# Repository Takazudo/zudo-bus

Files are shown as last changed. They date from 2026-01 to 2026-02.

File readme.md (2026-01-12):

# Eurorack Bus Board (zudo-bus)

A bus board for distributing power from USB-PD power supply to Eurorack modular synthesizer modules.

## Documentation

**Main documentation is in the `/doc/` Docusaurus site**

```bash
cd doc
pnpm install
pnpm start
```

Open http://localhost:3333 in your browser to view the documentation.

## Project Overview

### Design Goals

Bus board for distributing power from zudo-pd USB-PD power supply to Eurorack modules.

- **Input**: Screw terminal connection (+12V, -12V, +5V, GND)
- **Output**: Multiple 16-pin IDC headers (Eurorack standard)
- **Capacity**: 8-12 module connections
- **Indicators**: LED status for each power rail

### Features

1. **Screw Terminal Input** - Easy connection from USB-PD power supply
2. **Multiple IDC Headers** - Standard Eurorack 16-pin connectors
3. **Per-Rail Protection** - Reverse polarity and overcurrent protection
4. **Visual Feedback** - LED indicators for power status
5. **JLCPCB Compatible** - All parts available from JLCPCB

## Repository Structure

- `/doc/` - Docusaurus documentation site **<- Main documentation**
- `/__inbox/` - Working directory (gitignored, temporary files)

## Related Projects

- [zudo-pd](https://github.com/Takazudo/zudo-pd) - USB-PD power supply that powers this bus board

## License

This project is open source. Hardware design files are free to use and modify.

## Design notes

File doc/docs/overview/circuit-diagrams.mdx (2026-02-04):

---
sidebar_position: 3
---

# Circuit Diagrams

Complete circuit configuration shown in stages. Each diagram represents a functional block of the zudo-bus power distribution board.

## Power Flow Overview

This diagram shows the complete power distribution chain from input terminals to IDC module headers, including the relationship between all circuit diagrams.

```mermaid
flowchart TD
    IN["Power Input
    Diagram1
    P1, P2 Screw Terminals"]

    PROT12["Protection +12V
    Diagram2
    F1 → D1 TVS → D2"]

    PROTN12["Protection -12V
    Diagram3
    F2 → D3 TVS → D4"]

    PROT5["Protection +5V
    Diagram4
    F3 → D5 TVS → D6"]

    SEL5["+5V Selection
    Diagram5
    U1, D7/D8, JP1, F4"]

    DIST["Chaining Output
    Diagram6
    P3, P4, P5, P6 FASTON"]

    IDC["IDC Headers
    Diagram7
    J101-J108 + Caps"]

    LED["Status LEDs
    Diagram8
    LED1-3 + R1-3"]

    TP["Test Points
    Diagram9
    TP1-TP6"]

    OUT1["+12V to Modules"]
    OUT2["-12V to Modules"]
    OUT3["+5V to Modules"]

    IN -->|"+12V"| PROT12
    IN -->|"-12V"| PROTN12
    IN -->|"+5V PSU"| PROT5
    IN -->|"+12V"| SEL5

    PROT12 --> IDC
    PROTN12 --> IDC
    PROT5 --> SEL5
    SEL5 --> IDC

    PROT12 --> DIST
    PROTN12 --> DIST
    SEL5 --> DIST

    IDC --> OUT1
    IDC --> OUT2
    IDC --> OUT3

    PROT12 --> LED
    PROTN12 --> LED
    SEL5 --> LED

    PROT12 --> TP
    PROTN12 --> TP
    PROT5 --> TP
    SEL5 --> TP
```

**Power Distribution Strategy:**

- **+12V rail**: Input → PTC F1 → TVS D1 → Reverse D2 → Distribution → IDC Headers
- **-12V rail**: Input → PTC F2 → TVS D3 → Reverse D4 → Distribution → IDC Headers
- **+5V PSU path**: Input → PTC F3 → TVS D5 → Reverse D6 → `+5V PSU` → OR-ing D8 → JP1 → F4 → `+5V rail`
- **+5V LDO path**: `+12V rail` → U1 LDO → OR-ing D7 → JP1 → F4 → `+5V rail`

## Schematic File Structure

The KiCad schematic is organized as a hierarchical design with separate sheets for clarity:

| Sheet File | Contents | Diagrams |
| --- | --- | --- |
| `zudo-bus.kicad_sch` | Top-level sheet with hierarchical blocks | - |
| `in-out.kicad_sch` | Input, protection, LDO, chaining | 1, 2, 3, 4, 5, 6 |
| `rail.kicad_sch` | IDC headers and decoupling capacitors | 7 |

**Hierarchical Labels** connect the sheets via power rails:

- `-12V rail` - Protected -12V distribution
- `GND` - System ground
- `+12V rail` - Protected +12V distribution
- `+5V rail` - Selected +5V (after jumper)

## Diagram1: Power Input Section

Screw terminals P1 and P2 receive power from the external PSU (zudo-pd or other Eurorack PSU).

```
Power Input Terminals:

P1 (5.08mm Screw Terminal - 2 positions):
┌─────────────────────────────────────┐
│  Pin 1: GND ────────────────────────┼──→ System GND
│  Pin 2: -12V input ─────────────────┼──→ To Protection (Diagram3)
└─────────────────────────────────────┘

P2 (5.08mm Screw Terminal - 2 positions):
┌─────────────────────────────────────┐
│  Pin 1: +5V input ──────────────────┼──→ To Protection (Diagram4)
│  Pin 2: +12V input ─────────────────┼──→ To Protection (Diagram2)
└─────────────────────────────────────┘
```

<details>
<summary>Connection List</summary>

**Components:**

| Ref | Part | Description | KiCad Symbol |
| --- | --- | --- | --- |
| P1  | 5.08mm Screw Terminal 2P | -12V and GND input | zudo-bus:WJ500V-5.08-2P-14-00A |
| P2  | 5.08mm Screw Terminal 2P | +12V and +5V input | zudo-bus:WJ500V-5.08-2P-14-00A |

**Net Connections:**

| Component | Pin | Net | Description |
| --- | --- | --- | --- |
| P1 | 1 | GND | System ground |
| P1 | 2 | -12V in | To F2 (Diagram3) |
| P2 | 1 | +5V in  | To F3 (Diagram4) |
| P2 | 2 | +12V in | To F1 (Diagram2) |

</details>

## Diagram2: +12V Protection Path

The +12V rail protection consists of a PTC fuse, TVS clamp diode, and reverse polarity diode in series.

```
+12V Protection Path:

+12V in ──► F1 ──┬──► D2 ──► +12V rail
(from P2)   PTC  │   SM4007
            2A   │   reverse protect
            hold │
                 └── D1 (TVS) ── GND
                     SMF12CA
                     clamp @19.9V
```

<details>
<summary>Connection List</summary>

**Components:**

| Ref | Part | Description |
| --- | --- | --- |
| F1  | BSMD1812-200-30V | PTC fuse, 2A hold, 4A trip |
| D1  | SMF12CA | TVS diode, 12V standoff, clamps @19.9V |
| D2  | SM4007PL | 1N4007 equivalent, reverse protection  |

**Connections:**

| Component | Pin | Net | Description |
| --- | --- | --- | --- |
| F1 | 1 | +12V in | From P2 Pin 2 |
| F1 | 2 | (junction) | To D1 and D2 |
| D1 | A1  | (junction) | TVS clamp |
| D1 | A2  | GND | TVS to ground |
| D2 | 2 | (junction) | Anode from F1 |
| D2 | 1 | +12V rail  | Cathode to rail |

</details>

## Diagram3: -12V Protection Path

The -12V rail uses the same protection topology as +12V but with appropriate polarity.

```
-12V Protection Path:

-12V in ──► F2 ──┬──► D4 ──► -12V rail
(from P1)   PTC  │   SM4007
            2A   │   reverse protect
            hold │   (REVERSED polarity)
                 └── D3 (TVS) ── GND
                     SMF12CA
                     clamp @19.9V

Note: D4 is oriented OPPOSITE to D2 (+12V path).
      Cathode at input, Anode at rail.
```

<details>
<summary>Connection List</summary>

**Components:**

| Ref | Part | Description |
| --- | --- | --- |
| F2  | BSMD1812-200-30V | PTC fuse, 2A hold, 4A trip |
| D3  | SMF12CA | TVS diode, 12V standoff, clamps @19.9V |
| D4  | SM4007PL | 1N4007 equivalent, reverse protection  |

**Connections:**

| Component | Pin | Net | Description |
| --- | --- | --- | --- |
| F2 | 1 | -12V in | From P1 Pin 2 |
| F2 | 2 | (junction) | To D3 and D4 |
| D3 | A1  | (junction) | TVS clamp |
| D3 | A2  | GND | TVS to ground |
| D4 | 1 | (junction) | Cathode from F2 (note!)  |
| D4 | 2 | -12V rail  | Anode to rail (reversed) |

</details>

## Diagram4: +5V Protection Path (PSU Direct)

When using PSU-provided +5V (not LDO), this protection path is active.

```
+5V Protection Path:

+5V in ──► F3 ──┬──► D6 ──► +5V PSU
(from P2)  PTC  │   SM4007
           1.5A │   reverse protect
           hold │
                └── D5 (TVS) ── GND
                    SMF5.0CA
                    clamp @9.2V

Then to +5V selection (Diagram5):
+5V PSU ──► Schottky OR-ing ──► H1 jumper ──► +5V rail
```

<details>
<summary>Connection List</summary>

**Components:**

| Ref | Part | Description |
| --- | --- | --- |
| F3  | BSMD1812-150-33V | PTC fuse, 1.5A hold |
| D5  | SMF5.0CA | TVS diode, 5V standoff, clamps @9.2V |
| D6  | SM4007PL | Reverse protection |

**Connections:**

| Component | Pin | Net | Description |
| --- | --- | --- | --- |
| F3 | 1 | +5V in | From P2 Pin 1 |
| F3 | 2 | (junction) | To D5 and D6 |
| D5 | A1  | (junction) | TVS clamp |
| D5 | A2  | GND | TVS to ground |
| D6 | 2 | (junction) | Anode from F3 |
| D6 | 1 | +5V PSU | Cathode to OR-ing |

</details>

## Diagram5: +5V Selection (LDO and Jumper)

The +5V rail can be sourced from either:

1. On-board LDO (from +12V via U1)
2. External PSU direct (+5V PSU from Diagram4)

Schottky diodes D7 and D8 form OR-ing protection to prevent backfeed. F4 provides output protection for the +5V rail.

```
+5V Source Selection:

                        +5V Selection with OR-ing

+12V rail ──► U1 ──┬──► D7 (SS14) ──┐
             LDO   │    Schottky    │
             5V    │    cathode     │
                   │                ├──► JP1 ──► F4 ──► +5V rail
             C1    C2 (22µF)        │   Jumper   PTC
             10µF  to GND           │            1.1A
             to GND                 │
                                    │
+5V PSU ───────────► D8 (SS14) ─────┘
(from Diagram4)      Schottky
                     cathode

U1 (AMS1117-5.0):
- Pin 3 (VI): Input from +12V rail
- Pin 2 (VO): +5V output to D7
- Pin 1 (GND): Ground

JP1 Jumper (1x3 Header):
┌─────┐
│  1  │ LDO +5V output (via D7)
│  2  │ To F4 (+5V rail output)
│  3  │ PSU +5V (via D8)
└─────┘

Jumper positions:
- 1-2: Use LDO (on-board 5V from 12V)
- 2-3: Use PSU direct +5V

F4 (Output Protection):
- Placed after JP1, before +5V rail
- Protects +5V distribution from module shorts
- Works for both LDO and PSU sources

OR-ing Diodes (D7, D8):
- Prevent backfeed between LDO and PSU
- Allow safe operation with any jumper configuration
- ~0.55V forward drop (Schottky)
```

<details>
<summary>Connection List</summary>

**Components:**

| Ref | Part | Description |
| --- | --- | --- |
| U1  | AMS1117-5.0 | +5V LDO regulator (1A max) |
| C1  | 10µF | LDO input capacitor |
| C2  | 22µF | LDO output capacitor (required) |
| D7  | SS14 | Schottky diode, LDO output OR-ing  |
| D8  | SS14 | Schottky diode, PSU +5V OR-ing |
| JP1 | Header 1x3 | +5V source selection jumper |
| F4  | BSMD1812-110-33V | PTC fuse 1.1A, +5V rail protection |

**Connections:**

| Component | Pin | Net | Description |
| --- | --- | --- | --- |
| U1 | 3 | +12V rail | VI from protected rail |
| U1 | 2 | (node) | VO to D7 |
| U1 | 1 | GND | Ground |
| C1 | 1 | +12V rail | At U1 VI |
| C1 | 2 | GND | Decoupling |
| C2 | 1 | (node) | At U1 VO |
| C2 | 2 | GND | Stability (required) |
| D7 | 2 | (node) | Anode from U1 VO |
| D7 | 1 | (node) | Cathode to JP1 pin 1 |
| D8 | 2 | +5V PSU | Anode from Diagram4 |
| D8 | 1 | (node) | Cathode to JP1 pin 3 |
| JP1 | 1 | (node) | LDO output via D7 |
| JP1 | 2 | (node) | To F4 input |
| JP1 | 3 | (node) | PSU +5V via D8 |
| F4 | 1 | (node) | From JP1 pin 2 |
| F4 | 2 | +5V rail  | To distribution |

</details>

## Diagram6: Bus Board Chaining (FASTON Connectors)

FASTON 250 terminals allow daisy-chaining multiple bus boards or parallel power input.

```
Bus Board Chaining (Input Side):

-12V in ──────► P3 ──────► To/from another bus board -12V
GND     ──────► P4 ──────► To/from another bus board GND
+12V in ──────► P5 ──────► To/from another bus board +12V
+5V in  ──────► P6 ──────► To/from another bus board +5V

FASTON 250 terminals (1217754-1):
- Quick connect/disconnect for modular expansion
- 7A rated per terminal
- Compatible with standard 6.3mm FASTON receptacles
- Connected to input nets (each board has its own protection)
```

<details>
<summary>Connection List</summary>

**Components:**

| Ref | Part | Description |
| --- | --- | --- |
| P3  | 1217754-1 | -12V chain (FASTON) |
| P4  | 1217754-1 | GND chain (FASTON)  |
| P5  | 1217754-1 | +12V chain (FASTON) |
| P6  | 1217754-1 | +5V chain (FASTON)  |

**Connections:**

| Component | Pin | Net | Description |
| --- | --- | --- | --- |
| P3 | 1 | -12V in | To next bus board -12V |
| P4 | 1 | GND | To next bus board GND  |
| P5 | 1 | +12V in | To next bus board +12V |
| P6 | 1 | +5V in  | To next bus board +5V  |

</details>

## Diagram7: IDC Headers and Decoupling

8 IDC headers (J101-J108) provide power to Eurorack modules. Each header has dedicated decoupling capacitors.

```
Component Numbering Scheme:

J1XX = IDC headers         (J101, J102, J103...)
C1XX = -12V decoupling     (C101, C102, C103... matches header)
C2XX = +12V decoupling     (C201, C202, C203... matches header)

Example - IDC Unit 1:
┌─────────────────────────────────────────────────────┐
│  J101 (IDC header)                                  │
│  C101 (0.1µF) - -12V decoupling                     │
│  C201 (0.1µF) - +12V decoupling                     │
└─────────────────────────────────────────────────────┘

Each IDC Header (2541WR-2X08P, 16-pin):
┌─────────────────────────────────────┐
│  Pins 1-2:   -12V                   │
│  Pins 3-8:   GND (x6)               │
│  Pins 9-12:  +12V (x4)              │
│  Pins 13-14: +5V (x2)               │
│  Pins 15-16: CV/GATE (optional)     │
└─────────────────────────────────────┘

Decoupling per header:

-12V rail ──┬── C1XX (0.1µF) ── GND
            └── To IDC pins 1-2

+12V rail ──┬── C2XX (0.1µF) ── GND
            └── To IDC pins 9-12
```

<details>
<summary>Connection List</summary>

**Components:**

| Ref | Part | Description |
| --- | --- | --- |
| J101-108 | 2541WR-2X08P | IDC header 16-pin |
| C101-108 | CC0603KRX7R9BB104 | 0.1µF -12V decoupling |
| C201-208 | CC0603KRX7R9BB104 | 0.1µF +12V decoupling |

**Component Assignment (per unit):**

| Unit | Header | -12V Cap | +12V Cap |
| ---- | --- | --- | --- |
| 1 | J101 | C101 | C201 |
| 2 | J102 | C102 | C202 |
| 3 | J103 | C103 | C203 |
| 4 | J104 | C104 | C204 |
| 5 | J105 | C105 | C205 |
| 6 | J106 | C106 | C206 |
| 7 | J107 | C107 | C207 |
| 8 | J108 | C108 | C208 |

**IDC Pin Connections (each header):**

- `Pins 1, 2` → `-12V rail`
- `Pins 3, 4, 5, 6, 7, 8` → `GND`
- `Pins 9, 10, 11, 12` → `+12V rail`
- `Pins 13, 14` → `+5V rail`
- `Pins 15, 16` → `CV rail`, `GATE rail` (optional)

</details>

## Diagram8: Status LED Circuit

Three LEDs indicate power rail status - one for each rail.

```
Status LEDs:

-12V rail ──► R1 (1kΩ) ──► LED1 (Red) ──► GND
              │
              └── -12V indicator (~10mA)

+12V rail ──► R2 (1kΩ) ──► LED2 (Green) ──► GND
              │
              └── +12V indicator (~10mA)

+5V rail  ──► R3 (1kΩ) ──► LED3 (Blue) ──► GND
              │
              └── +5V indicator (~2mA)

LED Colors:
- LED1 (Red):   -12V active
- LED2 (Green): +12V active
- LED3 (Blue):  +5V active

Current limiting:
- R1, R2: (12V - 2V) / 1kΩ ≈ 10mA
- R3: (5V - 3V) / 1kΩ ≈ 2mA
```

<details>
<summary>Connection List</summary>

**Components:**

| Ref  | Part | Description |
| ---- | --- | --- |
| LED1 | KT-0603R | Red LED (-12V) |
| LED2 | YLED0603YG | Green LED (+12V) |
| LED3 | NCD1608A1 | Blue LED (+5V) |
| R1 | RC0603FR-071K | 1kΩ for LED1 |
| R2 | RC0603FR-071K | 1kΩ for LED2 |
| R3 | RC0603FR-071K | 1kΩ for LED3 |

**Connections:**

| Component | Pin | Net | Description |
| --- | --- | --- | --- |
| R1 | 1 | -12V rail | Current limiting input |
| R1 | 2 | (node) | To LED1 anode |
| LED1 | Anode | (node) | From R1 |
| LED1 | Cathode | GND | To ground |
| R2 | 1 | +12V rail | Current limiting input |
| R2 | 2 | (node) | To LED2 anode |
| LED2 | Anode | (node) | From R2 |
| LED2 | Cathode | GND | To ground |
| R3 | 1 | +5V rail  | Current limiting input |
| R3 | 2 | (node) | To LED3 anode |
| LED3 | Anode | (node) | From R3 |
| LED3 | Cathode | GND | To ground |

</details>

## Diagram9: Test Points

Test points are placed on key nodes for debugging and verification during board bring-up.

```
Test Point Locations:

+12V in ──► F1 ──► D1 ──► D2 ──●──► +12V rail
                              │
                             TP1 (TestPoint +12V Rail)

-12V in ──► F2 ──► D3 ──► D4 ──●──► -12V rail
                              │
                             TP2 (TestPoint -12V Rail)

+5V in ──► F3 ──► D5 ──► D6 ──●──► +5V PSU
                              │
                             TP3 (TestPoint +5V IN)

+12V rail ──► U1 ──●──► D7 ──► JP1 ──●──► F4 ──► +5V rail
             LDO  │           pin 1   │
                  │                   │
                 TP4                 TP5
          (TestPoint LDO +5V)  (TestPoint +5V Rail)

GND ──●──► GND distribution
      │
     TP6 (TestPoint GND)
```

<details>
<summary>Test Point Details</summary>

**Components:**

| Ref | Location | Purpose |
| --- | --- | --- |
| TP1 | +12V rail (after D2) | Verify +12V protection output |
| TP2 | -12V rail (after D4) | Verify -12V protection output |
| TP3 | +5V PSU (after D6, before D8) | Verify +5V PSU input before source selection |
| TP4 | U1 output (before D7) | Verify LDO +5V output directly |
| TP5 | JP1 pin 2 (before F4) | Verify +5V after source selection |
| TP6 | GND | Ground reference for all measurements |

**Usage:**

- Compare TP3 vs TP4 to verify which +5V source is active
- TP5 shows +5V after jumper selection but before output fuse F4
- Always use TP6 as ground reference for accurate measurements

</details>

## Component Summary

### All Components by Diagram

| Diagram  | Components |
| --- | --- |
| Diagram1 | P1, P2 |
| Diagram2 | F1, D1 (TVS), D2, TP1 |
| Diagram3 | F2, D3 (TVS), D4, TP2 |
| Diagram4 | F3, D5 (TVS), D6, TP3 |
| Diagram5 | U1, C1, C2, D7, D8, JP1, F4, TP4, TP5 |
| Diagram6 | P3, P4, P5, P6 (FASTON) |
| Diagram7 | J101-J108, C101-C208 |
| Diagram8 | LED1-3, R1-R3 |
| Diagram9 | TP1-TP6 (Test Points) |

### Net Names

| Net | Description |
| --- | --- |
| +12V in | Input from PSU before protection |
| -12V in | Input from PSU before protection |
| +5V in | Input from PSU before protection |
| +12V rail | Protected +12V distribution |
| -12V rail | Protected -12V distribution |
| +5V PSU | Protected PSU +5V (before OR-ing) |
| +5V LDO | LDO output (before OR-ing) |
| +5V rail  | Selected +5V (after jumper selection) |
| GND | System ground |
| CV rail | Optional CV bus |
| GATE rail | Optional GATE bus |

## See Also

- [Technical Overview](./overview.md) - Design rationale
- [Bill of Materials](./bom.md) - Component list
- [Current Status](../inbox/current-status.md) - Detailed connection list

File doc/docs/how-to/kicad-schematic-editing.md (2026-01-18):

# KiCad Schematic File Editing

Guide for programmatically editing KiCad schematic files (`.kicad_sch`) to add connections, labels, and wires.

## File Format Overview

KiCad schematic files use S-expression format (similar to Lisp). The main structure:

```lisp
(kicad_sch
  (version 20231120)
  (generator "eeschema")
  (uuid "...")
  (paper "A4")

  ;; Symbols (components)
  (symbol ...)
  (symbol ...)

  ;; Wires (electrical connections)
  (wire ...)
  (wire ...)

  ;; Labels (net names)
  (global_label ...)
  (label ...)

  ;; Sheet instances
  (sheet_instances ...)
)
```

## Wires

Wires create electrical connections between two points. Use wires to connect component pins directly.

### Wire Format

```lisp
(wire
    (pts
        (xy 97.79 146.05) (xy 82.55 146.05)
    )
    (stroke
        (width 0)
        (type default)
    )
    (uuid "047906c0-c725-48f6-bfd2-ae993df4b46b")
)
```

### Wire Properties

| Property | Description |
| --- | --- |
| `pts` | Two `(xy X Y)` coordinates defining start and end points |
| `stroke.width` | Line width (0 = default width) |
| `stroke.type`  | Line type (`default`, `dash`, `dot`, etc.) |
| `uuid` | Unique identifier for the wire |

### Wire Example

Connect two points at (100, 50) and (150, 50):

```lisp
(wire
    (pts
        (xy 100 50) (xy 150 50)
    )
    (stroke
        (width 0)
        (type default)
    )
    (uuid "a1b2c3d4-e5f6-7890-abcd-ef1234567890")
)
```

## Global Labels

Global labels connect nets by name across the entire schematic. Components with the same label name are electrically connected.

### Global Label Format

```lisp
(global_label "GND rail"
    (shape input)
    (at 78.74 219.71 0)
    (effects
        (font
            (size 1.27 1.27)
        )
        (justify left)
    )
    (uuid "g0000001-0001-0001-0001-000000000001")
    (property "Intersheetrefs" "${INTERSHEET_REFS}"
        (at 78.74 219.71 0)
        (effects
            (font
                (size 1.27 1.27)
            )
            (hide yes)
        )
    )
)
```

### Global Label Properties

| Property | Description |
| --- | --- |
| Name (first string) | Net name (e.g., "GND rail", "+12V rail") |
| `shape` | Label shape: `input`, `output`, `bidirectional`, `tri_state`, `passive` |
| `at` | Position `(at X Y rotation)` - rotation in degrees |
| `effects.font.size` | Font size (width height) |
| `effects.justify` | Text justification (`left`, `right`, `center`) |
| `uuid` | Unique identifier |
| `property "Intersheetrefs"` | Inter-sheet reference display |

### Shape Selection Guide

| Shape | Use Case |
| --- | --- |
| `input` | Power input pins, signal inputs |
| `output` | Power output pins, signal outputs |
| `bidirectional` | I/O pins, data buses |
| `passive` | Passive components (R, C, L) |

## Local Labels

Local labels connect nets within the same sheet only.

### Local Label Format

```lisp
(label "FB"
    (at 150 75 0)
    (effects
        (font
            (size 1.27 1.27)
        )
        (justify left)
    )
    (uuid "l1234567-89ab-cdef-0123-456789abcdef")
)
```

## Power Symbols

Power symbols represent power nets (VCC, GND, etc.) and are special global labels.

### Power Symbol Format

```lisp
(symbol
    (lib_id "power:GND")
    (at 100 150 0)
    (unit 1)
    (exclude_from_sim no)
    (in_bom yes)
    (on_board yes)
    (uuid "p1234567-89ab-cdef-0123-456789abcdef")
    (property "Reference" "#PWR01"
        (at 100 156.21 0)
        (effects
            (font
                (size 1.27 1.27)
            )
            (hide yes)
        )
    )
    (property "Value" "GND"
        (at 100 153.67 0)
        (effects
            (font
                (size 1.27 1.27)
            )
        )
    )
    ;; ... more properties
)
```

## Symbol Positioning

Symbols (components) can be repositioned by modifying their `(at X Y rotation)` property.

### Symbol Format

```lisp
(symbol
    (lib_id "zudo-bus:CC0603KRX7R9BB104")
    (at 100 150 0)          ;; Position: X=100mm, Y=150mm, rotation=0°
    (unit 1)
    (exclude_from_sim no)
    (in_bom yes)
    (on_board yes)
    (dnp no)
    (fields_autoplaced yes) ;; KiCad auto-positions labels
    (uuid "...")
    (property "Reference" "C1"
        (at 100 143.65 0)   ;; Reference label position
        ...
    )
    (property "Value" "..."
        (at 100 146.19 0)   ;; Value label position
        ...
    )
    ;; ... more properties
    (pin "1" (uuid "..."))
    (pin "2" (uuid "..."))
    (instances ...)
)
```

### Symbol Position Properties

| Property | Description |
| --- | --- |
| `at` (main) | Symbol center position `(at X Y rotation)` |
| `rotation` | 0, 90, 180, or 270 degrees |
| `fields_autoplaced` | `yes` = KiCad auto-positions labels relative to symbol  |
| Property `at` | Each property (Reference, Value, etc.) has own position |

### Rotation Values

| Rotation | Description | Pin orientation |
| --- | --- | --- |
| 0 | Default orientation | Horizontal, pins left/right |
| 90 | 90° counter-clockwise | Vertical, pins up/down |
| 180 | Flipped horizontal | Horizontal, pins right/left |
| 270 | 90° clockwise | Vertical, pins down/up |

### Moving a Symbol

To move a symbol:

1. **Find the symbol** by its Reference or UUID
2. **Update the main `(at X Y rotation)`** line
3. **If `fields_autoplaced` is `yes`**: KiCad will recalculate label positions on load
4. **If `fields_autoplaced` is `no`**: Manually update each property's `(at ...)` position

### Example: Move C1 from (73.66, 219.71) to (100, 150)

Before:

```lisp
(symbol
    (lib_id "zudo-bus:CC0603KRX7R9BB104")
    (at 73.66 219.71 0)
    ...
)
```

After:

```lisp
(symbol
    (lib_id "zudo-bus:CC0603KRX7R9BB104")
    (at 100 150 0)
    ...
)
```

### Batch Repositioning Strategy

For reorganizing an entire schematic:

1. **Extract current positions**: Parse all symbols and their positions
2. **Design new layout**: Create a position map based on circuit blocks
3. **Calculate new positions**: Use grid-aligned coordinates (2.54mm grid recommended)
4. **Update symbols**: Modify `(at X Y rotation)` for each symbol
5. **Update all connected labels**: Move labels to new pin positions
6. **Verify in KiCad**: Open schematic and run ERC

**IMPORTANT: Labels must move with components**

Global labels connect to pins by **position**, not just by name. When moving a component:

- All labels connected to its pins must also move
- Calculate new pin positions: `new_pin = new_component_center + pin_offset`
- Pin offsets depend on symbol definition and rotation

**Recommendation**: For major layout reorganization, use KiCad's schematic editor directly. Manual drag-and-drop keeps connections intact. Programmatic repositioning is best for:

- Adding new components at specific positions
- Fine-tuning individual component positions
- Generating new schematics from scratch

### Grid Alignment

KiCad uses 2.54mm (100 mil) grid by default. Recommended positions:

```
Good: (100, 150), (102.54, 152.54), (50.8, 76.2)
Bad:  (100.5, 150.3), (101, 151)
```

Common grid values:

- 2.54mm = 100 mil (standard)
- 1.27mm = 50 mil (fine grid)
- 5.08mm = 200 mil (coarse grid)

## Coordinate System

- Origin (0, 0) is at top-left
- X increases to the right
- Y increases downward
- Units are millimeters (mm)
- ERC reports use mils (1 mil = 0.0254 mm)

### Converting ERC Mils to Schematic mm

```
mm = mils × 0.0254
```

Example: ERC position (3100, 8600) mils = (78.74, 218.44) mm

## Component Pin Positions

To find pin positions from component center:

1. Read the symbol definition from schematic or library
2. Find pin offset from symbol center
3. Calculate: `pin_position = component_center + pin_offset`

### Common Symbol Pin Offsets

**Capacitor (CC0603KRX7R9BB104):**

- Pin 1 (left): center_x - 5.08 mm
- Pin 2 (right): center_x + 5.08 mm

**Resistor (standard 0603/0805):**

- Pin 1 (left): center_x - 3.81 mm
- Pin 2 (right): center_x + 3.81 mm

## UUID Generation

Each element needs a unique UUID. Format: `xxxxxxxx-xxxx-xxxx-xxxx-xxxxxxxxxxxx`

Generate unique UUIDs for new elements. Common approaches:

- Use standard UUID v4 generation
- Create sequential UUIDs with prefix (e.g., `w0000001-...` for wires)

## Insertion Location

Add new elements before the `(sheet_instances` section at the end of the file:

```lisp
;; ... existing symbols ...

;; Add new wires here
(wire ...)
(wire ...)

;; Add new labels here
(global_label ...)
(global_label ...)

;; Keep this at the end
(sheet_instances
    (path "/" ...)
)
```

## Best Practices

1. **Back up before editing** - Save a copy of the schematic before programmatic edits

2. **Verify in KiCad** - Open the edited schematic in KiCad to verify changes

3. **Run ERC** - Run Electrical Rules Check after edits to verify connections

4. **Use consistent formatting** - Match indentation style of existing file

5. **Generate unique UUIDs** - Duplicate UUIDs cause KiCad errors

6. **Test incrementally** - Make small changes and verify before large batch edits

7. **Always use wires between pins and labels** - Never place labels directly on pins

### Wire Between Pin and Label Rule

**IMPORTANT**: Always add a short wire between component pins and labels.

**Wrong** - Label directly on pin:

```
[Pin]←Label    (label at exact pin position)
```

**Correct** - Wire connects pin to label:

```
[Pin]───────[Label]    (wire between pin and label)
```

Benefits:

- **Readable**: Clear visual connection between pin and net
- **Movable**: Components can be repositioned without breaking connections
- **Standard**: Follows conventional schematic design practice

Example wire + label for a capacitor pin:

```lisp
;; Wire from pin to label position (5mm offset)
(wire
    (pts
        (xy 94.92 200) (xy 89.84 200)  ;; 5.08mm wire
    )
    (stroke (width 0) (type default))
    (uuid "w1234567-...")
)
;; Label at end of wire
(global_label "+12V rail"
    (shape input)
    (at 89.84 200 180)  ;; At wire endpoint, pointing left
    ...
)
```

## Example: Connect Capacitor to Power Rail

Given capacitor C1 at position (100, 200) with pins at X ± 5.08mm:

- Pin 1 (left): (94.92, 200)
- Pin 2 (right): (105.08, 200)

```lisp
;; Wire from Pin 1 to label position (5mm left of pin)
(wire
    (pts
        (xy 94.92 200) (xy 89.84 200)
    )
    (stroke (width 0) (type default))
    (uuid "c1-p1-wire")
)

;; Label at end of wire, pointing left (180°)
(global_label "+12V rail"
    (shape input)
    (at 89.84 200 180)
    (effects
        (font
            (size 1.27 1.27)
        )
        (justify right)
    )
    (uuid "c1-p1-label")
    (property "Intersheetrefs" "${INTERSHEET_REFS}"
        (at 89.84 200 180)
        (effects
            (font
                (size 1.27 1.27)
            )
            (hide yes)
        )
    )
)

;; Wire from Pin 2 to label position (5mm right of pin)
(wire
    (pts
        (xy 105.08 200) (xy 110.16 200)
    )
    (stroke (width 0) (type default))
    (uuid "c1-p2-wire")
)

;; Label at end of wire, pointing right (0°)
(global_label "GND rail"
    (shape input)
    (at 110.16 200 0)
    (effects
        (font
            (size 1.27 1.27)
        )
        (justify left)
    )
    (uuid "c1-p2-label")
    (property "Intersheetrefs" "${INTERSHEET_REFS}"
        (at 110.16 200 0)
        (effects
            (font
                (size 1.27 1.27)
            )
            (hide yes)
        )
    )
)
```

## Schematic Layout Organization

Organize schematic components into logical blocks for readability.

### Recommended Layout Structure

```
┌─────────────────────────────────────────────────────────────────────┐
│                        SCHEMATIC LAYOUT                             │
│                                                                     │
│  TOP AREA (Y: 0-100mm)                                              │
│  ┌─────────────────────────────────────────────────────────────┐   │
│  │ PROTECTION CIRCUITS                                         │   │
│  │ - PTC Fuses (F1-F4)                                         │   │
│  │ - TVS Diodes (D1-D3)                                        │   │
│  │ - Reverse Diodes (D6-D9)                                    │   │
│  │ - Input Bulk Caps (C5, C6)                                  │   │
│  └─────────────────────────────────────────────────────────────┘   │
│                                                                     │
│  MIDDLE AREA (Y: 100-200mm)                                         │
│  ┌──────────────────────┐  ┌──────────────────────┐                │
│  │ LDO SECTION          │  │ INPUT CONNECTORS     │                │
│  │ - LDO U1             │  │ - FASTON U12-U15     │                │
│  │ - Caps C1-C4         │  │ - Screw P1, P2       │                │
│  │ - Schottky D4, D5    │  │                      │                │
│  │ - Jumper H1          │  │                      │                │
│  └──────────────────────┘  └──────────────────────┘                │
│                                                                     │
│  BOTTOM AREA (Y: 200-400mm)                                         │
│  ┌─────────────────────────────────────────────────────────────┐   │
│  │ IDC HEADERS (J1-J8) with decoupling capacitors (C7-C22)     │   │
│  │                                                             │   │
│  │  [J1+C7+C15] [J2+C8+C16] [J3+C9+C17] [J4+C10+C18]          │   │
│  │  [J5+C11+C19] [J6+C12+C20] [J7+C13+C21] [J8+C14+C22]       │   │
│  └─────────────────────────────────────────────────────────────┘   │
│                                                                     │
│  INDICATORS & TEST POINTS (Right side)                              │
│  ┌────────────────┐                                                │
│  │ LEDs + R1-R3   │                                                │
│  │ Test Points    │                                                │
│  └────────────────┘                                                │
└─────────────────────────────────────────────────────────────────────┘
```

### Signal Flow Direction

Arrange components following signal/power flow:

```
LEFT → RIGHT: Input → Protection → Distribution → Output

TOP → BOTTOM: Power sources → Regulation → Headers
```

### Spacing Guidelines

| Component Type | Horizontal Spacing | Vertical Spacing |
| --- | --- | --- |
| Small (0603 cap) | 15-20mm | 10-15mm |
| Medium (SOT-223) | 25-30mm | 20-25mm |
| Large (IDC 16p)  | 40-50mm | 30-40mm |
| Block separation | 30-50mm | 30-50mm |

### Position Calculation Example

For 8 IDC headers in 2 rows:

```
Base position: (50, 250)
Horizontal spacing: 45mm
Vertical spacing: 35mm

J1: (50, 250)     J2: (95, 250)    J3: (140, 250)   J4: (185, 250)
J5: (50, 285)     J6: (95, 285)    J7: (140, 285)   J8: (185, 285)
```

## Wiring Best Practices - Label Direction Rules

### Core Principle: Labels Point OUTWARD

For readable schematics, labels should extend **outward** from components, not overlap with them.

### Label Rotation Values

| Rotation | Direction | Arrow Points |
| --- | --- | --- |
| 0 | Points RIGHT | → |
| 180 | Points LEFT  | ← |
| 90 | Points UP | ↑ |
| 270 | Points DOWN  | ↓ |

### Component Type Wiring Patterns

#### 1. Two-Pin Horizontal Components (LEDs, Resistors, Diodes, PTC Fuses)

Both pins on same Y axis - labels extend outward from both sides:

```
[← Left Label]───[Pin1]═══[Component]═══[Pin2]───[Right Label →]
```

| Pin | Label Direction | Rotation |
| --- | --- | --- |
| Pin 1 (left)  | Points LEFT | 180 |
| Pin 2 (right) | Points RIGHT | 0 |

**Example - LED (LED1):**

```
[LED1_R1 ←]───[Pin1]═══[LED1]═══[Pin2]───[→ GND rail]
```

**Example - PTC Fuse (F3):**

```
[+5V in ←]───[Pin1]═══[F3]═══[Pin2]───[→ +5V rail]
```

#### 2. Single-Pin Connectors (FASTON Terminals)

FASTON 1217754-1 is a quick-connect terminal. Label points toward the input side:

```
[← Input Label]───[Pin]═══[FASTON]
```

| Pin | Label Direction | Rotation |
| ----- | --- | --- |
| Pin 1 | Points LEFT | 180 |

**Example - FASTON U12 (+12V input):**

```
[+12V in ←]───[Pin1]═══[U12]
```

**Note:** If FASTON has 2 pins (input/output), apply the 2-pin horizontal pattern.

#### 3. Two-Pin Connectors (FASTON with 2 pins)

If the FASTON or similar connector has both input and output pins:

```
[← Input Label]───[Pin1]═══[FASTON]═══[Pin2]───[Output Label →]
```

**Example - 2-pin FASTON for power distribution:**

```
[+12V in ←]───[Pin1]═══[U12]═══[Pin2]───[→ +12V rail]
```

#### 4. Multi-Pin Headers with Pins on One Side (H1, IDC Headers)

Headers with all pins on one side - all labels point away from component body:

```
                    ┌─────────────┐
[← LDO out]─────────┤ Pin 1       │
[← +5V rail]────────┤ Pin 2   H1  │
[← +5V in]──────────┤ Pin 3       │
                    └─────────────┘
```

| Pin Side | Label Direction | Rotation |
| --- | --- | --- |
| Left | Points LEFT | 180 |
| Right | Points RIGHT | 0 |

#### 5. Two-Pin Screw Terminals (P1, P2 - Vertical Wiring Pattern)

For 2-pin screw terminals with vertical wire routing, use this pattern:

```
           [Terminal]
             ┌────┐
             │1  2│
             └─┬──┘
               │
               │ ← Vertical wires go DOWN
               │
[← Left Label]─┴─[Right Label →]
```

| Pin | Label Direction | Rotation |
| --- | --- | --- |
| Pin 1 (left)  | Points LEFT | 180 |
| Pin 2 (right) | Points RIGHT | 0 |

**Example - P2 (-12V and GND screw terminal):**

```
             P2
           ┌────┐
           │1  2│
           └─┬──┘
             │
[← -12V in]──┴──[GND in →]
```

**Example - P1 (+12V and GND screw terminal):**

```
             P1
           ┌────┐
           │1  2│
           └─┬──┘
             │
[← +12V in]──┴──[GND in →]
```

**Key Points:**

- Both labels at the SAME Y level (below the terminal)
- Vertical wires from pins meet a horizontal bus
- Left label extends LEFT with rotation 180
- Right label extends RIGHT with rotation 0

#### 6. IDC Headers (16-pin Eurorack)

IDC headers have pins on both left and right sides:

```
                ┌─────────────────┐
[← -12V rail]───┤ Pin 1    Pin 9  ├───[→ -12V rail]
[← GND rail]────┤ Pin 2    Pin 10 ├───[→ GND rail]
[← GND rail]────┤ Pin 3    Pin 11 ├───[→ GND rail]
[← GND rail]────┤ Pin 4    Pin 12 ├───[→ GND rail]
[← +12V rail]───┤ Pin 5    Pin 13 ├───[→ +12V rail]
[← +5V rail]────┤ Pin 6    Pin 14 ├───[→ +5V rail]
[← CV rail]─────┤ Pin 7    Pin 15 ├───[→ CV rail]
[← GATE rail]───┤ Pin 8    Pin 16 ├───[→ GATE rail]
                └─────────────────┘
```

### Wire Length Standard

Use consistent wire length for visual clarity:

| Wire Type | Length | Purpose |
| --- | --- | --- |
| Pin to Label | 5.08mm | Standard connection |
| Component spacing | 2.54mm grid | Alignment |

### Label Position Calculation

For a component at position (X, Y):

**Left pin label (pointing left):**

```
pin_x = component_x - 5.08    (pin offset from center)
label_x = pin_x - 5.08        (5.08mm wire length)
wire: (pin_x, Y) → (label_x, Y)
label: (label_x, Y) rotation=180
```

**Right pin label (pointing right):**

```
pin_x = component_x + 5.08    (pin offset from center)
label_x = pin_x + 5.08        (5.08mm wire length)
wire: (pin_x, Y) → (label_x, Y)
label: (label_x, Y) rotation=0
```

### Common Mistakes to Avoid

#### 1. Labels Overlapping Components

**Wrong:**

```
[Label]═══[Component]═══[Label]
   ↑ Label at component position
```

**Correct:**

```
[Label]───[Pin]═══[Component]═══[Pin]───[Label]
             ↑ Wire separates label from component
```

#### 2. Adjacent Labels Same Direction

When multiple components are close together horizontally:

**Wrong:**

```
[A→]═[Comp1]═[B→]═[Comp2]═[C→]
       Labels B and C overlap!
```

**Correct:**

```
[←A]═[Comp1]═[B→]  [←C]═[Comp2]═[D→]
       Adequate spacing between components
```

#### 3. Duplicate Labels

Don't create duplicate labels when fixing orientation:

- **Replace** the existing label, don't add a new one
- Check label count before and after edits

### Fixing Overlapping Labels Checklist

1. **Identify the component type** (2-pin horizontal, FASTON, header, etc.)
2. **Determine correct label directions** based on pin positions
3. **Check for duplicates** - should only have ONE label per connection point
4. **Verify wire connections** - each label needs a wire to its pin
5. **Test in KiCad** - run ERC to verify electrical connections

### Quick Reference Table

| Component | Left Pin | Right Pin | Notes |
| --- | --- | --- | --- |
| LED, Resistor, Diode | ← (180)  | → (0) | 2-pin horizontal |
| PTC Fuse | ← (180)  | → (0) | 2-pin horizontal |
| TVS Diode | ← (180)  | → (0) | 2-pin horizontal |
| FASTON (1-pin) | ← (180)  | N/A | Single connection  |
| FASTON (2-pin) | ← (180)  | → (0) | Input/output |
| Header (pins left) | ← (180)  | N/A | All pins same side |
| Header (pins right)  | N/A | → (0) | All pins same side |
| IDC Header | ← (180)  | → (0) | Pins both sides |

## Flipping Label Direction (File Format)

When you need to change a label's pointing direction without moving its position, you must change THREE properties together:

### Label Direction Formula

| Visual Direction | rotation | justify | Intersheetrefs Position |
| --- | --- | --- | --- |
| Points LEFT ← | 0 | left | +5.08 (to RIGHT of label) |
| Points RIGHT → | 180 | right | -5.08 (to LEFT of label)  |

### Example: Flip Label from LEFT to RIGHT

**Before (pointing LEFT):**

```lisp
(global_label "+12V in"
    (shape input)
    (at 71.12 57.15 0)           ;; rotation 0
    (effects
        (font (size 1.27 1.27))
        (justify left)            ;; justify left
    )
    (uuid "...")
    (property "Intersheetrefs" "${INTERSHEET_REFS}"
        (at 76.2 57.15 0)         ;; 71.12 + 5.08 = to the RIGHT
        ...
    )
)
```

**After (pointing RIGHT):**

```lisp
(global_label "+12V in"
    (shape input)
    (at 71.12 57.15 180)         ;; rotation 180
    (effects
        (font (size 1.27 1.27))
        (justify right)           ;; justify right
    )
    (uuid "...")
    (property "Intersheetrefs" "${INTERSHEET_REFS}"
        (at 66.04 57.15 0)        ;; 71.12 - 5.08 = to the LEFT
        ...
    )
)
```

### Key Points

1. **All three changes are required** - changing only rotation or justify alone won't work correctly
2. **Intersheetrefs offset is always ±5.08mm** from the label position
3. **The label position (at X Y) stays the same** - only the direction flips
4. **Note the Intersheetrefs rotation stays 0** - only its position changes

### Quick Reference for Flipping

To flip **LEFT → RIGHT**:

- rotation: `0` → `180`
- justify: `left` → `right`
- Intersheetrefs X: `label_x + 5.08` → `label_x - 5.08`

To flip **RIGHT → LEFT**:

- rotation: `180` → `0`
- justify: `right` → `left`
- Intersheetrefs X: `label_x - 5.08` → `label_x + 5.08`

## References

- [KiCad File Formats Documentation](https://dev-docs.kicad.org/en/file-formats/)
- [KiCad S-Expression Specification](https://dev-docs.kicad.org/en/file-formats/sexpr-intro/)

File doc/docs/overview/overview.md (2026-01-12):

---
sidebar_position: 2
slug: project-overview
---

# Technical Overview

Technical specifications and design rationale for the zudo-bus board.

## System Architecture

```
                    ┌──────────────────────────────────────────────────┐
                    │              zudo-bus Board                      │
                    │                                                  │
From PSU ──────────►│  Input Section          Output Section          │
(FASTON or Screw)   │  ┌─────────┐           ┌─────────────┐          │
                    │  │ +12V IN │──────────►│ 16-pin IDC  │──► Module
                    │  │ -12V IN │──────────►│ Headers x8  │
                    │  │ GND  IN │──────────►│             │          │
                    │  │ +5V  IN │──┬───────►│             │          │
                    │  └─────────┘  │        └─────────────┘          │
                    │               │                                  │
                    │               │  ┌──────────────────┐           │
                    │               │  │ +5V LDO Section  │           │
                    │               │  │                  │           │
                    │  +12V ────────┼─►│ AMS1117 ─► +5V  │           │
                    │               │  │                  │           │
                    │               │  └────────┬─────────┘           │
                    │               │           │                      │
                    │               └───────────┤                      │
                    │                    3-pin  │                      │
                    │                   jumper  ▼                      │
                    │                  ┌───────────┐                   │
                    │                  │ SELECT    │                   │
                    │                  │ PSU / LDO │                   │
                    │                  └───────────┘                   │
                    └──────────────────────────────────────────────────┘
```

## +5V Selection Mechanism

The 3-pin header allows users to select the +5V source:

```
3-Pin Header Positions:
┌─────────────────────────────────────┐
│  Position 1-2: Use LDO output       │
│  (Generate +5V from +12V)           │
│                                     │
│  Position 2-3: Use PSU +5V          │
│  (Direct from power supply)         │
│                                     │
│  No jumper: +5V rail disabled       │
└─────────────────────────────────────┘

     +5V from LDO    +5V to modules    +5V from PSU
          │               │                │
          ▼               ▼                ▼
        ┌───┐           ┌───┐           ┌───┐
        │ 1 │───────────│ 2 │───────────│ 3 │
        └───┘           └───┘           └───┘
              ▲                   ▲
           Jumper              Jumper
           1-2                 2-3
```

## Design Rationale

### Dual Input Connectors

**FASTON terminals:**

- Same connector as zudo-pd PSU output
- Quick connect/disconnect
- Industrial reliability
- Requires one-side FASTON cables

**Screw terminals:**

- Easy to use with bare wire
- No special cables needed
- User-friendly for DIY builders
- Good for permanent installations

### +5V Generation

Most Eurorack modules only need ±12V. The +5V rail is optional and mainly used by:

- Digital modules with 5V logic
- Some older module designs
- Specific manufacturer requirements

By generating +5V on the bus board:

- Reduces load on PSU +5V rail
- Simpler cable requirements (only 3 wires from PSU)
- Can be disabled if not needed

### Component Selection

All components selected for:

- JLCPCB SMT assembly availability
- Adequate current ratings
- Thermal performance
- Cost effectiveness

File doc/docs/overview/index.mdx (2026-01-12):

---
sidebar_position: 1
pagination_next: null
pagination_prev: null
---

import CategoryNav from '@site/src/components/CategoryNav';

# Overview

Documentation for Eurorack bus board with +5V generation capability.

## Project Features

### Power Distribution

- **Input Options**: FASTON terminals OR screw terminals (user choice)
- **Output**: Multiple 16-pin IDC headers for Eurorack modules
- **Chainability**: Both input types available for daisy-chaining multiple boards

### Power Rails

| Rail | Source | Notes |
| --- | --- | --- |
| **+12V** | Direct from PSU | Main positive rail |
| **-12V** | Direct from PSU | Main negative rail |
| **+5V**  | Generated from +12V OR direct | Selectable via 3-pin jumper |
| **GND**  | Common ground | Shared across all rails |

### Key Features

1. **Dual Input Connectors**
   - FASTON 250 terminals (same as zudo-pd PSU)
   - 5.08mm screw terminals (easy wire connection)
   - User can choose preferred connection method

2. **+5V Generation**
   - On-board LDO regulator (L78L05ABUTR)
   - Generated from +12V rail
   - 3-pin header with jumper for ON/OFF selection
   - Can bypass and use direct +5V from PSU

3. **Multiple IDC Outputs**
   - Standard 16-pin Eurorack power connectors
   - Shrouded headers for correct orientation
   - Quantity: 8 outputs (same as v1 design)

4. **JLCPCB Compatible**
   - All SMD parts available from JLCPCB
   - Through-hole connectors sourced separately

## Connection Options

```
From zudo-pd PSU:
┌─────────────────┐
│  FASTON Cable   │──→ FASTON terminals (quick connect)
│  (one-side)     │    OR
│                 │──→ Screw terminals (bare wire)
└─────────────────┘

To Modules:
┌─────────────────┐
│  16-pin ribbon  │──→ Module power header
│  cable          │
└─────────────────┘
```

## Pages in this category

<CategoryNav category="overview" />

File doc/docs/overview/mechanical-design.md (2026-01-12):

# Mechanical Design

PCB dimensions, mounting, and enclosure specifications for the zudo-bus board.

## PCB Specifications

_Content to be added._

## Mounting

_Content to be added._

## Connector Layout

_Content to be added._

## Enclosure Compatibility

_Content to be added._

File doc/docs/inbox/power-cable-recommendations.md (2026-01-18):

---
sidebar_position: 3
---

# Power Cable Recommendations

Guidelines for selecting appropriate cables to connect the zudo-pd PSU to the zudo-bus board.

## Recommended Wire Gauge

**18 AWG (0.82 mm²)** is recommended for all power connections between the PSU and bus board.

### Why 18 AWG?

| Parameter | 18 AWG Specification |
| --- | --- |
| **Current Capacity** | 16A (chassis wiring) / 7A (power transmission) |
| **Diameter** | 1.02 mm (bare conductor) |
| **Resistance** | ~21 mΩ/m |
| **Voltage Drop** | ~42 mV/m at 2A |

For typical Eurorack loads (1-2A per rail), 18 AWG provides:

- Adequate current handling with safety margin
- Low voltage drop over short distances
- Good flexibility for cable routing
- Wide availability and reasonable cost

### Current Requirements by Rail

| Rail | Typical Load | Max Load | 18 AWG Margin |
| ---- | --- | --- | --- |
| +12V | 0.5-1.5A | 2A | 8x headroom |
| -12V | 0.3-1.0A | 2A | 8x headroom |
| +5V  | 0-0.5A | 1.5A | 10x headroom  |
| GND  | Sum of above | ~4A | 4x headroom |

## Cable Construction

### Recommended Cable Types

1. **Silicone Wire (Preferred)**
   - Highly flexible
   - Temperature resistant (-60°C to +200°C)
   - Easy to route in tight spaces

2. **Stranded Copper Wire**
   - Good flexibility
   - Standard hookup wire is acceptable
   - Avoid solid core wire (poor flexibility)

### Color Coding (Recommended)

Follow standard DC power conventions:

| Rail | Color | Notes |
| ---- | --- | --- |
| +12V | Red or Yellow | Positive rail |
| -12V | Blue | Negative rail |
| +5V  | Orange | Optional rail |
| GND  | Black | Ground/return |

## Connection Types

### FASTON 250 Terminals

For FASTON connections to the bus board:

- Use **female FASTON 250** (6.3mm) crimp terminals
- Ensure proper crimp with appropriate tool
- Insulated terminals recommended

**Crimp Terminal Specifications:**

- Terminal size: 6.3mm width
- Wire range: 16-22 AWG (18 AWG fits well)
- Insulation: Optional but recommended

### Screw Terminals

For screw terminal connections:

- Strip approximately 6-7mm of insulation
- Tin the stripped wire end (optional but recommended)
- Tighten screw firmly but do not over-torque

## Cable Length

### Recommended Maximum Length

| Distance | Voltage Drop at 2A | Recommendation |
| --- | --- | --- |
| 0.3m (12") | ~25 mV | Excellent |
| 0.5m (20") | ~42 mV | Good |
| 1.0m (39") | ~84 mV | Acceptable |
| &gt;1.0m | &gt;84 mV | Use 16 AWG |

**Note:** Keep cables as short as practical. Longer cables increase resistance and potential for noise pickup.

### Voltage Drop Calculation

```
V_drop = I × R × L × 2

Where:
- I = Current (A)
- R = Resistance per meter (~21 mΩ/m for 18 AWG)
- L = Cable length (m)
- × 2 = Round trip (supply + return)

Example: 2A through 0.5m of 18 AWG
V_drop = 2A × 0.021 Ω/m × 0.5m × 2 = 42 mV
```

## Summary

| Parameter | Recommendation |
| --- | --- |
| **Wire Gauge**  | 18 AWG (0.82 mm²) |
| **Wire Type** | Stranded copper, silicone preferred |
| **Max Length**  | 1.0m (use 16 AWG for longer) |
| **Termination** | FASTON 250 or bare wire for screw terminals |

## Related

- [Technical Overview](/docs/overview/project-overview) - System architecture
- [Bill of Materials](/docs/overview/bom) - Connector specifications

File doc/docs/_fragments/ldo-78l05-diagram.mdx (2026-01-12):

{/* Fragment: AMS1117-5.0 +5V LDO Circuit Diagram */}

**Circuit Function:**

The +5V rail can be generated on-board from the +12V rail using the AMS1117-5.0 LDO (1A output), or passed through directly from the PSU via jumper selection.

```
Regulator IC:
                  ┌──────────────────┐
+12V IN ──────────┤3 INPUT     OUTPUT├──────────── LDO +5V OUT
                  │            (TAB)2│
               ┌──┤1 GND             │
               │  └──────────────────┘
              GND     AMS1117-5.0
                       (SOT-223)

Input Capacitors (C1 closest to IC):
+12V ──┬────────┬─── To IC Pin 3
       │        │
      C3       C1
     10µF    0.1µF
   ceramic  ceramic
       │        │
      GND      GND
   (farther) (CLOSE!)

Output Capacitors (C2 closest to IC):
From IC Pin 2 ──┬────────┬─── LDO +5V OUT
                │        │
               C2       C4
             22µF     0.1µF
            ceramic  ceramic
                │        │
               GND      GND
            (CLOSE!) (CLOSE!)

+5V Source Selection (JP1 3-Pin Header):
LDO +5V ─── Pin 1 ─┐
                   ├─ Jumper ─┐
PSU +5V ─── Pin 3 ─┘          │
                              │
                           Pin 2 ──→ To +5V Rail

Position 1-2: Use on-board LDO output
Position 2-3: Use PSU +5V directly
No jumper: +5V rail disabled
```

**Capacitor Placement (Critical for stability):**

- **C1 (0.1µF ceramic)**: Place RIGHT NEXT to IC pin 3 (high-frequency input decoupling)
- **C3 (10µF ceramic)**: Bulk input filtering, can be placed farther
- **C2 (22µF ceramic)**: Place RIGHT NEXT to IC pin 2 (output stability - CRITICAL for AMS1117)
- **C4 (0.1µF ceramic)**: High-frequency output decoupling

**Key Points:**

- **Output current**: 1A maximum (10x more than 78L05, adequate for multiple digital modules)
- **Dropout voltage**: ~1.2V typical (lower than 78L05's 2V)
- **Thermal consideration**: At 1A load from 12V, dissipates 7W - limit practical use to 300-500mA
- **Output capacitor**: AMS1117 requires low-ESR capacitor (22µF+ ceramic or tantalum) for stability

**Protection Circuit (+5V Rail):**

- **F4 (PTC 1.1A)**: LDO input overcurrent protection (symmetric protection)
- **D5, D6 (SS14 Schottky)**: OR-ing diodes to prevent backfeed between LDO and PSU sources
- **D3 (SM4007PL)**: Reverse polarity protection on PSU input path (JP1 Pin 3)
- **D4 (SM4007PL)**: Reverse polarity protection on LDO output path (JP1 Pin 1)
- **F3 (PTC 1.5A)**: Self-resetting overcurrent protection for +5V distribution
- **TVS3 (SMF5.0CA)**: Bidirectional TVS clamps transients to 9.2V max

**Protection Order:** `Input → PTC Fuse → TVS Diode → Reverse Diode → Bulk Caps → Distribution`

**Power Sequencing Note:** When using LDO mode (JP1 position 1-2), the +5V rail naturally sequences after ±12V since the AMS1117 requires stable +12V input before providing regulated output. This is beneficial for digital modules that expect analog supplies before digital.

See [AMS1117-5.0 Component Documentation](/docs/components/ams1117) for detailed specifications.

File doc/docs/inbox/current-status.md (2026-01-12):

---
sidebar_position: 2
---

# Current Status

Project status and circuit design plan for the bus board.

## Current Phase

**Circuit Design Planning** - Component selection complete, ready for schematic

## Completed

- Repository setup
- Documentation structure
- Component research and selection
- Old design analysis (zudo-bus v1/v2)

## Design Decisions Made

### Input Connectors

- **4x FASTON 250 terminals** - Same as zudo-pd PSU (+12V, -12V, +5V, GND)
- **4x 5.08mm screw terminals** - Alternative connection method
- User can choose preferred connection (chainable, flexible)

### Output Connectors

- **8x 16-pin IDC headers** - Standard Eurorack power
- Same quantity as old design v2

### +5V Generation

- **AMS1117-5.0 LDO** (1A, practical ~300mA) from +12V
- **3-pin jumper** for source selection:
  - Position 1-2: Use on-board LDO
  - Position 2-3: Use PSU +5V directly
  - No jumper: +5V disabled

### PCB Design

- **2-layer PCB** - Cost-effective design with good copper pours for thermal management

---

## Circuit Design Plan

### Block Diagram

```
                      zudo-bus Board
┌─────────────────────────────────────────────────────────────────┐
│                                                                 │
│  INPUT SECTION              DISTRIBUTION         OUTPUT SECTION │
│  ┌───────────┐                                  ┌────────────┐  │
│  │ FASTON x4 │──┐                           ┌──►│ IDC J1     │  │
│  │ +12V      │  │                           │   │ 16-pin     │  │
│  │ -12V      │  │     ┌─────────────────┐   │   ├────────────┤  │
│  │ +5V       │  ├────►│   Power Rails   │───┼──►│ IDC J2     │  │
│  │ GND       │  │     │   Distribution  │   │   ├────────────┤  │
│  └───────────┘  │     └─────────────────┘   │   │    ...     │  │
│                 │              │             │   ├────────────┤  │
│  ┌───────────┐  │              │             └──►│ IDC J8     │  │
│  │ Screw x4  │──┘              │                 └────────────┘  │
│  │ 5.08mm    │                 │                                 │
│  │ +12V      │                 ▼                                 │
│  │ -12V      │     ┌──────────────────────┐                     │
│  │ +5V       │     │  +5V LDO SECTION     │                     │
│  │ GND       │     │                      │                     │
│  └───────────┘     │  +12V ──► AMS1117 ─┐ │                     │
│                    │                    │ │                     │
│                    │    PSU +5V ────────┼─┼─► 3-pin jumper      │
│                    │                    │ │      │              │
│                    │    LDO +5V ────────┘ │      ▼              │
│                    └──────────────────────┘   +5V rail          │
│                                                                 │
│  INDICATORS        PROTECTION (Order: PTC → TVS → Diode → Caps) │
│  ┌─────────┐      ┌──────────────────────────────────────────┐ │
│  │ LED +12V│      │ PTC Fuses: F1(+12V 2A), F2(-12V 2A),     │ │
│  │ LED -12V│      │           F3(+5V 1.5A), F4(LDO 1.1A)     │ │
│  │ LED +5V │      │ TVS Clamp: TVS1/2(SMF12CA), TVS3(5V)     │ │
│  └─────────┘      │ Reverse: D1-D4 (SM4007PL)                │ │
│                   │ OR-ing: D5, D6 (SS14 Schottky)           │ │
│  FILTERING        └──────────────────────────────────────────┘ │
│  ┌─────────┐                                                   │
│  │C5,C6    │                                                   │
│  │22µF bulk│      DECOUPLING                                   │
│  │at input │      ┌──────────────────┐                         │
│  │         │      │ C7-C14: +12V 0.1µF│                        │
│  │C23 22µF │      │ C15-C22: -12V 0.1µF│                        │
│  │+5V rail │      │ per header x8     │                        │
│  └─────────┘      └──────────────────┘                         │
│                                                                │
│  TEST POINTS                                                   │
│  ┌─────────┐                                                   │
│  │TP1: +12V│                                                   │
│  │TP2: -12V│                                                   │
│  │TP3: +5V │                                                   │
│  │TP4: GND │                                                   │
│  │TP5: LDO │                                                   │
│  │   input │                                                   │
│  │TP6: LDO │                                                   │
│  │   output│                                                   │
│  └─────────┘                                                   │
└─────────────────────────────────────────────────────────────────┘
```

### +5V Selection Circuit Detail

```
                    +12V Rail
                        │
                        ▼
                   ┌───────────┐
                   │           │
                   │ AMS1117   │
                   │ 5.0 (1A)  │
                   │           │
              C1   └─────┬─────┘   C2
            0.1µF        │       22µF
              │          │         │
    GND ──────┴──────────┼─────────┴────── GND
                         │
                         │ LDO +5V Output
                         │
                         ▼
        ┌───────────────────────────────┐
        │         3-Pin Header          │
        │                               │
        │   LDO +5V    Rail    PSU +5V  │
        │      │         │         │    │
        │      ▼         ▼         ▼    │
        │    ┌───┐     ┌───┐     ┌───┐  │
        │    │ 1 │─────│ 2 │─────│ 3 │  │
        │    └───┘     └───┘     └───┘  │
        │         ▲         ▲           │
        │      Jumper    Jumper         │
        │       1-2       2-3           │
        └───────────────────────────────┘
                        │
                        ▼
                   +5V to IDC headers
```

### Component Connections

#### Power Input (FASTON + Screw parallel)

```
+12V:  FASTON J_F1 ──┬── Screw J_S1 ──► +12V Rail
-12V:  FASTON J_F2 ──┬── Screw J_S2 ──► -12V Rail
+5V:   FASTON J_F3 ──┬── Screw J_S3 ──► JP1 Pin 3
GND:   FASTON J_F4 ──┬── Screw J_S4 ──► GND Rail
```

#### +5V LDO Section

```
U1 (AMS1117-5.0):
  - Pin 1 (GND)    ← GND
  - Pin 2 (OUTPUT) → D6 (SS14) → JP1 Pin 1 (LDO output with OR-ing)
  - Pin 3 (INPUT)  ← F4 (1.1A PTC) ← +12V Rail
  - TAB (OUTPUT)   → Connected to Pin 2, thermal pad

F4 (BSMD1812-110): In series with LDO input, provides symmetric protection
D6 (SS14):         Schottky OR-ing diode, prevents backfeed into LDO

C1 (0.1µF):  INPUT to GND (high-frequency decoupling)
C2 (22µF):   OUTPUT to GND (output stability - CRITICAL for AMS1117)
C3 (10µF):   INPUT to GND (bulk input filtering)
C4 (0.1µF):  OUTPUT to GND (high-frequency output decoupling)
```

#### 3-Pin Jumper (JP1)

```
Pin 1: LDO +5V output (from U1 via D6 Schottky)
Pin 2: +5V Rail (to all IDC headers via F3)
Pin 3: PSU +5V input (from J_F3/J_S3 via D5 Schottky)

Jumper 1-2: Use LDO (generate +5V from +12V)
Jumper 2-3: Use PSU (direct +5V from power supply)

Note: D5 and D6 (SS14 Schottky) form an OR-ing configuration that
prevents backfeed between sources. Safe even if both are connected.
```

#### LED Indicators

```
LED1 (Red):    GND → LED1 (anode→cathode) → R1 (1kΩ) → -12V Rail
LED2 (Green):  +12V Rail → R2 (1kΩ) → LED2 (anode→cathode) → GND
LED3 (Blue):   +5V Rail  → R3 (1kΩ) → LED3 (anode→cathode) → GND
```

**LED Current Calculations (all using 1kΩ resistors, same as zudo-power-usb-pd):**

```
LED1 (Red, -12V):   I = (12V - 2V) / 1kΩ ≈ 10mA
LED2 (Green, +12V): I = (12V - 2V) / 1kΩ ≈ 10mA
LED3 (Blue, +5V):   I = (5V - 3V) / 1kΩ ≈ 2mA
```

**Note:** For the -12V indicator (LED1), current flows from GND (higher potential, 0V) through the LED to -12V (lower potential). The LED anode connects to the GND side.

#### Reverse Polarity Protection

```
D1 (SM4007PL): Cathode → +12V Rail, Anode → GND
D2 (SM4007PL): Cathode → GND, Anode → -12V Rail
D3 (SM4007PL): Cathode → +5V Input, Anode → GND (PSU +5V path, JP1 Pin 3)
D4 (SM4007PL): Cathode → LDO Output, Anode → GND (LDO +5V path, JP1 Pin 1)
```

**Protection Order (Input to Output):**

```
Input → PTC Fuse → TVS Diode → Reverse Diode → Bulk Caps → Distribution
```

#### TVS Transient Protection

```
TVS1 (SMF12CA): Bidirectional, across +12V rail to GND (clamps to 19.9V)
TVS2 (SMF12CA): Bidirectional, across -12V rail to GND (clamps to 19.9V)
TVS3 (SMF5.0CA): Bidirectional, across +5V rail to GND (clamps to 9.2V)

Note: SMF12CA chosen over SMF15CA because 24.4V clamping exceeds the
absolute maximum ratings of many Eurorack module op-amps (15-18V).
```

#### Overcurrent Protection (PTC Fuses)

```
F1 (BSMD1812-200): In series with +12V rail, 2A hold current
F2 (BSMD1812-200): In series with -12V rail, 2A hold current
F3 (BSMD1812-150): In series with +5V rail (after JP1 Pin 2), 1.5A hold current
F4 (BSMD1812-110): In series with LDO input, 1.1A hold current
```

**Note on F3 Position:** F3 is placed after JP1 Pin 2, meaning it protects the +5V distribution rail regardless of whether the LDO or PSU direct mode is selected.

**Note on F4:** F4 provides symmetric protection for the LDO input path. If the LDO shorts internally, F4 limits current draw from the +12V rail.

#### Input Bulk Capacitors

```
C5 (22µF): Across +12V input to GND (transient filtering, after protection)
C6 (22µF): Across -12V input to GND (transient filtering, after protection)
```

#### +5V Rail Bulk Capacitor

```
C23 (22µF): Across +5V rail to GND (after JP1 Pin 2, regardless of source selection)
```

**Note:** This capacitor provides bulk filtering for the +5V rail after the jumper selection, ensuring stable power delivery to digital modules in both LDO and PSU direct modes.

#### Per-Header Decoupling

```
C7-C14 (0.1µF x8):  +12V decoupling near each IDC header
C15-C22 (0.1µF x8): -12V decoupling near each IDC header
```

#### Test Points

```
TP1: +12V rail (after PTC F1)
TP2: -12V rail (after PTC F2)
TP3: +5V rail (after jumper JP1)
TP4: GND reference
TP5: LDO input (+12V to U1)
TP6: LDO output (+5V from U1, before JP1)
```

---

## Selected Components

| Component | Part Number | LCSC | Stock | Notes |
| --- | --- | --- | ----- | --- |
| FASTON Terminal  | 1217754-1 | C305825 | - | x4, 7A rated |
| Screw Terminal | WJ500V-5.08-2P | C8465 | 123K  | x4 |
| 16-pin Header | 2541WR-2x08P | C5383092  | 6.8K  | x8 |
| +5V LDO | AMS1117-5.0 | C6187 | 116K  | SOT-223, 1A |
| Reverse Diode | SM4007PL | C64898 | - | x4, SOD-123FL (D1-D4) |
| OR-ing Schottky  | SS14 | C2480 | 1.09M | x2, SMA (D5-D6) |
| TVS Diode 12V | SMF12CA | C353317 | 67K | x2, bidirectional (±12V) |
| TVS Diode 5V | SMF5.0CA | C908214 | 66K | x1, bidirectional (+5V) |
| PTC Fuse 2A | BSMD1812-200-30V | C960026 | 120K  | x2, 1812 (F1,F2) |
| PTC Fuse 1.5A | BSMD1812-150-33V | C883154 | 69K | x1, 1812 (F3) |
| PTC Fuse 1.1A | BSMD1812-110-33V | C883150 | 50K | x1, 1812 (F4, LDO input) |
| Bulk Cap 22µF | CL21A226MAYNNNE  | C45783 | 5.43M | x4, 0805 25V (C2,C5,C6,C23) |
| LDO Input 10µF | CL21A106KAYNNNE  | C15850 | 1.38M | x1, 0805 25V (C3) |
| Decoupling 0.1µF | CC0603 | C14663 | - | x18, 0603 (C1,C4,C7-C22) |
| LED Red | KT-0603R | C2286 | - | 0603, -12V indicator |
| LED Green | YLED0603YG | C19171392 | - | 0603, +12V indicator |
| LED Blue | NCD1608A1 | C5382145  | - | 0603, +5V indicator |
| LED Resistor | 1kΩ 0805 | C25623 | - | x3, 125mW (R1,R2,R3) |

---

## Next Steps

1. **Create KiCad Schematic**
   - Set up hierarchical sheets
   - Import symbols from easyeda2kicad
   - Wire up circuits per design above

2. **PCB Layout Planning**
   - Define board dimensions
   - Plan connector placement
   - Consider mounting holes

3. **Design Review**
   - Verify current ratings
   - Check thermal dissipation for LDO
   - Confirm JLCPCB compatibility

4. **Prototype Order**
   - Generate gerbers
   - Create BOM for JLCPCB
   - Order test batch

---

## Questions to Resolve

- [ ] Exact LED values and colors to match zudo-pd
- [x] Need bulk capacitors on power rails? → Yes, added C5/C6 (10µF) at input
- [ ] PCB size constraints (case compatibility)
- [ ] Shrouded vs unshrouded IDC headers?

---

## Related Projects

- [zudo-pd](https://takazudomodular.com/pj/zudo-pd/) - USB-PD power supply that powers this bus board
- Old design: `/Users/takazudo/Dropbox/modularCAD/zudo-bus/`

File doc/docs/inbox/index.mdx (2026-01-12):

---
sidebar_position: 1
pagination_next: null
pagination_prev: null
---

import CategoryNav from '@site/src/components/CategoryNav';

# INBOX

Working documentation and current project status.

## Pages in this category

<CategoryNav category="inbox" />

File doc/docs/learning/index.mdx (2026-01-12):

---
sidebar_position: 1
pagination_next: null
pagination_prev: null
---

import CategoryNav from '@site/src/components/CategoryNav';

# Learning

Design notes and learning materials for the bus board project.

## Topics

- Bus board design principles
- Power distribution considerations
- Eurorack power standards
- PCB layout for power circuits

## Pages in this category

<CategoryNav category="learning" />

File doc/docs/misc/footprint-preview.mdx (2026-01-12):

# Footprint Preview

Visual reference of all PCB footprints used in this bus board project. All footprints are sourced from LCSC/EasyEDA and converted to KiCad format.

Click on any footprint to view it in fullscreen.

---

## Connectors

### J_F1-J_F4 - FASTON 250 Terminal

import FootprintSvg from '@site/src/components/FootprintSvg';
import FASTON from '@site/static/footprints-svg/CONN-TH_1217754-1.svg';

<FootprintSvg src={FASTON} alt="FASTON 250 Terminal" minWidth="150px" minHeight="150px" />

**Designators:** J_F1, J_F2, J_F3, J_F4 (4x units)
**Component:** 1217754-1 - FASTON 250 PCB Tab Terminal
**Package:** Through-hole (6.35mm tab width)
**LCSC:** [C305825](https://jlcpcb.com/partdetail/C305825)
**Function:** Power input terminals (+12V, -12V, +5V, GND)

**KiCad:**

- Symbol: `1217754-1`
- Footprint: `CONN-TH_1217754-1.kicad_mod`

### J_S1-J_S4 - Screw Terminal 5.08mm

import ScrewTerminal from '@site/static/footprints-svg/CONN-TH_2P-P5.00_WJ500V-5.08-2P.svg';

<FootprintSvg src={ScrewTerminal} alt="Screw Terminal 5.08mm" minWidth="200px" minHeight="150px" />

**Designators:** J_S1, J_S2, J_S3, J_S4 (4x units)
**Component:** WJ500V-5.08-2P - 2-position Screw Terminal
**Package:** Through-hole 5.08mm pitch
**LCSC:** [C8465](https://jlcpcb.com/partdetail/C8465)
**Function:** Alternative power input terminals

**KiCad:**

- Symbol: `WJ500V-5.08-2P-14-00A`
- Footprint: `CONN-TH_2P-P5.00_WJ500V-5.08-2P.kicad_mod`

### J1-J8 - 16-Pin IDC Header (Eurorack Power)

import IDCHeader from '@site/static/footprints-svg/HDR-TH_16P-P2.54-H-M-R2-C8-S2.54.svg';

<FootprintSvg src={IDCHeader} alt="16-Pin IDC Header" minWidth="400px" minHeight="200px" />

**Designators:** J1, J2, J3, J4, J5, J6, J7, J8 (8x units)
**Component:** 2541WR-2x08P - 2x8 Pin Header (Standard)
**Package:** Through-hole 16-pin header (2x8, 2.54mm pitch)
**LCSC:** [C5383092](https://jlcpcb.com/partdetail/C5383092)
**Function:** Eurorack module power output connectors

**KiCad:**

- Symbol: `2541WR-2X08P`
- Footprint: `HDR-TH_16P-P2.54-H-M-R2-C8-S2.54.kicad_mod`

### JP1 - 3-Pin Jumper Header

import Header3P from '@site/static/footprints-svg/HDR-TH_3P-P2.54-V-M-1.svg';

<FootprintSvg src={Header3P} alt="3-Pin Header" minWidth="200px" minHeight="150px" />

**Designator:** JP1
**Component:** 3-pin header 2.54mm pitch
**Package:** Through-hole 3-pin header
**LCSC:** [C49257](https://jlcpcb.com/partdetail/C49257)
**Function:** +5V source selection (LDO / PSU direct)

**KiCad:**

- Symbol: `Header-Male-2.54_1x3`
- Footprint: `HDR-TH_3P-P2.54-V-M-1.kicad_mod`

---

## Active Components

### U1 - 78L05 LDO Regulator

import SOT89 from '@site/static/footprints-svg/SOT-89-3_L4.5-W2.5-P1.50-LS4.1-BR-1.svg';

<FootprintSvg src={SOT89} alt="78L05 SOT-89-3 Package" minWidth="250px" minHeight="200px" />

**Designator:** U1
**Component:** 78L05 - +5V 100mA Linear Regulator
**Package:** SOT-89-3 (4.5mm x 2.5mm)
**LCSC:** [C20628877](https://jlcpcb.com/partdetail/C20628877)
**Function:** Generates +5V from +12V input

**KiCad:**

- Symbol: `78L05_C20628877`
- Footprint: `SOT-89-3_L4.5-W2.5-P1.50-LS4.1-BR-1.kicad_mod`

---

## Passive Components

### Capacitors

#### C1, C2 - 0.1µF Ceramic Capacitor

import C0603 from '@site/static/footprints-svg/C0603.svg';

<FootprintSvg src={C0603} alt="0603 Capacitor" minWidth="200px" minHeight="150px" />

**Designators:** C1, C2 (2x units)
**Value:** 0.1µF 50V X7R
**Package:** 0603 (1.6mm x 0.8mm)
**LCSC:** [C14663](https://jlcpcb.com/partdetail/C14663)
**Function:** LDO input/output decoupling capacitors

**KiCad:**

- Symbol: `CC0603KRX7R9BB104`
- Footprint: `C0603.kicad_mod`

#### C3, C4 - 1µF Ceramic Capacitor

**Designators:** C3, C4 (2x units)
**Value:** 1µF 16V X5R
**Package:** 0603 (1.6mm x 0.8mm)
**LCSC:** [C6119849](https://jlcpcb.com/partdetail/C6119849)
**Function:** Bulk filtering capacitors

_(Same 0603 footprint as C1, C2)_

**KiCad:**

- Symbol: `CGA0603X5R105K160JT`
- Footprint: `C0603.kicad_mod`

### Resistors

#### R1, R2, R3 - 1kΩ Resistor

import R0603 from '@site/static/footprints-svg/R0603.svg';

<FootprintSvg src={R0603} alt="0603 Resistor" minWidth="200px" minHeight="150px" />

**Designators:** R1, R2, R3 (3x units)
**Value:** 1kΩ ±1%
**Package:** 0603 (1.6mm x 0.8mm)
**LCSC:** [C21190](https://jlcpcb.com/partdetail/C21190)
**Function:** LED current limiting resistors

**KiCad:**

- Symbol: `0603WAF1001T5E`
- Footprint: `R0603.kicad_mod`

---

## Protection Components

### D1, D2 - Reverse Polarity Diodes

import SOD123 from '@site/static/footprints-svg/SOD-123F_L2.8-W1.8-LS3.7-RD.svg';

<FootprintSvg src={SOD123} alt="SOD-123FL Diode" minWidth="200px" minHeight="150px" />

**Designators:** D1, D2 (2x units)
**Component:** SM4007PL (1N4007 equivalent)
**Package:** SOD-123FL (2.8mm x 1.8mm)
**LCSC:** [C64898](https://jlcpcb.com/partdetail/C64898)
**Function:** Reverse polarity protection for ±12V rails

**KiCad:**

- Symbol: `SM4007PL`
- Footprint: `SOD-123F_L2.8-W1.8-LS3.7-RD.kicad_mod`

---

## Indicators

### LED1 - Red LED (-12V Indicator)

import LEDRed from '@site/static/footprints-svg/LED0603-RD.svg';

<FootprintSvg src={LEDRed} alt="0603 Red LED" minWidth="200px" minHeight="150px" />

**Designator:** LED1
**Color:** Red
**Package:** 0603 (1.6mm x 0.8mm)
**LCSC:** [C2286](https://jlcpcb.com/partdetail/C2286)
**Function:** -12V rail status indicator

**KiCad:**

- Symbol: `KT-0603R`
- Footprint: `LED0603-RD.kicad_mod`

### LED2 - Green LED (+12V Indicator)

import LEDGreen from '@site/static/footprints-svg/LED0603-FD.svg';

<FootprintSvg src={LEDGreen} alt="0603 Green LED" minWidth="200px" minHeight="150px" />

**Designator:** LED2
**Color:** Green
**Package:** 0603 (1.6mm x 0.8mm)
**LCSC:** [C19171392](https://jlcpcb.com/partdetail/C19171392)
**Function:** +12V rail status indicator

**KiCad:**

- Symbol: `YLED0603YG`
- Footprint: `LED0603-FD.kicad_mod`

### LED3 - Blue LED (+5V Indicator)

**Designator:** LED3
**Color:** Blue
**Package:** 0603 (1.6mm x 0.8mm)
**LCSC:** [C5382145](https://jlcpcb.com/partdetail/C5382145)
**Function:** +5V rail status indicator

_(Same LED0603-RD footprint as LED1)_

**KiCad:**

- Symbol: `NCD1608A1`
- Footprint: `LED0603-RD.kicad_mod`

---

## Footprint Management

All footprints in this project are downloaded using [easyeda2kicad.py](https://github.com/uPesy/easyeda2kicad.py) from the LCSC/EasyEDA database.

### Adding New Footprints

```bash
# Download footprint by LCSC ID
easyeda2kicad --lcsc_id <LCSC_ID> --footprint --symbol

# Copy to project
cp ~/Documents/Kicad/easyeda2kicad/easyeda2kicad.pretty/*.kicad_mod ./footprints/kicad/
```

### Generating Preview Images

```bash
# 1. Create .pretty directory
mkdir -p footprints/kicad/zudo-bus.pretty
cp footprints/kicad/*.kicad_mod footprints/kicad/zudo-bus.pretty/

# 2. Export to SVG using KiCad CLI
kicad-cli fp export svg footprints/kicad/zudo-bus.pretty -o footprints/images --black-and-white

# 3. Remove REF** placeholder text
python3 footprints/scripts/clean-svg-refs.py footprints/images/

# 4. Copy to documentation static folder
cp footprints/images/*.svg doc/static/footprints-svg/
```

## See Also

- [Bill of Materials](../overview/bom.md) - Complete component list with specifications
- [Overview](../overview/project-overview) - Project technical overview

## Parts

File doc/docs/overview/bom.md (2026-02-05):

# Bill of Materials

Complete list of components for the zudo-bus board.

## Summary

| Category | Count | Notes |
| --- | ----- | --- |
| Connectors | 15 | Input (2) + Chain (4) + IDC (8) + Jumper (1) |
| Active Components  | 1 | +5V LDO regulator |
| Passive Components | 21 | Capacitors (18), resistors (3) |
| Protection | 12 | Diodes (3), TVS (3), PTC (4), Schottky (2) |
| Indicators | 3 | Power rail LEDs |
| Test Points | 6 | TP1-TP6 for debugging |
| **Total** | ~58 | Full protection configuration |

## PCB Design

- **2-layer PCB** - Cost-effective design with copper pours for thermal management

---

## Power Input Connectors

### Screw Terminals 5.08mm (x2)

| Designator | Value | Package | LCSC | Function |
| --- | --- | --- | --- | --- |
| P1 | WJ500V-5.08-2P | 5.08mm 2P | [C8465](https://jlcpcb.com/partdetail/C8465) | -12V and GND input |
| P2 | WJ500V-5.08-2P | 5.08mm 2P | [C8465](https://jlcpcb.com/partdetail/C8465) | +12V and +5V input |

**Pin Assignments:**

| Terminal | Pin 1  | Pin 2 |
| --- | --- | --- |
| P1 | GND | -12V in |
| P2 | +5V in | +12V in |

**Notes:** 2-position screw terminals for easy wire connection.

**KiCad:**

- Symbol: `WJ500V-5.08-2P-14-00A`
- Footprint: `CONN-TH_2P-P5.00_WJ500V-5.08-2P.kicad_mod`

**Alternative (higher stock):**

- [C2915639](https://jlcpcb.com/partdetail/C2915639) - DB128V-5.08-2P (19K stock)
- [C71370](https://jlcpcb.com/partdetail/C71370) - WJ2EDGK-5.08-2P (75K stock, pluggable)

---

## Bus Board Chaining Connectors

### FASTON 250 Terminals (x4)

| Designator | Value | Package | LCSC | Function |
| --- | --- | --- | --- | --- |
| P3 | 1217754-1 | CONN-TH | [C305825](https://jlcpcb.com/partdetail/C305825) | -12V chain |
| P4 | 1217754-1 | CONN-TH | [C305825](https://jlcpcb.com/partdetail/C305825) | GND chain  |
| P5 | 1217754-1 | CONN-TH | [C305825](https://jlcpcb.com/partdetail/C305825) | +12V chain |
| P6 | 1217754-1 | CONN-TH | [C305825](https://jlcpcb.com/partdetail/C305825) | +5V chain  |

**Notes:** FASTON terminals for daisy-chaining multiple bus boards. Through-hole, hand-solderable. 7A rated per terminal. Compatible with standard 6.3mm FASTON receptacles.

**KiCad:**

- Symbol: `1217754-1`
- Footprint: `CONN-TH_1217754-1.kicad_mod`

---

## Power Output Connectors

### 16-Pin IDC Headers (x8)

| Designator | Value | Package | LCSC | Function |
| --- | --- | --- | --- | --- |
| J101-J108  | 2541WR-2x08P | 2x8 2.54mm | [C5383092](https://jlcpcb.com/partdetail/C5383092) | Module output |

**Notes:** Standard Eurorack 16-pin power connector. Through-hole, right-angle. Numbering scheme: J1XX where XX = unit number (01-08).

**KiCad:**

- Symbol: `2541WR-2X08P`
- Footprint: `HDR-TH_16P-P2.54-H-M-R2-C8-S2.54.kicad_mod`

**Alternative (SMD):**

- [C32713288](https://jlcpcb.com/partdetail/C32713288) - HX PZ2.54-2x8P TP SMD (3.7K stock)

---

## +5V Generation Circuit

### LDO Regulator

| Designator | Value | Package | LCSC | Function |
| --- | --- | --- | --- | --- |
| U1 | AMS1117-5.0 | SOT-223 | [C6187](https://jlcpcb.com/partdetail/C6187) | +5V 1A LDO |

**Notes:** Generates +5V from +12V input. 1A output current (practical limit ~300mA due to thermal dissipation).

**Specifications:**

- Input: +12V (6.5V-15V range, abs max 18V)
- Output: +5V @ 1A max
- Dropout: ~1.2V (lower than 78xx series)
- Package: SOT-223 (SMD)
- Requires 22µF low-ESR output capacitor for stability

**KiCad:**

- Symbol: `AMS1117-5.0_C6187`
- Footprint: `SOT-223-3_L6.5-W3.4-P2.30-LS7.0-BR.kicad_mod`

### +5V Selection Header

| Designator | Value | Package | LCSC | Function |
| --- | --- | --- | --- | --- |
| JP1 | 3-pin header | 2.54mm  | [C49257](https://jlcpcb.com/partdetail/C49257) | +5V source select |

**Jumper positions:**

- 1-2: Use on-board LDO (+5V from +12V)
- 2-3: Use PSU +5V directly
- None: +5V rail disabled

**KiCad:**

- Symbol: `Header-Male-2.54_1x3`
- Footprint: `HDR-TH_3P-P2.54-V-M-1.kicad_mod`

---

## Passive Components

### Capacitors

| Designator | Value | Package | LCSC | Function |
| --- | ----- | --- | --- | --- |
| C1 | 10µF  | 0805 | [C15850](https://jlcpcb.com/partdetail/C15850) | U1 input bulk capacitor |
| C2 | 22µF  | 0805 | [C45783](https://jlcpcb.com/partdetail/C45783) | U1 output capacitor |
| C101-C108  | 0.1µF | 0603 | [C14663](https://jlcpcb.com/partdetail/C14663) | -12V per-header decoupling x8 |
| C201-C208  | 0.1µF | 0603 | [C14663](https://jlcpcb.com/partdetail/C14663) | +12V per-header decoupling x8 |

**Notes:**

- C1: 10µF input capacitor for AMS1117 LDO
- C2: 22µF low-ESR output capacitor **required for AMS1117 stability** (Samsung CL21A226MAYNNNE, 25V X5R, Basic Part)
- C101-C108: -12V per-header decoupling capacitors (C1XX matches J1XX header number)
- C201-C208: +12V per-header decoupling capacitors (C2XX matches J1XX header number)

**DC Bias Derating Note:** X5R ceramic capacitors lose capacitance under DC bias. At 12V on a 25V-rated cap, expect ~65% of nominal capacitance (22µF → ~14µF effective). This is acceptable for bulk filtering purposes.

**KiCad:**

- Symbol: `CL21A106KAYNNNE` (10µF), `CL21A226MAYNNNE` (22µF), `CC0603KRX7R9BB104` (0.1µF)
- Footprint: `C0805.kicad_mod`, `C0603.kicad_mod`

### Resistors

| Designator | Value | Package | LCSC | Function |
| --- | ----- | --- | --- | --- |
| R1, R2, R3 | 1kΩ | 0805 | [C25623](https://jlcpcb.com/partdetail/C25623) | LED current limiting (all) |

**Notes:**

- All LEDs use 1kΩ resistors (same as zudo-power-usb-pd for consistency)
- LED current: ~10mA for ±12V LEDs, ~2mA for +5V LED

**KiCad:**

- Symbol: `RC0603FR-071KL` (1kΩ)
- Footprint: `R0603.kicad_mod`

---

## Protection Components

### TVS Diodes (Transient Protection)

| Designator | Value | Package | LCSC | Function |
| --- | --- | --- | --- | --- |
| D1 | SMF12CA  | SOD-123FL | [C353317](https://jlcpcb.com/partdetail/C353317) | +12V transient clamp |
| D3 | SMF12CA  | SOD-123FL | [C353317](https://jlcpcb.com/partdetail/C353317) | -12V transient clamp |
| D5 | SMF5.0CA | SOD-123 | [C908214](https://jlcpcb.com/partdetail/C908214) | +5V transient clamp  |

**Notes:** Bidirectional TVS diodes for ESD and transient spike protection. Connected between rail junction and GND.

**KiCad:**

- Symbol: `SMF12CA_C353317`, `SMF5.0CA_C908214`
- Footprint: `SOD-123FL_L2.8-W1.8-LS3.7-BI.kicad_mod`

### Reverse Polarity Diodes

| Designator | Value | Package | LCSC | Function |
| --- | --- | --- | --- | --- |
| D2 | SM4007PL | SOD-123FL | [C64898](https://jlcpcb.com/partdetail/C64898) | +12V reverse protection |
| D4 | SM4007PL | SOD-123FL | [C64898](https://jlcpcb.com/partdetail/C64898) | -12V reverse protection |
| D6 | SM4007PL | SOD-123FL | [C64898](https://jlcpcb.com/partdetail/C64898) | +5V reverse protection  |

**Notes:** SM4007PL is a 1N4007 equivalent in SOD-123FL package. In series with each rail after PTC fuse.

**Protection Order (Input to Output):**

```
Input → PTC Fuse → TVS Diode (to GND) → Reverse Diode → Rail
```

**KiCad:**

- Symbol: `SM4007PL`
- Footprint: `SOD-123F_L2.8-W1.8-LS3.7-RD.kicad_mod`

### +5V OR-ing Schottky Diodes (Backfeed Protection)

| Designator | Value | Package | LCSC | Function |
| --- | ----- | --- | --- | --- |
| D7 | SS14  | SMA(DO-214AC) | [C2480](https://jlcpcb.com/partdetail/C2480) | +5V LDO output OR-ing diode |
| D8 | SS14  | SMA(DO-214AC) | [C2480](https://jlcpcb.com/partdetail/C2480) | +5V PSU path OR-ing diode |

**Notes:** SS14 Schottky diodes (40V, 1A) create an OR-ing configuration to prevent backfeed between the LDO and PSU +5V sources.

**KiCad:**

- Symbol: `SS14` (in `zudo-bus-new-protection.kicad_sym`)
- Footprint: `SMA_L4.2-W2.6-LS5.0-RD_1.kicad_mod`

### Diode Summary by Diagram

| Diagram  | Ref | Part | Function |
| --- | --- | --- | --- |
| Diagram2 | D1  | SMF12CA  | +12V TVS (bidirectional) |
| Diagram2 | D2  | SM4007PL | +12V reverse protection  |
| Diagram3 | D3  | SMF12CA  | -12V TVS (bidirectional) |
| Diagram3 | D4  | SM4007PL | -12V reverse protection  |
| Diagram4 | D5  | SMF5.0CA | +5V TVS (bidirectional)  |
| Diagram4 | D6  | SM4007PL | +5V reverse protection |
| Diagram5 | D7  | SS14 | +5V LDO OR-ing Schottky  |
| Diagram5 | D8  | SS14 | +5V PSU OR-ing Schottky  |

**Notes:** Bidirectional TVS diodes for ESD and transient spike protection. SMF12CA (Stock: 67K) has 12V standoff for ±12V rails - chosen over SMF15CA for lower clamping voltage that better protects Eurorack module components. SMF5.0CA (Stock: 66K) has 5V standoff for +5V rail.

**Specifications (SMF12CA):**

- Standoff voltage: 12V
- Breakdown voltage: 13.3V - 14.7V
- Clamping voltage: 19.9V @ 10.1A (safe for op-amps rated 15-18V abs max)
- Peak pulse current: 10.1A (8/20µs)
- Package: SOD-123FL (SMD)

**Specifications (SMF5.0CA):**

- Standoff voltage: 5V
- Breakdown voltage: 6.4V
- Clamping voltage: 9.2V @ 11.7A
- Package: SOD-123 (SMD)

**Design Note:** SMF12CA was chosen over SMF15CA because the SMF15CA clamps at 24.4V, which exceeds the absolute maximum ratings of many Eurorack module op-amps (typically 15-18V). The SMF12CA clamps at 19.9V, providing better protection for downstream components while still allowing normal 12V operation.

**KiCad:**

- Symbol: `SMF12CA_C353317` (in `zudo-bus-new-protection.kicad_sym`), `SMF5.0CA_C908214` (in `zudo-bus-protection.kicad_sym`)
- Footprint: `SOD-123FL_L2.8-W1.8-LS3.7-BI.kicad_mod` (SMF12CA), `SOD-123_L2.8-W1.8-LS3.7-BI.kicad_mod` (SMF5.0CA)

### Resettable Fuses (PTC)

| Designator | Value | Package | LCSC | Function |
| --- | --- | --- | --- | --- |
| F1 | BSMD1812-200-30V | 1812 | [C960026](https://jlcpcb.com/partdetail/C960026) | +12V overcurrent (2A) |
| F2 | BSMD1812-150-33V | 1812 | [C883154](https://jlcpcb.com/partdetail/C883154) | -12V overcurrent (1.5A) |
| F3 | BSMD1812-150-33V | 1812 | [C883154](https://jlcpcb.com/partdetail/C883154) | +5V PSU input (1.5A) |
| F4 | BSMD1812-110-33V | 1812 | [C883150](https://jlcpcb.com/partdetail/C883150) | +5V rail output (1.1A)  |

**Notes:** Self-resetting PTC fuses. Trip on overcurrent, auto-reset when cooled.

- F1: +12V rail protection (2A hold)
- F2, F3: -12V and +5V PSU input protection (1.5A hold)
- F4: +5V rail output protection - placed after JP1 jumper, protects +5V distribution from module shorts regardless of LDO or PSU source

**Specifications (BSMD1812-200-30V):**

- Hold current: 2.0A
- Trip current: 4.0A
- Max voltage: 30V
- Initial resistance: 50mΩ typ
- Package: 1812 SMD

**Specifications (BSMD1812-150-33V):**

- Hold current: 1.5A
- Trip current: 3.0A
- Max voltage: 33V
- Package: 1812 SMD

**Specifications (BSMD1812-110-33V):**

- Hold current: 1.1A
- Trip current: 2.2A
- Max voltage: 33V
- Package: 1812 SMD

**KiCad:**

- Symbol: `BSMD1812-200-30V`, `BSMD1812-150-33V` (in `zudo-bus-protection.kicad_sym`), `BSMD1812-110-33V` (in `zudo-bus-new-protection.kicad_sym`)
- Footprint: `F1812.kicad_mod`

---

## Indicators

### Power LEDs

| Designator | Value | Package | LCSC | Function |
| --- | ----- | --- | --- | --- |
| LED1 | Red | 0603 | [C2286](https://jlcpcb.com/partdetail/C2286) | -12V indicator |
| LED2 | Green | 0603 | [C19171392](https://jlcpcb.com/partdetail/C19171392) | +12V indicator |
| LED3 | Blue  | 0603 | [C5382145](https://jlcpcb.com/partdetail/C5382145) | +5V indicator  |

**KiCad:**

- Symbol: `KT-0603R` (Red), `YLED0603YG` (Green), `NCD1608A1` (Blue)
- Footprint: `LED0603-RD.kicad_mod` (Red/Blue), `LED0603-FD.kicad_mod` (Green)

---

## Test Points

| Designator | Location | Function |
| --- | --- | --- |
| TP1 | +12V rail (after D2) | +12V Rail measurement |
| TP2 | -12V rail (after D4) | -12V Rail measurement |
| TP3 | +5V PSU (after D6, before D8) | +5V IN measurement |
| TP4 | U1 output (before D7) | LDO +5V output |
| TP5 | JP1 pin 2 (before F4) | +5V Rail measurement  |
| TP6 | Ground reference | GND reference |

**Notes:**

- Test points enable easy debugging and measurement during development
- Use standard through-hole test point pads or SMD test points
- TP6 (GND) provides reference for all voltage measurements
- TP3 vs TP4: Compare PSU input vs LDO output to verify source selection
- TP5: Measures +5V after source selection but before output protection F4

---

## JLCPCB Assembly Notes

### SMT Assembly

- All SMD components can be assembled by JLCPCB
- Select "Economic" or "Standard" PCBA based on component availability

### Through-Hole Components (Manual Assembly)

- FASTON terminals (C305825)
- Screw terminals (C8465)
- 16-pin IDC headers (C5383092)
- 3-pin jumper header

### Recommended Order

1. Order PCB + SMT assembly from JLCPCB
2. Order through-hole connectors separately
3. Hand-solder through-hole components

---

## Reference: Old Design Components

From zudo-bus v1/v2:

| Component | Value | LCSC | Notes |
| --- | --- | --- | --- |
| U1 | L78L05ABUTR | C42738 | +5V LDO (SOT-89) |
| D1, D2 | 1N4007 | - | Reverse protection |
| C1-C3 | 0.1µF | - | Decoupling |
| U3, U4 | 1µF elec | - | Bulk caps |
| R1, R2 | 1kΩ | - | LED resistors |
| R3 | 470Ω | - | LED resistor |
| LED1 | Red | - | -12V indicator |
| LED2 | Blue | - | +12V indicator |
| LED3 | White | - | +5V indicator |

---

## KiCad Library Files

### Symbol Libraries

| Library File | Contents |
| --- | --- |
| `zudo-bus.kicad_sym` | Main symbols (LDO, connectors, passives, LEDs) |
| `zudo-bus-protection.kicad_sym` | Original protection (SMF5.0CA, PTC 2A/1.5A) |
| `zudo-bus-new-protection.kicad_sym` | Updated protection (SMF12CA, PTC 1.1A, SS14, 22µF) |
| `samsung-caps.kicad_sym` | Samsung capacitors (10µF, 22µF) |

**zudo-bus-protection.kicad_sym symbols:**

- `SMF15CA_C908211` - TVS diode 15V bidirectional (legacy, replaced by SMF12CA)
- `SMF5.0CA_C908214` - TVS diode 5V bidirectional
- `BSMD1812-200-30V` - PTC fuse 2A
- `BSMD1812-150-33V` - PTC fuse 1.5A
- `TCC0805X5R106K250FT` - 10µF capacitor (alternative)
- `AMS1117-5.0` - LDO regulator

**zudo-bus-new-protection.kicad_sym symbols:**

- `SMF12CA_C353317` - TVS diode 12V bidirectional (replaces SMF15CA for safer clamping)
- `BSMD1812-110-33V` - PTC fuse 1.1A (for LDO input protection)
- `SS14` - Schottky diode 40V 1A (for +5V OR-ing)
- `CL21A226MAQNNNE` - 22µF capacitor (Samsung C45783)

**samsung-caps.kicad_sym symbols:**

- `CL21A106KAYNNNE` - 10µF capacitor (C15850)
- `CL21A226MAQNNNE` - 22µF capacitor (C45783)

### Footprint Library

**Directory:** `footprints/kicad/zudo-bus.pretty/`

| Footprint | Package | Used By |
| --- | --- | --- |
| `C0603.kicad_mod` | 0603 | C101-C208 (0.1µF caps) |
| `C0805.kicad_mod` | 0805 | C1, C2 (10µF, 22µF) |
| `R0603.kicad_mod` | 0603 | (available if needed) |
| `R0805.kicad_mod` | 0805 | R1, R2, R3 (1kΩ resistors) |
| `LED0603-RD.kicad_mod` | 0603 | LED1 (Red), LED3 (Blue) |
| `LED0603-FD.kicad_mod` | 0603 | LED2 (Green) |
| `SOD-123F_L2.8-W1.8-LS3.7-RD.kicad_mod` | SOD-123F | D2, D4, D6 (reverse protection) |
| `SOD-123_L2.8-W1.8-LS3.7-BI.kicad_mod` | SOD-123 | D5 (SMF5.0CA TVS) |
| `SOD-123FL_L2.8-W1.8-LS3.7-BI.kicad_mod` | SOD-123FL | D1, D3 (SMF12CA TVS) |
| `SMA_L4.2-W2.6-LS5.0-RD_1.kicad_mod` | SMA (DO-214AC) | D7, D8 (SS14 Schottky) |
| `F1812.kicad_mod` | 1812 | F1, F2, F3, F4 (PTC fuses) |
| `SOT-223_L6.5-W3.5-P2.30-LS7.0-BR.kicad_mod` | SOT-223 | U1 (LDO regulator) |
| `HDR-TH_3P-P2.54-V-M-1.kicad_mod` | 2.54mm | JP1 (jumper header) |
| `eurorack-power-16pin.kicad_mod` | 2x8 2.54mm | J101-J108 (IDC headers, custom) |
| `power-faston-pin.kicad_mod` | FASTON | P3-P6 (FASTON chain output, custom) |
| `CONN-TH_2P-P5.00_WJ500V-5.08-2P.kicad_mod`  | 5.08mm | P1, P2 (screw terminals) |

**Total footprints:** 18 files (includes 2 custom footprints)

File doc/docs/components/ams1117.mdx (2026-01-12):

---
sidebar_position: 2
---

import FootprintSvg from '@site/src/components/FootprintSvg';
import SOT223 from '@site/static/footprints-svg/SOT-223_L6.5-W3.5-P2.30-LS7.0-BR.svg';
import Ldo78l05Diagram from '../_fragments/ldo-78l05-diagram.mdx';

# AMS1117-5.0 - +5V LDO Regulator

Low-dropout positive voltage regulator providing stable +5V output at up to 1A from +12V input in SOT-223 surface-mount package.

- [View on JLCPCB: C6187](https://jlcpcb.com/partdetail/C6187)

<FootprintSvg src={SOT223} alt="AMS1117-5.0 SOT-223 Package" minWidth="250px" minHeight="150px" />

## Overview

The AMS1117-5.0 is a low-dropout three-terminal positive voltage regulator in SOT-223 package, designed to provide a fixed +5V output at up to 1A from a higher input voltage. In the zudo-bus design, this component generates +5V from the +12V rail for digital modules that require +5V power. The on-board generation is optional - users can alternatively use PSU +5V directly via the jumper selection.

The AMS1117 was chosen over the 78L05 for its higher current capacity (1A vs 100mA), making it suitable for setups with multiple digital modules requiring +5V.

## Key Specifications

| Parameter | Value | Notes |
| --- | --- | --- |
| **JLCPCB Part Number** | C6187 | |
| **Manufacturer Part Number** | AMS1117-5.0 | |
| **Package** | SOT-223 | Surface-mount |
| **Output Voltage** | 5V ±2% | 4.9V - 5.1V typical  |
| **Output Current** | 1A max | Design limit |
| **Input Voltage Range** | 6.5V - 15V | Absolute max 18V |
| **Dropout Voltage** | 1.2V typical | At 1A load |
| **Line Regulation** | 0.2% max | VIN = 7V to 15V |
| **Load Regulation** | 0.4% max | IO = 10mA to 1A |
| **Quiescent Current** | 5mA typical | No-load consumption  |
| **Operating Temp Range** | -40°C to +125°C | Junction temperature |

## Pin Configuration

```
         SOT-223 Package
              Top View

         ┌──────────────┐
         │              │
         │  AMS1117-5.0 │
         │              │
         │              │
         └──┬───┬───┬───┘
            │   │   │
          PIN1 PIN2 PIN3
          GND  OUT  INPUT
               (+5V) (+12V)

              TAB
           (OUTPUT)
            (+5V)

         Bottom View (Pads)

    ┌─────────────────────────┐
    │                         │
    │    Large Tab Pad        │  ← OUTPUT (+5V)
    │    (Heat dissipation)   │
    │                         │
    └─────────────────────────┘
         ■      ■      ■
        PIN1   PIN2   PIN3
         GND   OUTPUT INPUT
```

### Pin Descriptions

| Pin | Name | Function | Connection in Design |
| --- | --- | --- | --- |
| 1 | GND | Ground reference (common) | System ground |
| 2 | OUTPUT | Regulated +5V output | JP1 Pin 1 (LDO output)  |
| 3 | INPUT  | Unregulated input voltage | +12V rail |
| TAB | OUTPUT | Output (connected to pin 2) | Thermal dissipation pad |

**Note**: The metal tab is internally connected to the OUTPUT pin (pin 2), providing both electrical connection and thermal dissipation path. This is different from the 78L05 pinout.

## Application Circuit

<Ldo78l05Diagram />

## Component Values

### Input/Output Capacitors

| Reference | Value | Type | Package | LCSC | Purpose |
| --- | ----- | --- | --- | --- | --- |
| C1 | 0.1µF | Ceramic X7R | 0603 | C14663 | High-frequency input decoupling  |
| C2 | 22µF  | Ceramic X5R | 0805 | TBD | Output stability (CRITICAL) |
| C3 | 10µF  | Ceramic X5R | 0805 | TBD | Bulk input filtering |
| C4 | 0.1µF | Ceramic X7R | 0603 | C14663 | High-frequency output decoupling |

**Important**: The AMS1117 requires a low-ESR output capacitor (22µF or larger) for stability. Ceramic capacitors are preferred over electrolytic for their low ESR characteristics.

## Design Considerations

### Input Voltage Requirements

The AMS1117-5.0 requires a minimum input voltage of approximately 6.2V for proper regulation (5V output + 1.2V dropout). In this design:

- **Input voltage**: +12V from PSU
- **Dropout margin**: 12V - 5V = 7V
- **Status**: Excellent - well above minimum dropout voltage

The 7V margin provides:

1. Stable regulation across load variations
2. Tolerance for input voltage ripple from PSU
3. Higher power dissipation (must be managed thermally at high loads)

### Thermal Management

Power dissipation calculation at various loads:

```
At 1A (maximum):
P = (VIN - VOUT) × IOUT
P = (12V - 5V) × 1A
P = 7W (EXCESSIVE - do not operate at this level)

At 500mA (practical limit):
P = 7V × 0.5A
P = 3.5W (requires good thermal design)

At 200mA (typical use):
P = 7V × 0.2A
P = 1.4W (manageable with copper pour)
```

**SOT-223 Thermal Performance**:

- Junction-to-ambient thermal resistance: ~90°C/W (typical, with copper pour)
- At 1.4W: Temperature rise = 126°C (too high without heatsinking)
- At 1.4W with good PCB thermal design: ~60-80°C rise

**Recommendations**:

- Large copper pour under and around the tab pad for heat spreading
- Thermal vias to inner/bottom copper layers
- Practical continuous load limit: 200-300mA for reliable operation
- Use PSU +5V directly (jumper 2-3) for loads exceeding 300mA

### Capacitor Requirements (Critical)

The AMS1117 is sensitive to output capacitor ESR. Unlike the 78xx family, it requires:

1. **Output capacitor (C2)**: 22µF minimum, low ESR
   - Ceramic X5R/X7R preferred
   - ESR should be below 0.5Ω
   - Place immediately adjacent to pin 2

2. **Input capacitor (C3)**: 10µF recommended
   - Helps with input ripple rejection
   - Ceramic or tantalum acceptable

3. **High-frequency decoupling (C1, C4)**: 0.1µF ceramic
   - Place as close to IC pins as possible

### Current Capacity

The AMS1117 provides up to 1A output, a significant improvement over the 78L05 (100mA):

- Typical +5V module consumption: 20-50mA per module
- With 8 headers at 50mA each: 400mA total
- **AMS1117 capacity**: Adequate for most configurations
- **Thermal limit**: Practical limit is 200-300mA continuous from 12V input

## Protection Features

### Built-in Protections

1. **Thermal Shutdown**: Automatically shuts down if junction temperature exceeds 165°C
2. **Current Limiting**: Internal current limit at approximately 1.1-1.5A
3. **SOA Protection**: Safe operating area protection

### External Protection (This Design)

The +5V rail has comprehensive external protection:

```
Reverse Polarity Protection (both paths):
PSU +5V ─── D3 (SM4007PL) ───→ To JP1 Pin 3 (PSU path)
            Anode → Cathode
            (blocks reversed PSU)

LDO +5V ─── D4 (SM4007PL) ───→ To JP1 Pin 1 (LDO path)
            Anode → Cathode
            (protects LDO from backfeed)

Overcurrent Protection:
+5V Rail ─── F3 (PTC 1.5A) ───→ To IDC Headers
             (self-resetting)
             (1.5A hold / 3A trip)

Transient Protection:
+5V Rail ──┬───→ To Load
           │
          ┌┴┐ TVS3 (SMF5.0CA)
          │ │ Bidirectional
          └┬┘ Clamps to 9.2V max
           │
          GND

Status LED:
+5V Rail ─── R3 (1kΩ) ─── LED3 (Blue) ─── GND
```

**Protection Order (Input to Output):**

```
Input → PTC Fuse → TVS Diode → Reverse Diode → Bulk Caps → Distribution
```

Protection stages:

1. **Overcurrent (F3 PTC 1.5A)**: Self-resetting fuse for overload (first line of defense)
2. **Transient (TVS3 SMF5.0CA)**: Clamps voltage spikes to 9.2V max
3. **Reverse polarity (D3, D4)**: Blocks reversed connections on both PSU and LDO paths

## Bill of Materials

| Designator | Part | Value | Package | JLCPCB Part # | Qty | Purpose |
| --- | --- | --- | --- | --- | --- | --- |
| U1 | AMS1117-5.0 | +5V 1A | SOT-223 | C6187 | 1 | LDO regulator |
| C1 | Ceramic Cap | 0.1µF | 0603 | C14663 | 1 | Input HF decoupling  |
| C2 | Ceramic Cap | 22µF | 0805 | TBD | 1 | Output capacitor |
| C3 | Ceramic Cap | 10µF | 0805 | TBD | 1 | Input bulk cap |
| C4 | Ceramic Cap | 0.1µF | 0603 | C14663 | 1 | Output HF decoupling |
| JP1 | Pin Header  | 3-pin 2.54mm | TH | C49257 | 1 | +5V source select |

## Alternative Parts

### Direct Replacements (SOT-223 Package)

| Part Number | Manufacturer | JLCPCB Part # | Output Current | Notes |
| --- | --- | --- | --- | --- |
| AMS1117-5.0 | AMS | C6187 | 1A | **Used in design** |
| LD1117S50TR | ST | C155954 | 800mA | Alternative |
| LM1117IMP-5.0 | TI | C126027 | 800mA | Higher quality |

### Lower Current Alternatives

If space is critical and lower current is acceptable:

| Package  | Part Number | JLCPCB Part # | Current | Notes |
| --- | --- | --- | --- | --- |
| SOT-89-3 | 78L05 | C20628877 | 100mA | Smaller, lower current |
| SOT-89-3 | AMS1117-5.0 | C7473143 | 1A | Same IC, smaller package |

## PCB Layout Guidelines

### Footprint (SOT-223)

```
    Top View (PCB Pad Layout)

    ┌─────────────────────────┐
    │                         │
    │    Large Tab Pad        │  ← Pin 2 (OUTPUT)
    │    (for heat spread)    │     Also thermal pad
    │                         │
    └─────────────────────────┘

         ■      ■      ■
        Pin 1  Pin 2  Pin 3
         GND   OUTPUT INPUT

    Dimensions:
    - Tab pad: 6.5mm × 3.4mm
    - Pin spacing: 2.30mm
    - Pin pad: ~1.0mm × 2.0mm
```

### Layout Recommendations

1. **Component placement**:
   - Keep C2 (22µF output) as close to pin 2 as possible - CRITICAL
   - Keep C1 close to pin 3
   - Ensure wide, direct ground connection from C1, C2 to pin 1

2. **Thermal management**:
   - Large copper pour connected to tab pad (OUTPUT)
   - Add thermal vias under tab (6-8 vias, 0.3mm diameter)
   - Connect thermal vias to ground plane or dedicated thermal plane
   - Consider both top and bottom copper for heat spreading

3. **Trace widths**:
   - Input trace (+12V): 0.5mm minimum (for 1A capability)
   - Output trace (+5V): 0.5mm minimum
   - Ground: Maximum copper pour area

## Testing and Validation

### Output Voltage Test

1. Apply +12V to input with no load
2. Set jumper to position 1-2 (LDO mode)
3. Verify output voltage: 4.9V - 5.1V (5V ±2%)

### Load Regulation Test

1. Connect variable load (0-500mA)
2. Measure output voltage at different load currents:
   - 0mA: Should be within 5V ±1%
   - 200mA: Should be within 5V ±2%
   - 500mA: Should be within 5V ±2%

### Thermal Test

1. Apply 300mA load for 10 minutes
2. Measure case temperature (touch test or IR thermometer)
3. Verify component is warm but not hot (`<85°C`)
4. If too hot, improve thermal design or reduce load

## Troubleshooting

| Symptom | Possible Cause | Solution |
| --- | --- | --- |
| No output voltage  | Jumper not installed | Install jumper at position 1-2 |
| | Input voltage too low | Verify +12V input present |
| | Thermal shutdown | Reduce load, improve thermal design  |
| Low output voltage | Excessive load current | Reduce load or use PSU +5V |
| | Poor input voltage | Check +12V rail stability |
| Oscillation | Wrong output capacitor | Use 22µF+ low-ESR ceramic |
| | Poor capacitor placement | Move C2 closer to output pin |
| | High ESR capacitor | Replace with ceramic capacitor |
| Overheating | Excessive load | Use PSU +5V for high-current modules |
| | Poor thermal design | Add copper pour, thermal vias |

## Application Notes

### When to Use LDO vs PSU +5V

**Use LDO (Jumper 1-2):**

- Moderate +5V requirements
- Total +5V current `<300mA`
- PSU doesn't provide +5V output
- Clean, regulated +5V needed

**Use PSU +5V Direct (Jumper 2-3):**

- Multiple digital modules requiring +5V
- Total +5V current `>300mA`
- PSU has dedicated +5V output
- Better thermal performance needed

### +5V Rail Usage in Eurorack

Most Eurorack modules only require ±12V. The +5V rail is used by:

- Digital modules with 5V logic
- Some older module designs
- Specific manufacturer requirements (e.g., some Intellijel modules)

Many modern digital modules generate +5V internally from +12V, reducing demand on the bus +5V rail.

### Comparison: AMS1117 vs 78L05

| Feature | AMS1117-5.0 | 78L05 |
| --- | --- | --- |
| Max Current | 1A | 100mA |
| Dropout Voltage  | 1.2V | 2V |
| Package | SOT-223 | SOT-89-3 |
| Output Cap | 22µF+ low-ESR | 0.1µF |
| Thermal Shutdown | Yes | Yes |
| Current Limit | Yes | Yes |

## Related Components

- **Input power**: +12V rail from PSU via FASTON/screw terminals
- **Selection**: JP1 3-pin jumper header for +5V source selection
- **Protection**: F3 (PTC fuse), TVS3 (TVS diode), D3 (PSU path), D4 (LDO path)
- **Indicator**: LED3 (Blue) shows +5V rail status

## References

- [JLCPCB Part C6187](https://jlcpcb.com/partdetail/C6187)
- [AMS1117 Datasheet](http://www.advanced-monolithic.com/pdf/ds1117.pdf) - Advanced Monolithic Systems
- Related documentation: [Bill of Materials](/docs/overview/bom)

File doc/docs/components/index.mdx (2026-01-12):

---
sidebar_position: 1
pagination_next: null
pagination_prev: null
---

import CategoryNav from '@site/src/components/CategoryNav';

# Components

Component specifications and datasheets for the bus board.

## Component Categories

- **Connectors** - Screw terminals, IDC headers
- **Protection** - Reverse polarity protection, fuses
- **Passive** - Decoupling capacitors, resistors
- **Indicators** - Status LEDs

## Pages in this category

<CategoryNav category="components" />

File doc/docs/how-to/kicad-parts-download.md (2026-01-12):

---
sidebar_position: 2
---

# Download KiCad Footprints and Symbols

This guide explains how to download KiCad footprints and symbols from LCSC/EasyEDA using the easyeda2kicad.py tool.

## Overview

This project uses [easyeda2kicad.py](https://github.com/uPesy/easyeda2kicad.py) to download KiCad libraries from the LCSC/EasyEDA database. This ensures we have accurate footprints and symbols matching the actual components from JLCPCB.

**What you can download:**

- **Footprints** (`.kicad_mod`) - Physical PCB pads for PCB layout
- **Symbols** (`.kicad_sym`) - Schematic symbols for circuit design
- **3D Models** (`.step`, `.wrl`) - 3D visualization (optional)

## Important: Footprints vs Symbols

**You need BOTH for KiCad design:**

| Type | File Format  | Used In | Purpose |
| --- | --- | --- | --- |
| Footprint | `.kicad_mod` | PCB Editor | Physical component pads on PCB |
| Symbol | `.kicad_sym` | Schematic Editor | Electrical connections in schematic |

**Common mistake:** Downloading only `--footprint` without `--symbol`!

## Prerequisites

### Install easyeda2kicad.py

```bash
pip install easyeda2kicad
```

The tool should be available in your PATH after installation.

### Verify Installation

```bash
easyeda2kicad --version
```

## Quick Start: Download Pre-Generated Footprints

**Don't want to generate footprints yourself?** Download the complete footprint library directly from GitHub:

**🔗 [Download Footprints from GitHub](https://github.com/Takazudo/zudo-pd/tree/main/footprints)**

The `/footprints/kicad/` directory contains all `.kicad_mod` files ready to use in your KiCad project.

---

## Finding LCSC Part Numbers

All component LCSC IDs are listed in the [Bill of Materials](../overview/bom.md). You can also search on:

- [LCSC.com](https://www.lcsc.com/)
- [EasyEDA.com](https://easyeda.com/)

## Download Options

### Option 1: Download Both (Recommended)

Download footprint AND symbol together:

```bash
# Download both footprint and symbol
easyeda2kicad --lcsc_id <LCSC_ID> --footprint --symbol

# Example: CH224D (USB-PD controller)
easyeda2kicad --lcsc_id C3975094 --footprint --symbol

# Example: USB-C connector
easyeda2kicad --lcsc_id C2927029 --footprint --symbol
```

### Option 2: Download Only Footprint

For parts where you'll use KiCad standard symbols:

```bash
# Download only footprint
easyeda2kicad --lcsc_id <LCSC_ID> --footprint
```

### Option 3: Download Only Symbol

For parts where you already have the footprint:

```bash
# Download only symbol
easyeda2kicad --lcsc_id <LCSC_ID> --symbol
```

## Output Locations

### Footprints

```
~/Documents/Kicad/easyeda2kicad/easyeda2kicad.pretty/
└── *.kicad_mod
```

### Symbols

```
~/Documents/Kicad/easyeda2kicad/
└── easyeda2kicad.kicad_sym
```

**Important:** Symbols are added to a single `.kicad_sym` file, not separate files like footprints.

## Project Structure

```
footprints/
├── kicad/
│   └── *.kicad_mod          # KiCad footprint files
├── images/
│   └── *.svg                # Exported SVG images (for documentation)
└── scripts/
    └── clean-svg-refs.py    # Script to clean SVG exports

symbols/
└── zudo-pd.kicad_sym        # Project symbol library (copied from download)

~/Documents/Kicad/easyeda2kicad/  (download location)
├── easyeda2kicad.pretty/
│   └── *.kicad_mod          # Downloaded footprints
└── easyeda2kicad.kicad_sym  # Downloaded symbols (all in one file)
```

## Complete Download Workflow

### 1. Download All Project Parts

Download all components with BOTH footprints and symbols:

```bash
# USB-C Connector
easyeda2kicad --lcsc_id C2927029 --footprint --symbol

# CH224D - USB PD Controller
easyeda2kicad --lcsc_id C3975094 --footprint --symbol

# LM2596S-ADJ - Buck Converter
easyeda2kicad --lcsc_id C347423 --footprint --symbol

# ICL7660M - Voltage Inverter
easyeda2kicad --lcsc_id C356724 --footprint --symbol

# L7812CV - +12V Regulator
easyeda2kicad --lcsc_id C2914 --footprint --symbol

# L7805ABD2T - +5V Regulator
easyeda2kicad --lcsc_id C86206 --footprint --symbol

# CJ7912 - -12V Regulator
easyeda2kicad --lcsc_id C94173 --footprint --symbol

# SMAJ15A - TVS Diode
easyeda2kicad --lcsc_id C347883 --footprint --symbol

# SD05 - TVS Diode (5V)
easyeda2kicad --lcsc_id C502527 --footprint --symbol
```

### 2. Copy to Project

```bash
# Create symbols directory
mkdir -p /Users/takazudo/repos/personal/zudo-pd/symbols

# Copy footprints
cp ~/Documents/Kicad/easyeda2kicad/easyeda2kicad.pretty/*.kicad_mod \
   /Users/takazudo/repos/personal/zudo-pd/footprints/kicad/

# Copy symbols
cp ~/Documents/Kicad/easyeda2kicad/easyeda2kicad.kicad_sym \
   /Users/takazudo/repos/personal/zudo-pd/symbols/zudo-pd.kicad_sym
```

### 3. Add Libraries to KiCad

**Add Symbol Library:**

1. Preferences → Manage Symbol Libraries
2. Click "Project Specific Libraries" tab
3. Add library:
   - Nickname: `zudo-pd`
   - Library Path: `${KIPRJMOD}/symbols/zudo-pd.kicad_sym`
   - Plugin Type: `KiCad`

**Add Footprint Library** (if not done yet):

1. Preferences → Manage Footprint Libraries
2. Click "Project Specific Libraries" tab
3. Add library:
   - Nickname: `zudo-pd`
   - Library Path: `${KIPRJMOD}/footprints/kicad/zudo-power.pretty`

### 4. Verify Files

```bash
# Check footprints
ls -l /Users/takazudo/repos/personal/zudo-pd/footprints/kicad/*.kicad_mod

# Check symbols
ls -l /Users/takazudo/repos/personal/zudo-pd/symbols/zudo-pd.kicad_sym
```

## Footprint File Format

KiCad footprint files (`.kicad_mod`) are text files in S-expression format:

```lisp
(footprint "QFN-20_L3.0-W3.0-P0.40-BL-EP1.7"
  (layer "F.Cu")
  (attr smd)
  (fp_text reference "REF**" (at 0 -2.5) (layer "F.SilkS"))
  (fp_text value "CH224D" (at 0 2.5) (layer "F.Fab"))
  (pad "1" smd rect (at -1.4 -1.0) (size 0.25 0.6) (layers "F.Cu" "F.Paste" "F.Mask"))
  ...
)
```

## Troubleshooting

### Problem: "easyeda2kicad: command not found"

**Solution**: Ensure pip installed the package correctly and it's in your PATH:

```bash
which easyeda2kicad
# Should show: /path/to/python/bin/easyeda2kicad
```

If not found, try:

```bash
python -m easyeda2kicad --version
```

### Problem: "Part not found"

**Solution**:

- Verify the LCSC ID is correct
- Check if the part exists on LCSC.com
- Try using the EasyEDA part number instead

### Problem: Download fails or times out

**Solution**:

- Check internet connection
- Try again (server might be temporarily down)
- Use `--full` flag for more detailed error messages:
  ```bash
  easyeda2kicad --lcsc_id C3975094 --footprint --full
  ```

## Advanced Options

### Download Symbol and 3D Model

```bash
# Download footprint, symbol, and 3D model
easyeda2kicad --lcsc_id C3975094 --footprint --symbol --3d
```

### Specify Output Directory

```bash
easyeda2kicad --lcsc_id C3975094 --footprint --output /custom/path/
```

### Download by EasyEDA ID

```bash
easyeda2kicad --easyeda_id <EASYEDA_ID> --footprint
```

## Next Steps

After downloading footprints:

1. [Create Footprint SVG Files](./create-footprint-svg.md) - Export SVGs for documentation
2. Review footprints in KiCad PCB editor
3. Add footprints to your PCB design

## References

- [easyeda2kicad.py GitHub](https://github.com/uPesy/easyeda2kicad.py)
- [LCSC Component Search](https://www.lcsc.com/)
- [EasyEDA Component Library](https://easyeda.com/)
- [KiCad Documentation](https://docs.kicad.org/)

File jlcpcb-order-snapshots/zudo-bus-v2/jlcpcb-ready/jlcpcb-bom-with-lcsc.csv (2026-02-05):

Comment | Designator | Footprint | JLCPCB Part #
2541WR-2X08P | J101,J102,J103,J104,J105,J106,J107,J108 | eurorack-power-16pin | C5383092
Faston -12V | P3 | power-faston-pin | C305825
Faston GND | P4 | power-faston-pin | C305825
Faston +12V | P5 | power-faston-pin | C305825
Faston +5V | P6 | power-faston-pin | C305825
SS14 | D7,D8 | SMA_L4.2-W2.6-LS5.0-RD_1 | C2480
0.1uF | C101,C102,C103,C104,C105,C106,C107,C108,C201,C202,C203,C204,C205,C206,C207,C208 | C0603 | C14663
Red | LED1/-12V | LED0603-RD | C2286
1k | R1,R2,R3 | R0805 | C25623
SMF12CA_C353317 | D1,D3 | SOD-123FL_L2.8-W1.8-LS3.7-BI | C353317
BSMD1812-150-33V | F2,F3 | F1812 | C883154
WJ500V-5.08-2P-14-00A | P1,P2 | CONN-TH_2P-P5.00_WJ500V-5.08-2P | C8465
Green | LED2/+12V | LED0603-FD | C19171392
BSMD1812-200-30V | F1 | F1812 | C960026
SM4007PL | D2,D4,D6 | SOD-123F_L2.8-W1.8-LS3.7-RD | C64898
3pin jumper | JP1 | HDR-TH_3P-P2.54-V-M-1 | C49257
Blue | LED3/+5V | LED0603-RD | C5382145
SMF5.0CA_C908214 | D5 | SOD-123FL_L2.8-W1.8-LS3.7-BI | C908214
AMS1117-5.0 | U1 | SOT-223-3_TabPin2 | C6187
22uF | C2 | C0805 | C45783
BSMD1812-110-33V | F4 | F1812 | C883150
10uF | C1 | C0805 | C15850

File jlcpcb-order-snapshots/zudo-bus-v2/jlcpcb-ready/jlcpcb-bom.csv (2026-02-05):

Comment | Designator | Footprint | JLCPCB Part #
2541WR-2X08P | J101,J102,J103,J104,J105,J106,J107,J108 | eurorack-power-16pin
Faston -12V | P3 | power-faston-pin
Faston GND | P4 | power-faston-pin
Faston +12V | P5 | power-faston-pin
Faston +5V | P6 | power-faston-pin
SS14 | D7,D8 | SMA_L4.2-W2.6-LS5.0-RD_1
0.1uF | C101,C102,C103,C104,C105,C106,C107,C108,C201,C202,C203,C204,C205,C206,C207,C208 | C0603
Red | LED1/-12V | LED0603-RD
1k | R1,R2,R3 | R0805
TestPoint +5V IN | TP3 | TestPoint_Pad_D1.5mm
TestPoint -12V Rail | TP2 | TestPoint_Pad_D1.5mm
SMF12CA_C353317 | D1,D3 | SOD-123FL_L2.8-W1.8-LS3.7-BI
BSMD1812-150-33V | F2,F3 | F1812
TestPoint +5V Rail | TP5 | TestPoint_Pad_D1.5mm
WJ500V-5.08-2P-14-00A | P1,P2 | CONN-TH_2P-P5.00_WJ500V-5.08-2P
Green | LED2/+12V | LED0603-FD
BSMD1812-200-30V | F1 | F1812
SM4007PL | D2,D4,D6 | SOD-123F_L2.8-W1.8-LS3.7-RD
3pin jumper | JP1 | HDR-TH_3P-P2.54-V-M-1
Blue | LED3/+5V | LED0603-RD
SMF5.0CA_C908214 | D5 | SOD-123FL_L2.8-W1.8-LS3.7-BI
AMS1117-5.0 | U1 | SOT-223-3_TabPin2
22uF | C2 | C0805
TestPoint GND | TP6 | TestPoint_Pad_D1.5mm
TestPoint LDO +5V | TP4 | TestPoint_Pad_D1.5mm
TestPoint +12V Rail | TP1 | TestPoint_Pad_D1.5mm
BSMD1812-110-33V | F4 | F1812
10uF | C1 | C0805

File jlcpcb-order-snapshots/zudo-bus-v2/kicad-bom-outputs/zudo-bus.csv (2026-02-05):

Id | Designator | Footprint | Quantity | Designation | Supplier and ref
1 | J104,J105,J108,J107,J103,J102,J106,J101 | eurorack-power-16pin | 8 | 2541WR-2X08P
2 | P3 | power-faston-pin | 1 | Faston -12V
3 | P4 | power-faston-pin | 1 | Faston GND
4 | P5 | power-faston-pin | 1 | Faston +12V
5 | P6 | power-faston-pin | 1 | Faston +5V
6 | D7,D8 | SMA_L4.2-W2.6-LS5.0-RD_1 | 2 | SS14
7 | C105,C102,C104,C207,C205,C103,C108,C202,C206,C101,C203,C201,C208,C204,C106,C107 | C0603 | 16 | 0.1uF
8 | LED1/-12V | LED0603-RD | 1 | Red
9 | R1,R3,R2 | R0805 | 3 | 1k
10 | TP3 | TestPoint_Pad_D1.5mm | 1 | TestPoint +5V IN
11 | TP2 | TestPoint_Pad_D1.5mm | 1 | TestPoint -12V Rail
12 | D1,D3 | SOD-123FL_L2.8-W1.8-LS3.7-BI | 2 | SMF12CA_C353317
13 | F2,F3 | F1812 | 2 | BSMD1812-150-33V
14 | TP5 | TestPoint_Pad_D1.5mm | 1 | TestPoint +5V Rail
15 | P2,P1 | CONN-TH_2P-P5.00_WJ500V-5.08-2P | 2 | WJ500V-5.08-2P-14-00A
16 | LED2/+12V | LED0603-FD | 1 | Green
17 | F1 | F1812 | 1 | BSMD1812-200-30V
18 | D6,D2,D4 | SOD-123F_L2.8-W1.8-LS3.7-RD | 3 | SM4007PL
19 | JP1 | HDR-TH_3P-P2.54-V-M-1 | 1 | 3pin jumper
20 | LED3/+5V | LED0603-RD | 1 | Blue
21 | D5 | SOD-123FL_L2.8-W1.8-LS3.7-BI | 1 | SMF5.0CA_C908214
22 | U1 | SOT-223-3_TabPin2 | 1 | AMS1117-5.0
23 | C2 | C0805 | 1 | 22uF
24 | TP6 | TestPoint_Pad_D1.5mm | 1 | TestPoint GND
25 | TP4 | TestPoint_Pad_D1.5mm | 1 | TestPoint LDO +5V
26 | TP1 | TestPoint_Pad_D1.5mm | 1 | TestPoint +12V Rail
27 | F4 | F1812 | 1 | BSMD1812-110-33V
28 | C1 | C0805 | 1 | 10uF

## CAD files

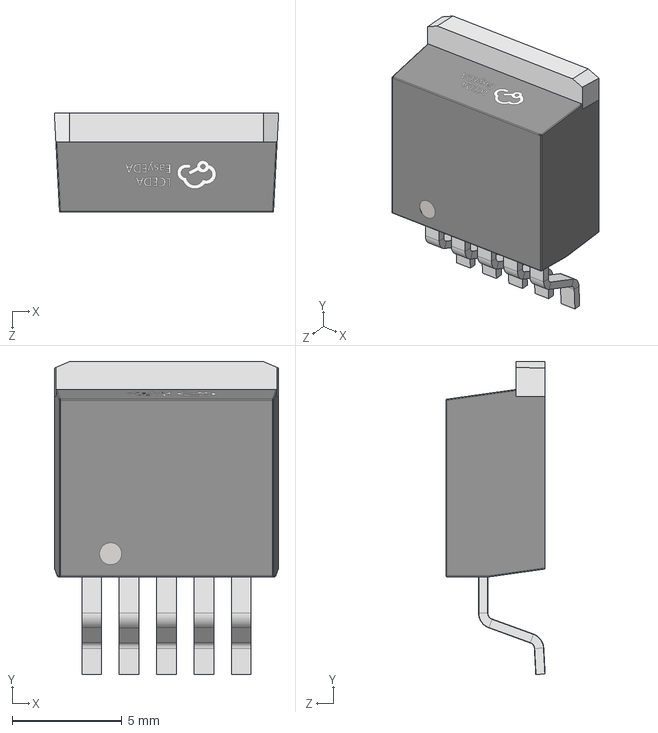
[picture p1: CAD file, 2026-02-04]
footprints/3dshapes/TO-263-5-5P_L10.2-W8.7-H4.5-LS14.4-P1.70.step
10.2 x 14.2 x 4.51 mm

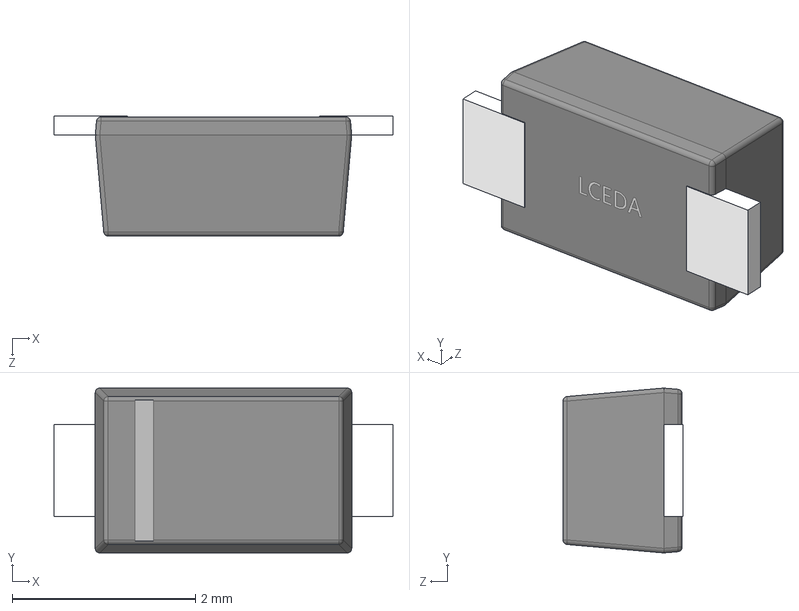
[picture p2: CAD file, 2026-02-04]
footprints/3dshapes/SOD-123FL_L2.8-W1.8-LS3.7-RD-1.step
3.70 x 1.80 x 1.31 mm

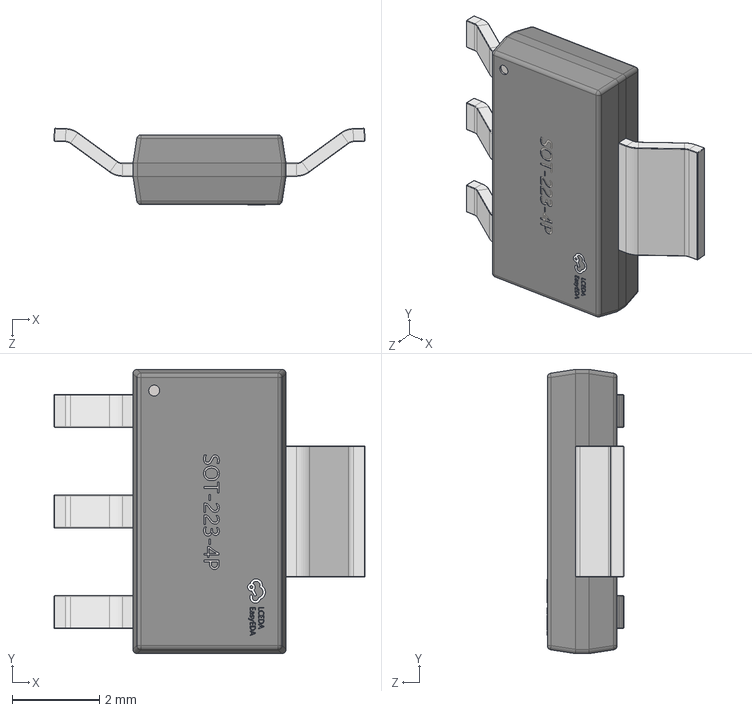
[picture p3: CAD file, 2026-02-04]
footprints/3dshapes/SOT-223-4P_L6.5-W3.5-H1.6-LS7.0-P2.30.step
7.11 x 6.50 x 1.75 mm

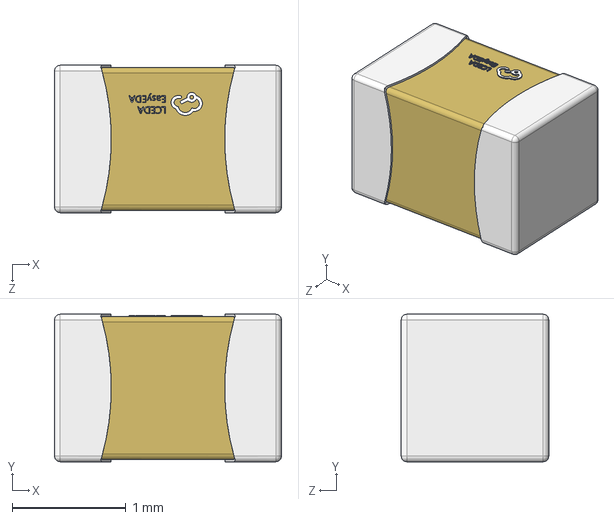
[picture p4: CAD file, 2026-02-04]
footprints/3dshapes/C0805_L2.0-W1.3-H1.3.step
2.00 x 1.30 x 1.30 mm

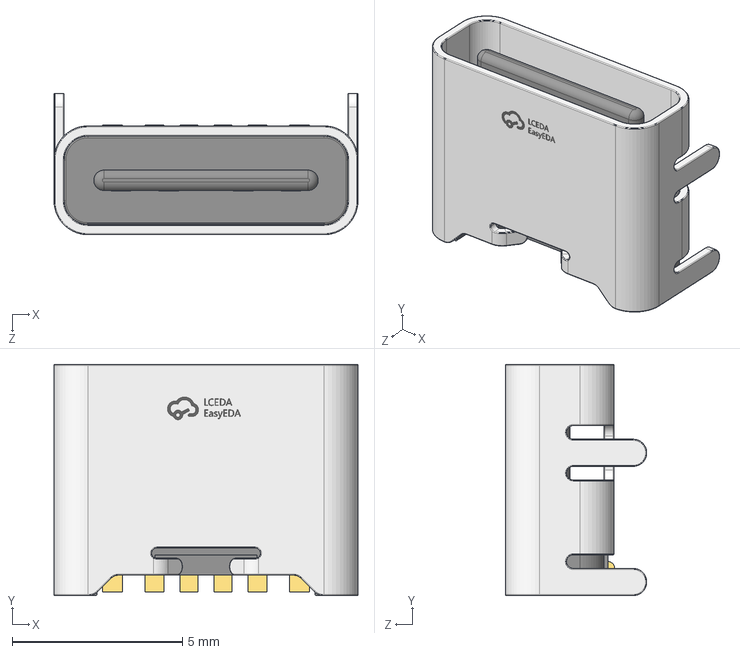
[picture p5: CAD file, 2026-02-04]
footprints/3dshapes/TYPE-C-SMD_6P-L8.9-W6.8-H3.2-P1.00.step
8.94 x 6.80 x 4.16 mm

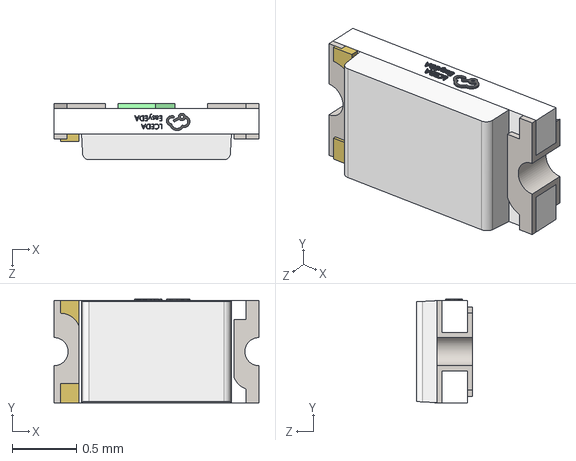
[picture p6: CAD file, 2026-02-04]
footprints/3dshapes/LED0603-FD_BLUE.step
1.60 x 0.81 x 0.44 mm

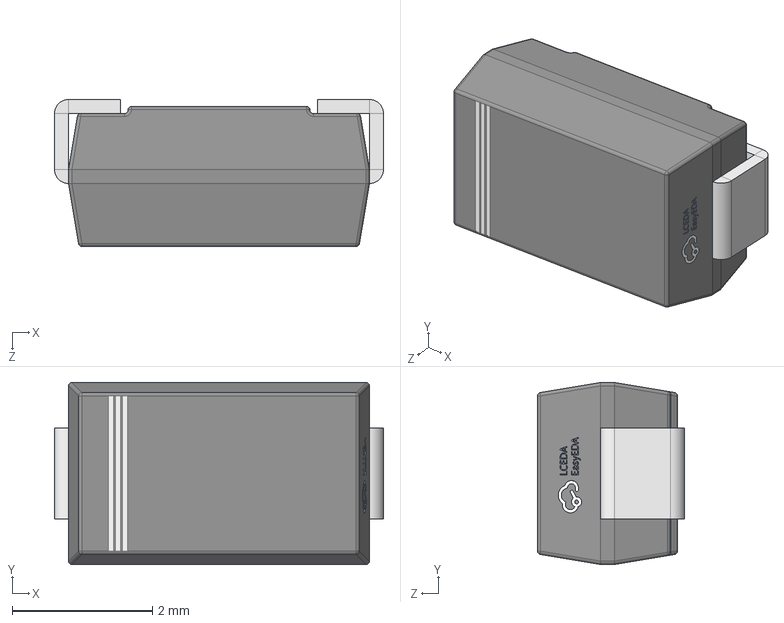
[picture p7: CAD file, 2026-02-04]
footprints/3dshapes/SMA_L4.3-W2.6-LS5.2-RD.step
4.70 x 2.60 x 2.10 mm

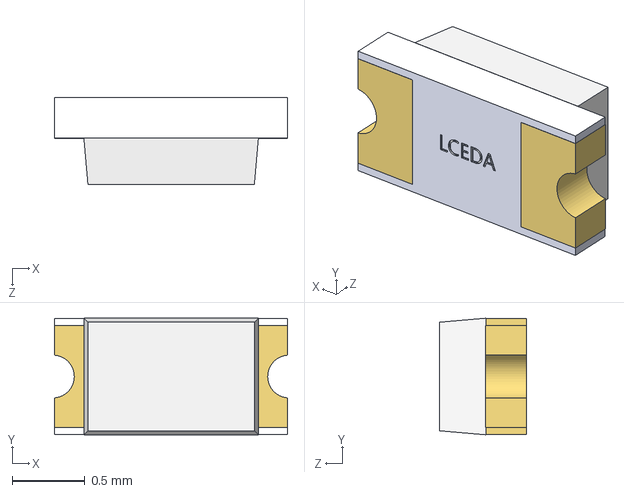
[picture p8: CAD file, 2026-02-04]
footprints/3dshapes/LED0603_Inf.step
1.60 x 0.802 x 0.601 mm

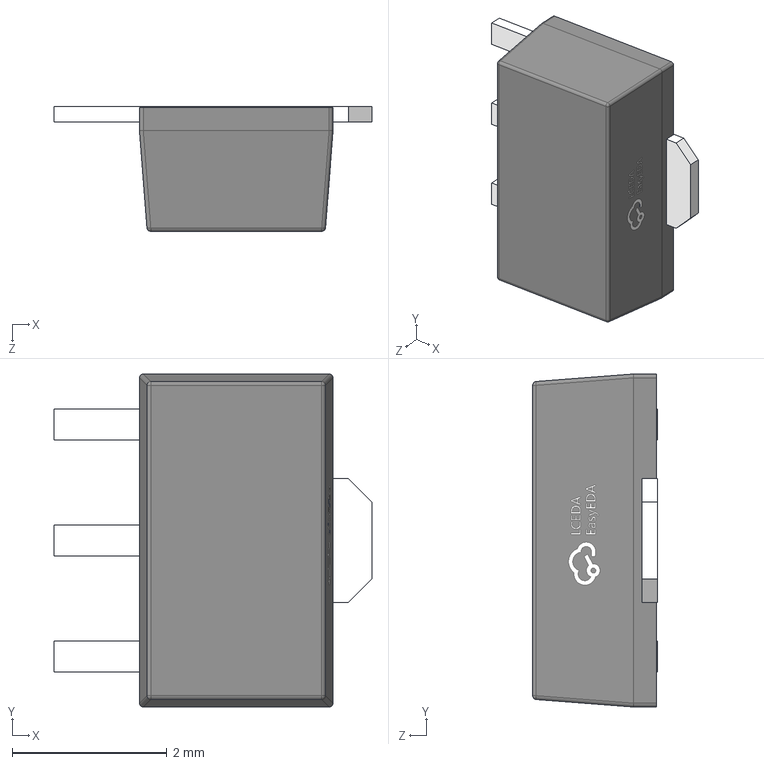
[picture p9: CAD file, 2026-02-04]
footprints/3dshapes/SOT-89-3_L4.3-W2.5-H1.6-LS4.1-P1.50.step
4.10 x 4.30 x 1.61 mm

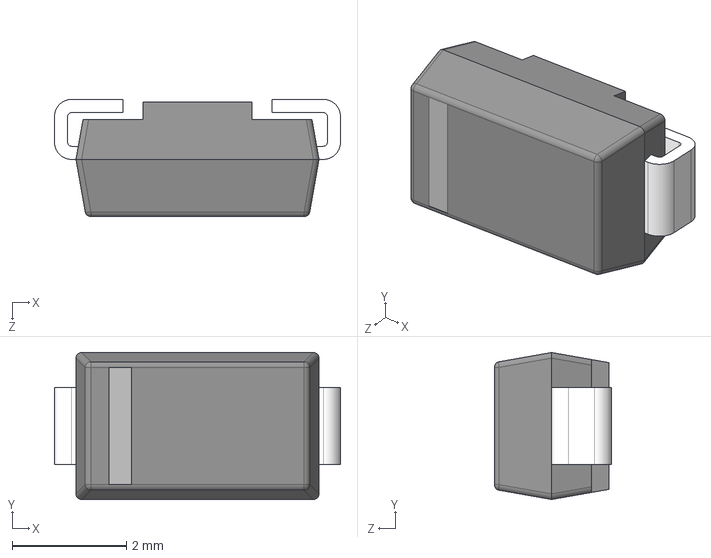
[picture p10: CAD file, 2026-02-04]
footprints/3dshapes/SMA_L4.2-W2.6-LS5.0-RD_1.step
5.00 x 2.57 x 2.05 mm

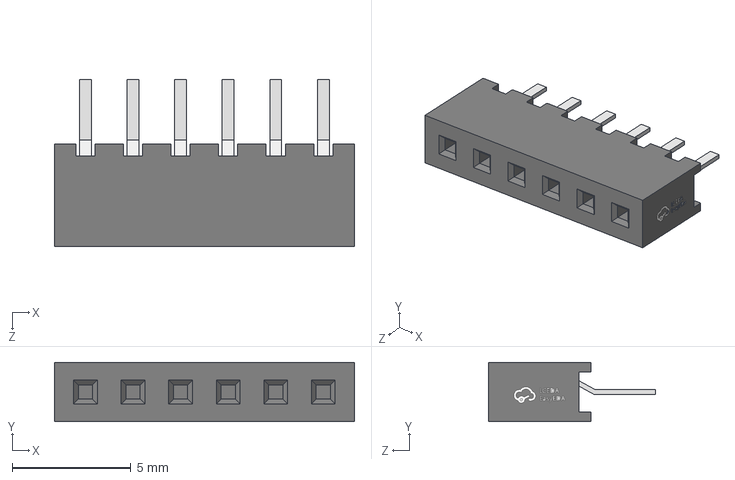
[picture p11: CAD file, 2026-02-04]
footprints/3dshapes/HDR-TH_6P-P2.00-F-LI-1X6P.step
12.6 x 2.50 x 7.00 mm

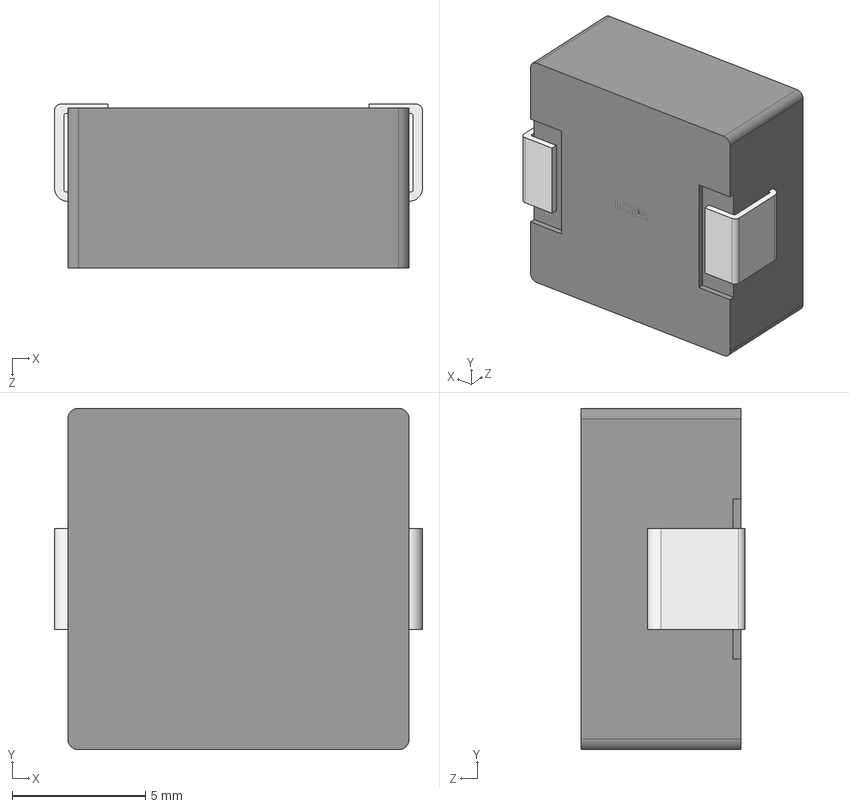
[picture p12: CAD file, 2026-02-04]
footprints/3dshapes/IND-SMD_L13.8-W12.8.step
13.8 x 12.8 x 6.15 mm

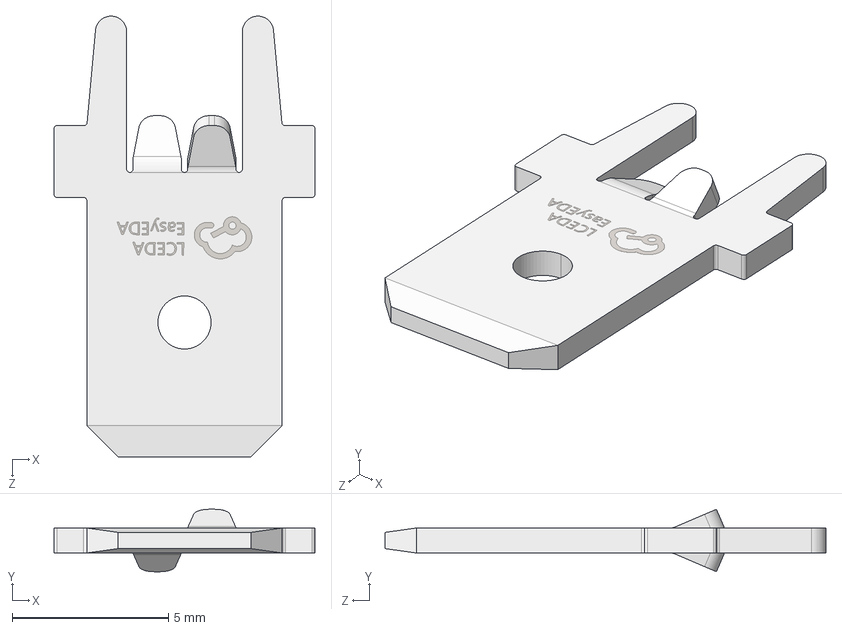
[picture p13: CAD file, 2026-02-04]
footprints/3dshapes/CONN-TH_L6.3-W0.8-EST026.step
8.35 x 2.00 x 14.1 mm

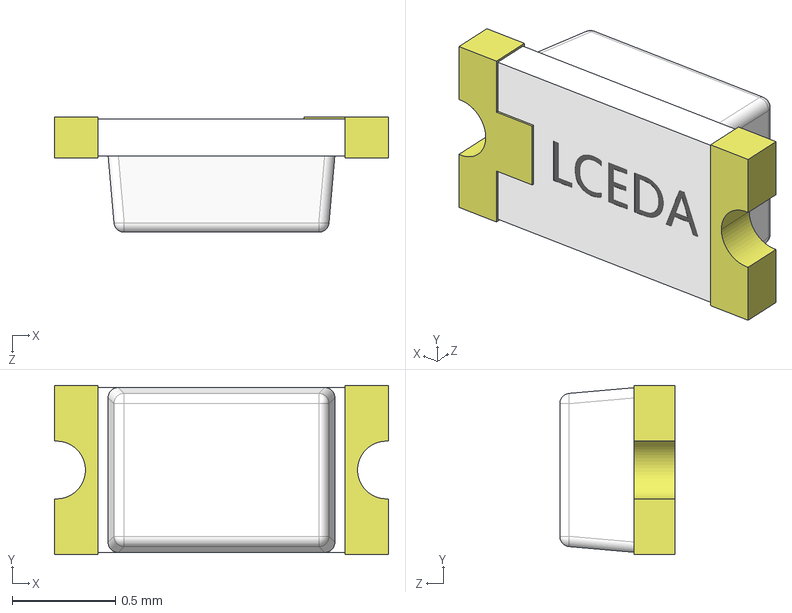
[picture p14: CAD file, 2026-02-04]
footprints/3dshapes/LED0603-RD.step
1.62 x 0.82 x 0.56 mm

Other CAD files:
footprints/3dshapes/CAP-SMD_BD6.3-L6.6-W6.6-LS7.3-FD.step
footprints/3dshapes/F1206_L3.2-W1.7-H0.6.step
footprints/3dshapes/QFN-20_L3.0-W3.0-P0.40-BL-EP1.7.step
footprints/3dshapes/F1812_L4.5-W3.2-H1.0.step
footprints/3dshapes/C0603_L1.6-W0.8-H0.8.step
footprints/3dshapes/C1206_L3.2-W1.6-H1.3.step
footprints/3dshapes/CAP-SMD_BD10.0-L10.3-W10.3-H10.2.step
footprints/3dshapes/CAP-SMD_BD18.0-L19.0-W19.0-LS20.4-FD.step
footprints/3dshapes/CAP-SMD_BD6.3-L6.6-W6.6-FD.step
footprints/3dshapes/CAP-SMD_BD6.3-L6.6-W6.6-LS7.3-FD_H7.7.step
footprints/3dshapes/CAP-SMD_L4.3-W4.3-H5.3-LS5.1.step
footprints/3dshapes/CONN-TH_1217754-1.step
footprints/3dshapes/CONN-TH_2P-P5.00_WJ500V-5.08-2P.step
footprints/3dshapes/D-FLAT_L4.3-W2.6-LS5.3-RD.step
footprints/3dshapes/DC-IN-TH_DC550250-0366-2H.step
footprints/3dshapes/DO-214AC_L4.3-W2.7-LS5.0-RD.step
footprints/3dshapes/F1210_L3.2-W2.6-H0.6.step
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

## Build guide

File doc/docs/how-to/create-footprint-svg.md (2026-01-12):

---
sidebar_position: 3
---

# Create Footprint SVG Files for Documentation

This guide explains how to export KiCad footprints to SVG format and prepare them for use in the documentation.

## Overview

The documentation displays clickable footprint previews on each component page. This workflow converts KiCad `.kicad_mod` files to clean SVG images.

## Prerequisites

- KiCad 9.0.6 or later (with `kicad-cli` command)
- Python 3 (for cleanup script)
- KiCad footprints downloaded (see [KiCad Parts Download Guide](./kicad-parts-download.md))

## Verify KiCad CLI

```bash
kicad-cli --version
# Should show: Version: 9.0.6 or later
```

If `kicad-cli` is not found, you need to add it to your PATH:

**macOS:**

```bash
export PATH="/Applications/KiCad/KiCad.app/Contents/MacOS:$PATH"
```

**Linux:**

```bash
# Usually already in PATH after KiCad installation
```

**Windows:**

```powershell
# Add KiCad installation directory to PATH
# Typically: C:\Program Files\KiCad\bin
```

## Workflow

### Step 1: Prepare .pretty Directory

KiCad CLI requires footprints in a `.pretty` directory structure:

```bash
cd /Users/takazudo/repos/personal/zudo-pd/footprints/kicad

# Create .pretty directory
mkdir -p zudo-power.pretty

# Copy .kicad_mod files
cp *.kicad_mod zudo-power.pretty/
```

### Step 2: Export to SVG

Export all footprints to SVG format with black-and-white rendering:

```bash
cd /Users/takazudo/repos/personal/zudo-pd/footprints

# Export SVGs
kicad-cli fp export svg kicad/zudo-power.pretty -o images --black-and-white
```

**Output:** SVG files are saved to `footprints/images/`

### Step 3: Clean SVG Files

Remove KiCad placeholder text (REF**, VAL**) from SVGs using the cleanup script:

```bash
cd /Users/takazudo/repos/personal/zudo-pd/footprints

# Run cleanup script
python3 scripts/clean-svg-refs.py images/
```

The script removes:

- `REF**` placeholder text
- `VAL**` placeholder text
- Both text elements and stroked-text path groups

### Step 4: Copy to Documentation

```bash
cd /Users/takazudo/repos/personal/zudo-pd/footprints

# Copy cleaned SVGs to documentation fragments
cp images/*.svg ../doc/docs/_fragments/footprints/
```

### Step 5: Verify Results

Check that SVGs are clean:

```bash
cd /Users/takazudo/repos/personal/zudo-pd/doc/docs/_fragments/footprints

# Quick check: should find NO instances of REF** in SVG files
grep -l "REF\*\*" *.svg
# (No output = success)
```

## Directory Structure

```
project/
├── footprints/
│   ├── kicad/
│   │   ├── *.kicad_mod              # Original KiCad footprints
│   │   └── zudo-power.pretty/       # .pretty directory for export
│   │       └── *.kicad_mod
│   ├── images/
│   │   └── *.svg                    # Exported and cleaned SVGs
│   └── scripts/
│       └── clean-svg-refs.py        # Cleanup script
└── doc/
    └── docs/
        └── _fragments/
            └── footprints/
                └── *.svg            # Final SVGs for documentation
```

## Cleanup Script Details

### Location

`/Users/takazudo/repos/personal/zudo-pd/footprints/scripts/clean-svg-refs.py`

### What It Does

The script processes SVG files to remove KiCad placeholders:

1. **Text Elements**: Removes `<text>` elements containing `REF**` or `VAL**`
2. **Stroked-Text Groups**: Removes path-based text rendered as vector shapes
3. **Preserves**: All footprint geometry, pads, and silkscreen

### Usage

```bash
# Clean all SVGs in a directory
python3 clean-svg-refs.py /path/to/svg/directory/

# The script modifies files in-place
# Creates no backup - commit to git first!
```

### Verification

The script reports how many elements were removed:

```
Processing: QFN-20_L3.0-W3.0-P0.40-BL-EP1.7.svg - Removed 2 elements
Processing: TO-263-5_L10.2-W8.9-P1.70-BR.svg - Removed 2 elements
...
✓ Processed 28 SVG files
```

## Using Footprints in Documentation

### Import and Use FootprintSvg Component

In MDX files (e.g., component pages):

```jsx
import FootprintSvg from '@site/src/components/FootprintSvg';
import CH224D from '@site/static/footprints-svg/QFN-20_L3.0-W3.0-P0.40-BL-EP1.7.svg';

<FootprintSvg src={CH224D} alt="CH224D QFN-20 Package" minWidth="300px" minHeight="300px" />;
```

### Component Features

- Click-to-enlarge (90vw × 90vh fullscreen dialog)
- Background color: `oklch(86.9% 0.005 56.366)`
- Padding: 20px
- Maintains aspect ratio

## Troubleshooting

### Problem: kicad-cli not found

**Solution**: Add KiCad to PATH (see "Verify KiCad CLI" above)

### Problem: Export fails with "Library not found"

**Solution**: Ensure footprints are in a `.pretty` directory:

```bash
# Correct structure:
footprints/kicad/zudo-power.pretty/QFN-20_L3.0-W3.0-P0.40-BL-EP1.7.kicad_mod

# Wrong structure:
footprints/kicad/QFN-20_L3.0-W3.0-P0.40-BL-EP1.7.kicad_mod
```

### Problem: SVG still shows REF\*\* after cleanup

**Solution**:

1. Check that cleanup script ran successfully
2. Some SVGs may have additional text elements - inspect manually:
   ```bash
   grep "REF\*\*" problem-file.svg
   ```
3. Update cleanup script if needed

### Problem: SVG appears blank in documentation

**Solution**:

1. Verify SVG file is not corrupted:
   ```bash
   head -5 footprint.svg
   # Should show valid SVG header
   ```
2. Check import path is correct
3. Verify file was copied to `docs/_fragments/footprints/`

## Complete Example Workflow

```bash
# 1. Navigate to footprints directory
cd /Users/takazudo/repos/personal/zudo-pd/footprints

# 2. Create .pretty directory structure
mkdir -p kicad/zudo-power.pretty
cp kicad/*.kicad_mod kicad/zudo-power.pretty/

# 3. Export to SVG
kicad-cli fp export svg kicad/zudo-power.pretty -o images --black-and-white

# 4. Clean SVG files
python3 scripts/clean-svg-refs.py images/

# 5. Verify cleanup
grep -l "REF\*\*" images/*.svg
# (No output = success)

# 6. Copy to documentation
cp images/*.svg ../doc/docs/_fragments/footprints/

# 7. Verify in documentation
cd ../doc
npm start
# Open browser to http://localhost:3000/docs/components
```

## Next Steps

- [View Footprint Preview](../misc/footprint-preview) - See all footprints in the documentation
- Update component pages to include new footprints
- Commit changes to git

## References

- [KiCad CLI Documentation](https://docs.kicad.org/master/en/cli/cli.html)
- [SVG Specification](https://www.w3.org/TR/SVG2/)

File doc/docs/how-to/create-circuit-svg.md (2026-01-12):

---
sidebar_position: 4
---

# Create Circuit SVG Files for Documentation

This guide explains how to create professional circuit diagrams using schemdraw and integrate them into the documentation.

## Overview

Circuit diagrams are generated using the schemdraw Python library with a systematic workflow that ensures electrical accuracy and visual clarity.

## Prerequisites

- Python 3.7 or later
- schemdraw library installed (`pip install schemdraw`)
- `/schemdraw-circuit-generator` skill configured

## Design Workflow

### Step 1: Collect Parts Data

Use the `/jlcpcb` skill to search for and verify component availability:

```bash
# Example: Search for buck converter
/jlcpcb LM2596S
```

Document:

- Part numbers
- Specifications (voltage ratings, current ratings, package types)
- JLCPCB stock codes
- Key specifications (resistance, capacitance, inductance, etc.)

### Step 2: Create ASCII Art Draft

Start with ASCII art circuit diagram in markdown code blocks. This serves as the specification for the final diagram.

**Example:**

```
+15V ─────┬─── L1: 100µH ──┬─── D1 ──┬─── C3: 470µF ──┬─→ +13.5V
          │    (4.5A)      │   SS34  │    (25V)       │
          │                │    ↓    │                │
          │           ┌────┴─────────┴──┐             │
          │           │5  VIN      OUT │4────────────┤
          └───────────┤3  ON        FB │2─────┬──────┘
                      │1  GND          │      │
                      └────────────────┘      │
                              │               │
                             GND          ┌───┴───┐
                                          │ R1    │ 10kΩ
                                          │ 10kΩ  │
                                          └───┬───┘
                                          ┌───┴───┐
                                          │ R2    │ 1kΩ
                                          │ 1kΩ   │
                                          └───┬───┘
                                              │
                                             GND
```

**Create Connection List:**

```
Connections:
- +15V input → U2 (LM2596S) pin 5 (VIN)
- +15V input → C5 (100µF) → GND
- U2 pin 3 (ON) → +15V (always enabled)
- U2 pin 4 (VOUT) → Switching node
- Switching node → L1 (100µH) → +13.5V Output
- Switching node → D1 (SS34 cathode)
- D1 (SS34 anode) → GND
- +13.5V → C3 (470µF) → GND
- U2 pin 2 (FB) → R1 (10kΩ) → Tap
- Tap → R2 (1kΩ) → GND
- Tap → +13.5V (feedback sense)
- U2 pin 1 (GND) → GND
```

### Step 3: Generate Schemdraw Diagram

Use the `/schemdraw-circuit-generator` skill to create professional circuit diagram:

```bash
/schemdraw-circuit-generator
```

Provide the connection list from Step 2 as the specification.

**Configuration:**

- **Theme**: Black foreground with transparent background (default)
- **Font**: Arial, 11pt
- **Color**: Black lines and text
- **Background**: Transparent (allows container background to show through)

**Example Python Code:**

```python
#!/usr/bin/env python3
"""
LM2596S-ADJ Buck Converter: +15V → +13.5V
Complete circuit with transparent background, black foreground, Arial font
"""

import schemdraw
from schemdraw import elements as elm

with schemdraw.Drawing(
    font='Arial',         # Sans-serif font
    fontsize=11,
    color='black',        # Foreground: black
    transparent=True      # Transparent background
) as d:
    d.config(unit=3)

    # IC definition
    ic = elm.Ic(
        pins=[
            elm.IcPin(name='GND', pin='3', side='left', slot='1/3'),
            elm.IcPin(name='ON', pin='5', side='left', slot='2/3'),
            elm.IcPin(name='VIN', pin='1', side='left', slot='3/3'),
            elm.IcPin(name='FB', pin='4', side='right', slot='1/2'),
            elm.IcPin(name='VOUT', pin='2', side='right', slot='2/2'),
        ],
        edgepadW=2.5,
        edgepadH=0.8,
        pinspacing=1.0,
        leadlen=1.0
    ).label('U2\nLM2596S', loc='center', fontsize=10)

    # Add all other components following the connection list...

    # Save to docs/_fragments
    import os
    script_dir = os.path.dirname(os.path.abspath(__file__))
    output_path = os.path.join(script_dir, '../docs/_fragments/buck-u2-diagram.svg')
    d.save(output_path)

print("✓ Buck converter diagram generated with transparent background")
```

### Step 4: Execute and Save

```bash
# Run the Python script
cd /Users/takazudo/repos/personal/zudo-pd/diagram-sources
python3 buck-u2-diagram.py

# Output: SVG saved to /doc/docs/_fragments/buck-u2-diagram.svg
```

### Step 5: Integrate into Documentation

Import and use the SVG in MDX files using the `CircuitSvg` component:

```jsx
import CircuitSvg from '@site/src/components/CircuitSvg';
import BuckU2Diagram from '@site/static/circuits/buck-u2-diagram.svg';

<CircuitSvg src={BuckU2Diagram} alt="LM2596S Buck Converter U2" />;
```

### Step 6: Hide ASCII Art (Optional)

Keep the ASCII art draft but collapse it using HTML `<details>` element:

```html
<details>
  <summary>View ASCII art version</summary>
</details>
```

[ASCII diagram here]

```

</details>
```

Keep the connection list visible for reference.

## Directory Structure

```
project/
├── diagram-sources/
│   └── *.py                        # Schemdraw Python source files
├── doc/
│   └── docs/
│       └── _fragments/
│           ├── CircuitSvg.jsx      # Click-to-enlarge component
│           ├── CircuitDialog.jsx   # Fullscreen dialog
│           └── *.svg               # Generated circuit diagrams
```

## Schemdraw Configuration

### Default Settings

```python
with schemdraw.Drawing(
    font='Arial',         # Sans-serif font
    fontsize=11,
    color='black',        # Black foreground
    transparent=True      # Transparent background
) as d:
    d.config(unit=3)      # Scale factor
    # ... circuit elements ...
```

### Why Transparent Background with Black Foreground?

- Allows HTML container background (`oklch(86.9% 0.005 56.366)`) to show through
- Black lines and text are visible on light container backgrounds
- Works seamlessly with web-based documentation (Docusaurus)
- Professional appearance with clean contrast
- Integrates with any light-themed documentation

### Alternative: Solid Background (If Needed)

```python
# Dark theme with solid black background
with schemdraw.Drawing(
    font='Arial',
    fontsize=11,
    color='white',
    bgcolor='black'
) as d:
    # ... circuit elements ...
```

## Best Practices

### 1. Consistent Label Positioning

For vertical components (resistors, capacitors going up/down):

```python
# For components going upward
elm.Capacitor().up(2.0).label('C3\n470µF\n25V', loc='bot', ofst=0.5)
elm.Ground().flip()  # Flipped ground at top

# For components going downward
elm.Resistor().down().label('R1\n10kΩ', loc='bot', ofst=0.5)
elm.Ground()  # Normal ground at bottom
```

### 2. IC Edge Padding

Use adequate `edgepadW` parameter to prevent label overlap:

```python
ic = elm.Ic(
    pins=[...],
    edgepadW=2.5,  # Wider box prevents label overlap
    edgepadH=0.8,
    pinspacing=1.0,
    leadlen=1.0
).label('U2\nLM2596S', loc='center', fontsize=10)
```

### 3. Precise Junction Positioning

Calculate position mathematically for symmetrical connections:

```python
# For horizontal rail between two pins
junction_y = (ic.VIN[1] + ic.ON[1]) / 2

# Build entire rail at calculated height
elm.Dot(open=True).at((x_position, junction_y)).label('+15V', loc='left')
elm.Line().right(2.0)
elm.Dot()
```

### 4. Ground Symbol Orientation

```python
# Component going UP - flip ground
elm.Capacitor().up(2.0)
elm.Ground().flip()  # Ground symbol at top, points down

# Component going DOWN - normal ground
elm.Resistor().down()
elm.Ground()  # Ground symbol at bottom, points down
```

## Using CircuitSvg Component

The `CircuitSvg` component provides click-to-enlarge functionality:

```jsx
<CircuitSvg src={DiagramSvg} alt="Circuit Description" />
```

**Features:**

- Click to open fullscreen (90vw × 90vh)
- Background color: `oklch(86.9% 0.005 56.366)`
- Padding: 20px (both thumbnail and dialog)
- Maintains aspect ratio
- Keyboard accessible (Enter/Space to open)

## Troubleshooting

### Problem: Import errors in Python

**Solution**: Install schemdraw:

```bash
pip install schemdraw
```

### Problem: SVG has black background

**Solution**: Ensure you're using `transparent=True` instead of `bgcolor='black'`:

```python
# ✅ Correct
with schemdraw.Drawing(transparent=True) as d:

# ❌ Wrong
with schemdraw.Drawing(bgcolor='black') as d:
```

### Problem: Lines or text appear white on light background

**Solution**: Use `color='black'` for foreground:

```python
# ✅ Correct for transparent background
with schemdraw.Drawing(color='black', transparent=True) as d:

# ❌ Wrong (white lines invisible on light background)
with schemdraw.Drawing(color='white', transparent=True) as d:
```

### Problem: Labels overlap component symbols

**Solution**: Increase spacing and adjust label positions:

```python
# Increase overall spacing
d.config(unit=3)  # or larger

# Adjust individual spacing
HORIZONTAL_SPACING = 1.5  # Increase from 1.0
VERTICAL_SPACING = 1.5

# Adjust label positions
elm.Resistor().label('R1\n10kΩ', loc='top', ofst=0.2)
```

## Complete Example Workflow

```bash
# 1. Create connection list (ASCII art + detailed connections)
# Document in markdown: circuit-diagrams.md

# 2. Use schemdraw skill to generate Python code
/schemdraw-circuit-generator

# 3. Save Python code to /diagram-sources/
# Example: /diagram-sources/buck-u2-diagram.py

# 4. Execute Python script
cd /Users/takazudo/repos/personal/zudo-pd/diagram-sources
python3 buck-u2-diagram.py

# 5. Verify SVG output
ls -l doc/docs/_fragments/buck-u2-diagram.svg

# 6. Test in documentation
cd /Users/takazudo/repos/personal/zudo-pd/doc
npm start
# Open: http://localhost:3000/do../components/lm2596s-adj

# 7. Commit both Python source and SVG
git add diagram-sources/buck-u2-diagram.py
git add doc/docs/_fragments/buck-u2-diagram.svg
git commit -m "Add LM2596S buck converter circuit diagram"
```

## Quality Checklist

Before considering a circuit diagram complete:

- ✅ Parts verified in JLCPCB database
- ✅ Connection list is accurate and complete
- ✅ ASCII art draft follows all golden rules
- ✅ Schemdraw SVG generated with transparent background and black foreground
- ✅ Click-to-enlarge works correctly
- ✅ ASCII art hidden in `<details>` element (optional)
- ✅ Connection list remains visible
- ✅ Both SVG and Python source committed

## References

- [schemdraw Documentation](https://schemdraw.readthedocs.io/)
- schemdraw-circuit-generator Skill (Claude Code skill for circuit generation)
- [Circuit Diagrams Page](/docs/overview/circuit-diagrams)

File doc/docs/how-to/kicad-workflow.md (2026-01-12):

# KiCad Project Workflow

Complete workflow for creating a PCB design in KiCad, from schematic to manufacturing files.

## Prerequisites

**CRITICAL:** Before starting, ensure your KiCad project files are located at the repository root:

```
zudo-pd/          ← Repository root
├── zudo-pd.kicad_pro       ← Project file must be here
├── zudo-pd.kicad_sch       ← Schematic file
├── zudo-pd.kicad_pcb       ← PCB file (created later)
└── footprints/             ← Footprint library
    └── kicad/
        └── zudo-power.pretty/
```

The `${KIPRJMOD}` variable in KiCad points to the directory containing the `.kicad_pro` file. If your project is in a subdirectory (like `kicad/` or `pcb/`), relative paths to footprints and libraries won't resolve correctly.

## Overview

KiCad uses a modular workflow where you work with different editors in sequence:

1. **Symbol Editor** - Create/import schematic symbols
2. **Schematic Editor** - Draw circuit diagrams
3. **Footprint Editor** - Create/import PCB footprints
4. **PCB Editor** - Layout the physical board
5. **Manufacturing Output** - Generate Gerber files

## Stage 1: Symbol Management

### 1.1 Check Existing Libraries

Before creating custom symbols, check if they already exist in KiCad's standard libraries:

**Common libraries for this project:**

- `Device` - Resistors, capacitors, inductors, diodes, LEDs
- `Regulator_Linear` - LM78xx, LM79xx series
- `Regulator_Switching` - LM2596, buck/boost converters
- `Connector` - USB connectors, power jacks, headers
- `power` - GND, VCC, voltage symbols

**To check:**

1. Open **Symbol Editor**
2. File → Add Library... → Browse standard KiCad libraries
3. Search for your part number or category

### 1.2 Import Symbols from Standard Libraries

For parts already in KiCad libraries:

1. Open **Schematic Editor**
2. Press `A` (Add Symbol)
3. Search by part name (e.g., "LM7812", "USB_C_Receptacle")
4. Browse by library category if unsure

### 1.3 Create Custom Symbols

For parts NOT in standard libraries (like CH224Q, specialized ICs):

**Method 1: Import from EasyEDA/LCSC**

Use `easyeda2kicad.py` to download both symbols and footprints:

```bash
# Download symbol + footprint for CH224Q (LCSC ID: C970725)
easyeda2kicad --lcsc_id C970725 --symbol --footprint

# Files saved to:
# ~/Documents/Kicad/easyeda2kicad/easyeda2kicad.pretty/  (footprints)
# ~/Documents/Kicad/easyeda2kicad/easyeda2kicad.kicad_sym (symbols)
```

**Method 2: Manual Creation**

1. Open **Symbol Editor**
2. File → New Library... → Create project-specific library (e.g., `zudo-power.kicad_sym`)
3. Create New Symbol
4. Define:
   - Pin numbers and names (from datasheet)
   - Pin electrical types (input, output, power, passive)
   - Symbol shape (rectangle, specialized)
   - Reference designator (U, R, C, J, etc.)

**Best practices:**

- Match datasheet pin numbering exactly
- Use descriptive pin names (VIN, VOUT, FB, EN, etc.)
- Set correct electrical types for ERC (Electrical Rule Check)
- Add datasheet link in symbol properties

## Stage 2: Schematic Creation

### 2.1 Create New Schematic

1. Open **Schematic Editor** (`zudo-pd.kicad_sch`)
2. Set up page properties:
   - Title: "USB-PD Modular Synth Power Supply"
   - Revision: v1.0
   - Date: (automatic)
   - Company/Organization (optional)

### 2.2 Place Symbols

1. Press `A` to add symbols
2. Search and place all components
3. Use logical groupings:
   - USB-PD input stage (left side)
   - DC-DC converters (center)
   - Linear regulators (right)
   - Output connectors (far right)

**Recommended layout flow:**

```
Left to Right = Signal Flow
USB-C Input → DC-DC Conversion → Linear Regulation → Outputs
```

### 2.3 Wire Connections

1. Press `W` to start wiring
2. Click start point → Click end point
3. Use labels for:
   - Power nets: `+15V`, `+13.5V`, `+12V`, `+5V`, `-12V`, `-15V`
   - Ground: `GND` (use power symbol)
   - Signal names: `PG` (Power Good), `EN` (Enable), `FB` (Feedback)

**Best practices:**

- Use net labels instead of long wires across the page
- Group related components close together
- Keep power flow left-to-right, top-to-bottom
- Add `No Connect` flags (X) to unused pins

### 2.4 Add Power Symbols

1. Press `P` to add power symbols
2. Add for each voltage rail:
   - `+12V`, `+5V`, `-12V` (outputs)
   - `+15V`, `+13.5V`, `-13.5V` (intermediate)
   - `GND` (ground reference)

### 2.5 Add Values and References

For each component:

1. Select component
2. Press `E` to edit properties
3. Set:
   - **Reference** (auto-numbered: U1, R1, C1, etc.)
   - **Value** (10µF, 5.1kΩ, LM7812, etc.)
   - **Footprint** (assigned in next step)
   - **Datasheet URL** (optional but recommended)

### 2.6 Annotate Schematic

Auto-number all reference designators:

1. Tools → Annotate Schematic
2. Select "Use entire schematic" (for multi-sheet projects)
3. Click "Annotate"

**Result:** R?, C?, U? become R1, R2, C1, C2, U1, U2, etc.

### 2.7 Electrical Rules Check (ERC)

Before proceeding to PCB:

1. Inspect → Electrical Rules Checker
2. Run ERC
3. Fix all errors:
   - Unconnected pins
   - Power pins not driven
   - Conflicting outputs
   - Missing power connections

## Stage 3: Footprint Assignment

### 3.1 Import Footprints

**For JLCPCB-compatible parts:**

See [KiCad Parts Download Guide](./kicad-parts-download.md) for detailed instructions.

**Quick workflow:**

```bash
# Download footprint by LCSC ID
easyeda2kicad --lcsc_id C970725 --footprint

# Copy to project directory
cp ~/Documents/Kicad/easyeda2kicad/easyeda2kicad.pretty/*.kicad_mod ./footprints/kicad/
```

### 3.1a Add Footprint Library to KiCad

**IMPORTANT:** Before adding the footprint library, ensure your KiCad project (`.kicad_pro` file) is located in the repository root directory. The `${KIPRJMOD}` variable points to the project file location, so if your project is in a subdirectory (like `kicad/`), the relative paths won't resolve correctly.

**Project structure:**

```
zudo-pd/          ← Repository root
├── zudo-pd.kicad_pro       ← KiCad project file should be here
├── zudo-pd.kicad_sch       ← Schematic file
├── zudo-pd.kicad_pcb       ← PCB file
└── footprints/
    └── kicad/
        └── zudo-power.pretty/   ← Footprint library
            ├── C0603.kicad_mod
            ├── C0805.kicad_mod
            └── ... (37 footprints)
```

**Steps to add footprint library:**

1. **Open Preferences → Manage Footprint Libraries**
   - From main KiCad window (NOT Symbol Editor)
   - Or from PCB Editor: Preferences → Manage Footprint Libraries

2. **Click "Project Specific Libraries" tab** (at bottom)

3. **Add new library:**
   - Click folder icon (➕) to add library
   - Set values:
     - **Nickname**: `zudo-pd` (or any name you prefer)
     - **Library Path**: `${KIPRJMOD}/footprints/kicad/zudo-power.pretty`
     - **Library Format**: `KiCad`
     - **Options**: (leave blank)

4. **Click OK**

**Example configuration:**

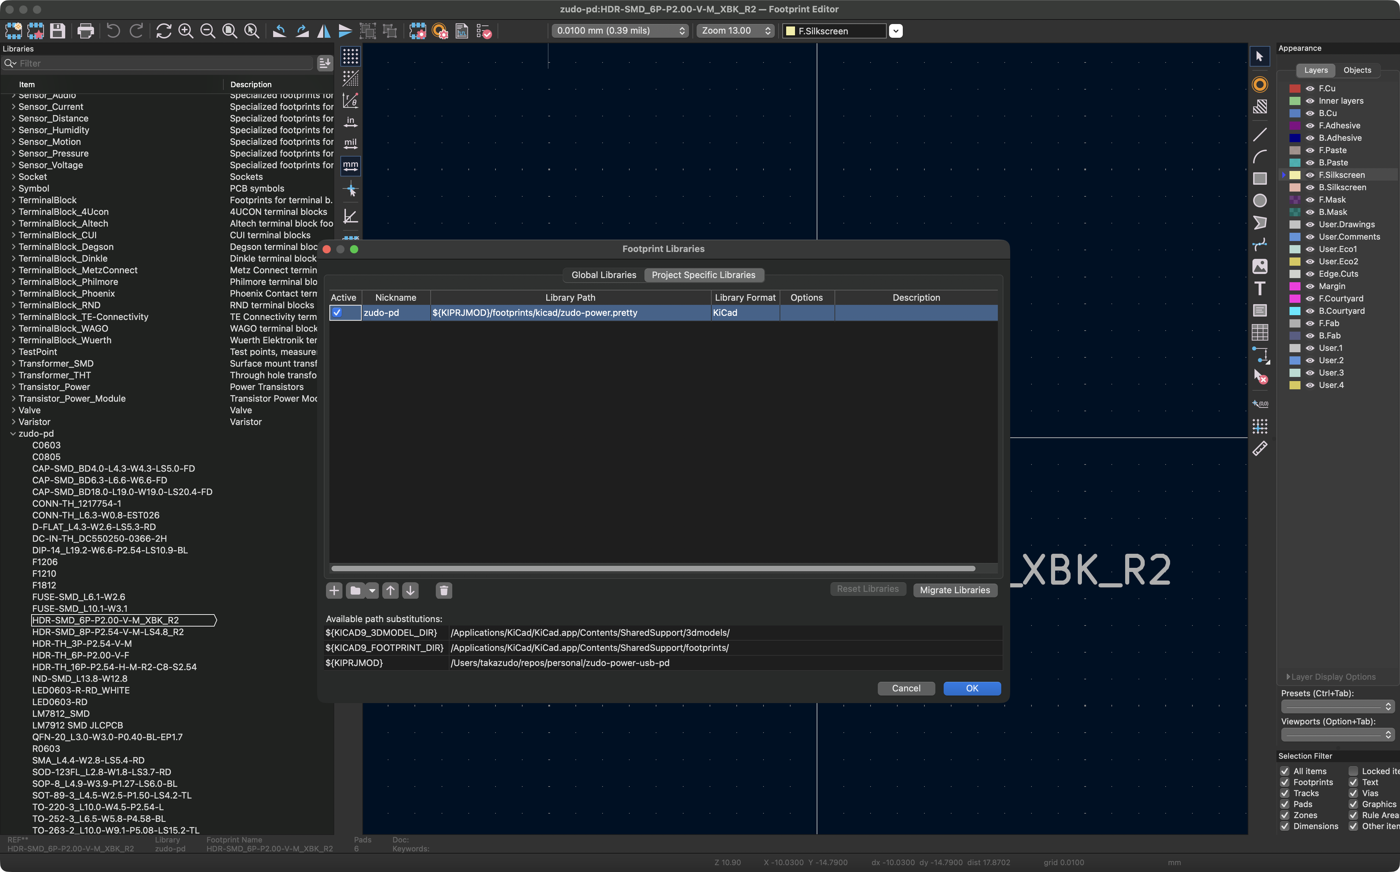
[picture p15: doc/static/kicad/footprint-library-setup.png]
Footprint Library Setup


The dialog should show:

- Library nickname: `zudo-pd`
- Library path: `${KIPRJMOD}/footprints/kicad/zudo-power.pretty`
- At the bottom, "Available path substitutions" shows the resolved path

**Verify the library loaded:**

1. Open **Footprint Editor** (from main KiCad window)
2. Check left panel - you should see `zudo-pd` library
3. Click on it to expand and browse 37 footprints
4. You should see footprints like:
   - `C0603`, `C0805` (capacitors)
   - `TO-252-3`, `TO-263-2` (IC packages)
   - `SOP-8`, `SSOP-10` (IC packages)
   - Component-specific footprints

**Troubleshooting:**

- **Library appears empty:** Verify the path points to `zudo-power.pretty` directory (not `.pretty` or other directories)
- **Path not found:** Check that `${KIPRJMOD}` resolves correctly by looking at "Available path substitutions" at bottom of dialog
- **Wrong symbols showing:** You opened Symbol Libraries instead of Footprint Libraries - close and reopen the correct dialog

### 3.2 Assign Footprints to Symbols

1. In Schematic Editor: Tools → Assign Footprints
2. For each component, select appropriate footprint:
   - **Resistors/Capacitors**: `0805`, `1206` (SMD sizes)
   - **ICs**: Match package type from datasheet (SOIC-8, SOT-23-6, etc.)
   - **Connectors**: Match mechanical dimensions exactly
   - **Large components**: Verify pad sizes for current rating

**Example assignments:**

- LM7812 → `TO-252-2` (DPAK)
- LM2596S → `TO-263-5` (D2PAK)
- CH224Q → `ESSOP-10` (from LCSC)
- 10µF capacitor → `C_0805_2012Metric`
- 5.1kΩ resistor → `R_0805_2012Metric`

### 3.3 Verify Footprint Assignments

1. Check that ALL components have footprints assigned (no "No Footprint" entries)
2. Verify footprint sizes match your requirements:
   - Small passives: 0805 or 1206 (easy hand soldering)
   - ICs: Match JLCPCB assembly capabilities
   - Connectors: Match mechanical specs exactly

## Stage 4: PCB Layout

### 4.1 Generate Netlist and Import to PCB

1. In Schematic Editor: Tools → Update PCB from Schematic (F8)
2. Click "Update PCB"
3. PCB Editor opens with all components loaded

**First import:** Components appear in a cluster, ready to be positioned

### 4.2 Set Board Dimensions

1. Select **Edge.Cuts** layer
2. Draw board outline:
   - Press `Ctrl+Shift+P` for polygon tool
   - Draw rectangle or custom shape
   - Recommended: Start with 100mm × 80mm for this project

### 4.3 Place Components

**Strategic placement:**

1. **Input stage (left):**
   - USB-C connector on board edge
   - CH224Q near connector
   - Input capacitors near CH224Q

2. **DC-DC stage (center):**
   - LM2596S converters in row
   - Inductors next to each converter
   - Output capacitors after inductors

3. **Linear regulators (right of center):**
   - LM7812, LM7805, LM7912 in row
   - Input/output capacitors adjacent

4. **Output connectors (right edge):**
   - Power headers on board edge
   - Fuses before output
   - TVS diodes near output

**Best practices:**

- Keep signal paths short (especially high-current paths)
- Place decoupling capacitors close to IC power pins
- Orient components for logical layout
- Leave space for heat dissipation (regulators, DC-DC)
- Group by function, not just by type

### 4.4 Route Traces

**Layer strategy:**

- **F.Cu (Top layer):** Power traces, signal routing
- **B.Cu (Bottom layer):** Ground plane + additional routing

**Trace widths (for 1oz copper):**

- Power traces (1A+): 0.5mm minimum, 1.0mm recommended
- Signal traces: 0.25mm minimum, 0.3mm recommended
- Ground/return: Wide as possible, or use ground plane

**Routing order:**

1. Route power traces first (+15V, +12V, +5V, -12V)
2. Route critical signals (feedback, enable pins)
3. Route remaining connections
4. Add ground plane on bottom layer (Fill Zone)

**Tools:**

- Press `X` to start routing
- Press `V` to add via (switch layers)
- Press `D` to drag component while maintaining connections

### 4.5 Add Ground Plane

1. Select **B.Cu** layer
2. Press `Ctrl+Shift+Z` to add filled zone
3. Draw zone around entire board
4. Set net: `GND`
5. Press `B` to rebuild all zones

### 4.6 Design Rule Check (DRC)

Before manufacturing:

1. Inspect → Design Rules Checker
2. Run DRC
3. Fix all errors:
   - Trace clearance violations
   - Unconnected nets
   - Board outline issues
   - Silkscreen over pads

## Stage 5: Manufacturing Output

### 5.1 Generate Gerber Files

1. File → Fabrication Outputs → Gerbers (.gbr)
2. Settings:
   - Include layers: F.Cu, B.Cu, F.Mask, B.Mask, F.Silkscreen, B.Silkscreen, Edge.Cuts
   - Coordinate format: 4.6, unit mm
   - Check "Use Protel filename extensions"
3. Click "Plot"

### 5.2 Generate Drill Files

1. File → Fabrication Outputs → Drill Files (.drl)
2. Settings:
   - Drill units: Millimeters
   - Drill map: PostScript or PDF (for verification)
3. Click "Generate Drill File"

### 5.3 Generate BOM (Bill of Materials)

1. In Schematic Editor: File → Fabrication Outputs → BOM
2. Use built-in generator or:
   - Export to CSV
   - Use external tool (KiBoM, InteractiveHtmlBom)

**For JLCPCB assembly:**

- Must include: Reference, Value, Footprint, LCSC Part Number
- Export as CSV format
- Match JLCPCB template exactly

### 5.4 Generate Pick-and-Place File

For SMT assembly:

1. File → Fabrication Outputs → Component Placement (.pos)
2. Format: CSV
3. Units: Millimeters
4. Includes: Reference, X, Y, Rotation, Layer

### 5.5 Verify with Gerber Viewer

1. Open **GerbView** (included with KiCad)
2. Load all Gerber files + drill file
3. Check:
   - Board outline correct
   - All pads visible
   - Silkscreen readable (not over pads)
   - Drill holes aligned with pads
   - Layers aligned correctly

## Stage 6: Order from JLCPCB

### 6.1 Prepare Files

Create ZIP archive with:

- All Gerber files (.gbr)
- Drill file (.drl)
- BOM (CSV format, JLCPCB template)
- Pick-and-place file (CSV format)

```bash
# Example ZIP structure
gerbers.zip
├── F_Cu.gbr
├── B_Cu.gbr
├── F_Mask.gbr
├── B_Mask.gbr
├── F_Silkscreen.gbr
├── B_Silkscreen.gbr
├── Edge_Cuts.gbr
└── drill.drl

bom_jlcpcb.csv
cpl_jlcpcb.csv
```

### 6.2 Upload and Configure

1. Go to [jlcpcb.com](https://jlcpcb.com)
2. Upload gerbers.zip
3. Configure:
   - PCB quantity: 5 (minimum)
   - PCB thickness: 1.6mm (standard)
   - Surface finish: HASL (lead-free) or ENIG (better quality)
   - Copper weight: 1oz (standard for &lt;3A)
4. Add SMT assembly service (optional):
   - Upload BOM + CPL
   - Review component placement
   - Check part availability/substitutions

## Workflow Summary

```
1. Symbol Editor
   ↓
2. Schematic Editor → [ERC Pass] → Assign Footprints
   ↓
3. Update PCB from Schematic
   ↓
4. PCB Editor → Place Components → Route → [DRC Pass]
   ↓
5. Generate Outputs (Gerber, Drill, BOM, CPL)
   ↓
6. Verify in GerbView
   ↓
7. Order from JLCPCB
```

## Troubleshooting

### Common Issues

**Problem:** Symbol not found when placing component

- **Solution:** Add library containing the symbol (Preferences → Manage Symbol Libraries)

**Problem:** Footprint assignment shows "No Footprint"

- **Solution:** Add footprint library (Preferences → Manage Footprint Libraries)

**Problem:** DRC shows "unconnected nets"

- **Solution:** Check for missing wires in schematic, or use "No Connect" flags

**Problem:** Gerber viewer shows misaligned layers

- **Solution:** Check drill origin settings, regenerate Gerbers with correct settings

**Problem:** JLCPCB BOM upload fails

- **Solution:** Verify CSV format matches template, check for special characters

## Next Steps

After completing the KiCad workflow:

1. **Documentation:**
   - Export circuit diagram as SVG (see [Create Circuit SVG Files](./create-circuit-svg.md))
   - Export footprint previews (see [Create Footprint SVG Files](./create-footprint-svg.md))
   - Update parts list with LCSC IDs

2. **Testing plan:**
   - Order PCBs without assembly first
   - Verify board dimensions and mounting holes
   - Check component footprints with actual parts
   - Then order with assembly

3. **Version control:**
   - Commit KiCad project files (.kicad_pro, .kicad_sch, .kicad_pcb)
   - Commit Gerber outputs for reference
   - Tag release versions (v1.0, v1.1, etc.)

## References

- [KiCad Documentation](https://docs.kicad.org/)
- [KiCad Parts Download Guide](./kicad-parts-download.md)
- [JLCPCB SMT Assembly](https://jlcpcb.com/smt-assembly)
- [Create Footprint SVG Files](./create-footprint-svg.md)

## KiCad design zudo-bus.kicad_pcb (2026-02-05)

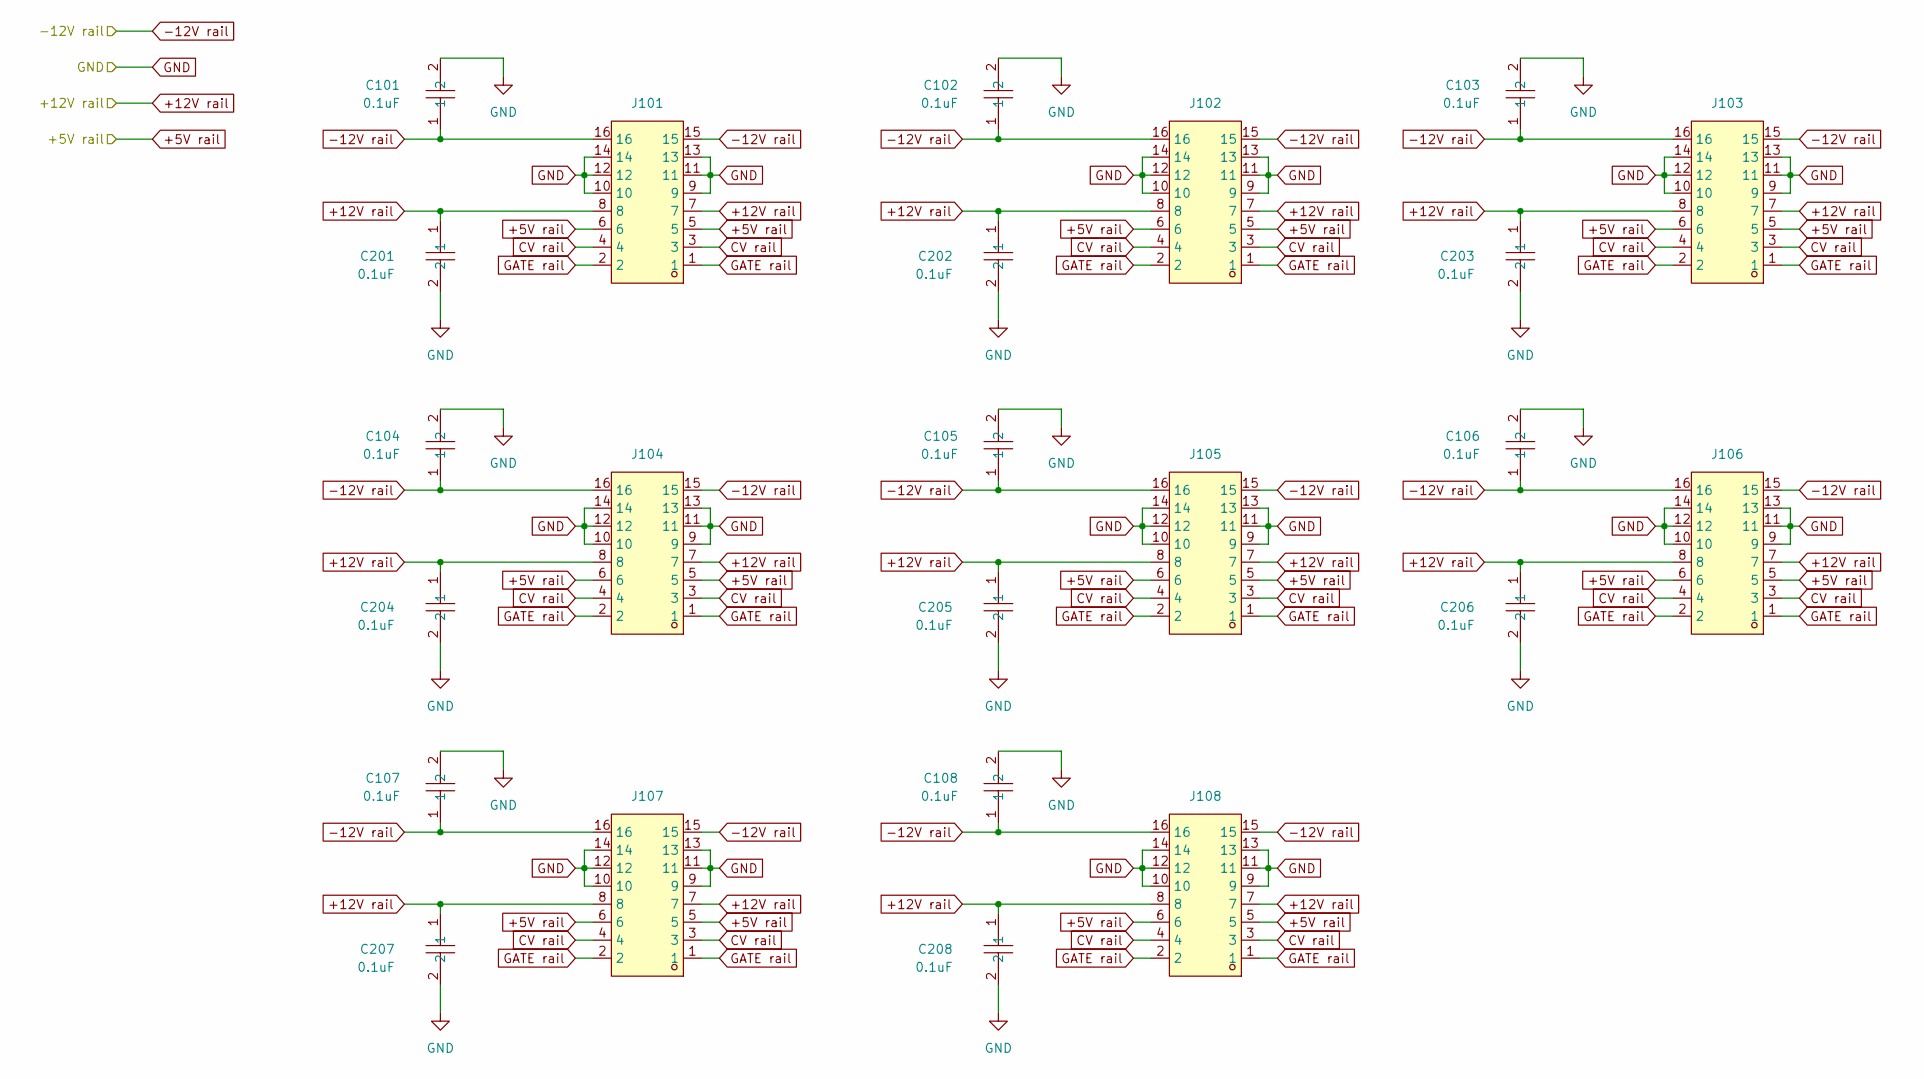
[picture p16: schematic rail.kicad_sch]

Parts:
C101, C102, C103, C104, C105, C106, C107, C108, C201, C202, C203, C204, C205, C206, C207, C208: 0.1uF; C0603; LCSC Part C14663
J101, J102, J103, J104, J105, J106, J107, J108: 2541WR-2X08P; HDR-TH_16P-P2.54-H-M-R2-C8-S2.54; LCSC Part C5383092

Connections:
+5V rail: J101.5, J101.6, J102.5, J102.6, J103.5, J103.6, J104.5, J104.6, J105.5, J105.6, J106.5, J106.6, J107.5, J107.6, J108.5, J108.6; also elsewhere on the board
+12V rail: C201.1, C202.1, C203.1, C204.1, C205.1, C206.1, C207.1, C208.1, J101.7, J101.8, J102.7, J102.8, J103.7, J103.8, J104.7, J104.8, J105.7, J105.8, J106.7, J106.8, J107.7, J107.8, J108.7, J108.8; also elsewhere on the board
-12V rail: C101.1, C102.1, C103.1, C104.1, C105.1, C106.1, C107.1, C108.1, J101.15, J101.16, J102.15, J102.16, J103.15, J103.16, J104.15, J104.16, J105.15, J105.16, J106.15, J106.16, J107.15, J107.16, J108.15, J108.16; also elsewhere on the board
CV rail: J101.3, J101.4, J102.3, J102.4, J103.3, J103.4, J104.3, J104.4, J105.3, J105.4, J106.3, J106.4, J107.3, J107.4, J108.3, J108.4
GATE rail: J101.1, J101.2, J102.1, J102.2, J103.1, J103.2, J104.1, J104.2, J105.1, J105.2, J106.1, J106.2, J107.1, J107.2, J108.1, J108.2
GND: C101.2, C102.2, C103.2, C104.2, C105.2, C106.2, C107.2, C108.2, C201.2, C202.2, C203.2, C204.2, C205.2, C206.2, C207.2, C208.2, J101.9, J101.10, J101.11, J101.12, J101.13, J101.14, J102.9, J102.10, J102.11, J102.12, J102.13, J102.14, J103.9, J103.10, J103.11, J103.12, J103.13, J103.14, J104.9, J104.10, J104.11, J104.12, J104.13, J104.14, J105.9, J105.10, J105.11, J105.12, J105.13, J105.14, J106.9, J106.10, J106.11, J106.12, J106.13, J106.14, J107.9, J107.10, J107.11, J107.12, J107.13, J107.14, J108.9, J108.10, J108.11, J108.12, J108.13, J108.14; also elsewhere on the board

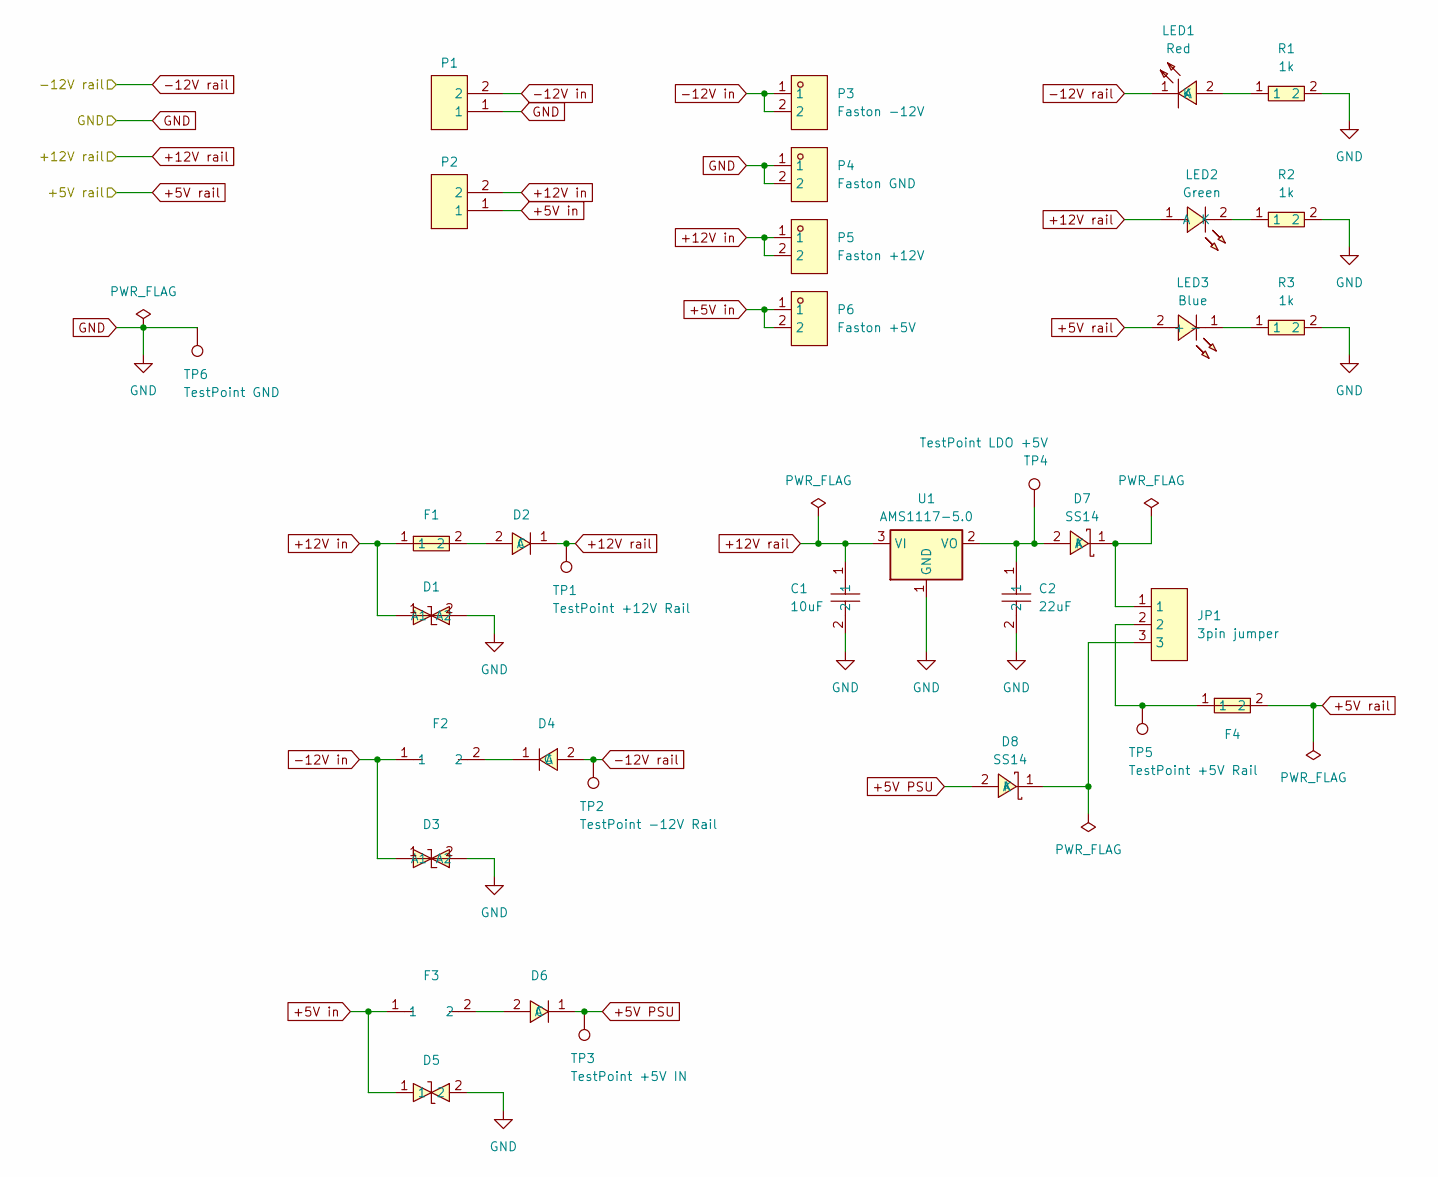
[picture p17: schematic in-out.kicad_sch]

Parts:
C1: 10uF; C0805; LCSC Part C15850
C2: 22uF; C0805; LCSC Part C45783
D1, D3: SMF12CA_C353317; SOD-123FL_L2.8-W1.8-LS3.7-BI; LCSC Part C353317
D2, D4, D6: SM4007PL; SOD-123F_L2.8-W1.8-LS3.7-RD; LCSC Part C64898
D5: SMF5.0CA_C908214; SOD-123FL_L2.8-W1.8-LS3.7-BI; LCSC Part C908214
D7, D8: SS14; SMA_L4.2-W2.6-LS5.0-RD_1; LCSC Part C2480
F1: BSMD1812-200-30V; F1812; LCSC Part C960026
F2, F3: BSMD1812-150-33V; F1812; LCSC Part C883154
F4: BSMD1812-110-33V; F1812; LCSC Part C883150
JP1: 3pin jumper; HDR-TH_3P-P2.54-V-M-1; LCSC Part C49257
LED1: Red; LED0603-RD; LCSC Part C2286
LED2: Green; LED0603-FD; LCSC Part C19171392
LED3: Blue; LED0603-RD; LCSC Part C5382145
P1, P2: WJ500V-5.08-2P-14-00A; CONN-TH_2P-P5.00_WJ500V-5.08-2P; LCSC Part C8465
P3: Faston -12V; CONN-TH_1217754-1; LCSC Part C305825
P4: Faston GND; CONN-TH_1217754-1; LCSC Part C305825
P5: Faston +12V; CONN-TH_1217754-1; LCSC Part C305825
P6: Faston +5V; CONN-TH_1217754-1; LCSC Part C305825
R1, R2, R3: 1k; R0805; LCSC Part C25623
TP1: TestPoint +12V Rail; TestPoint_Pad_D1.5mm
TP2: TestPoint -12V Rail; TestPoint_Pad_D1.5mm
TP3: TestPoint +5V IN; TestPoint_Pad_D1.5mm
TP4: TestPoint LDO +5V; TestPoint_Pad_D1.5mm
TP5: TestPoint +5V Rail; TestPoint_Pad_D1.5mm
TP6: TestPoint GND; TestPoint_Pad_D1.5mm
U1: AMS1117-5.0; SOT-223-3_TabPin2

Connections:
+5V PSU: D6.1 (C), D8.2 (A), TP3.1
+5V in: D5.1, F3.1, P2.1, P6.1, P6.2
+5V rail: F4.2, LED3.2 (+); also elsewhere on the board
+12V in: D1.1 (A2), F1.1, P2.2, P5.1, P5.2
+12V rail: C1.1, D2.1 (C), LED2.1 (A), TP1.1, U1.3 (VI); also elsewhere on the board
-12V in: D3.1 (A2), F2.1, P1.2, P3.1, P3.2
-12V rail: D4.2 (A), LED1.1 (K), TP2.1; also elsewhere on the board
GND: C1.2, C2.2, D1.2 (A1), D3.2 (A1), D5.2, P1.1, P4.1, P4.2, R1.2, R2.2, R3.2, TP6.1, U1.1 (GND); also elsewhere on the board
unnamed: D2.2 (A), F1.2
unnamed: D4.1 (C), F2.2
unnamed: D6.2 (A), F3.2
unnamed: C2.1, D7.2 (A), TP4.1, U1.2 (VO)
unnamed: D7.1 (K), JP1.1
unnamed: D8.1 (K), JP1.3
unnamed: F4.1, JP1.2, TP5.1
unnamed 17: LED1.2 (A), R1.1; also elsewhere on the board
unnamed 18: LED2.2 (K), R2.1; also elsewhere on the board
unnamed 19: LED3.1 (-), R3.1; also elsewhere on the board

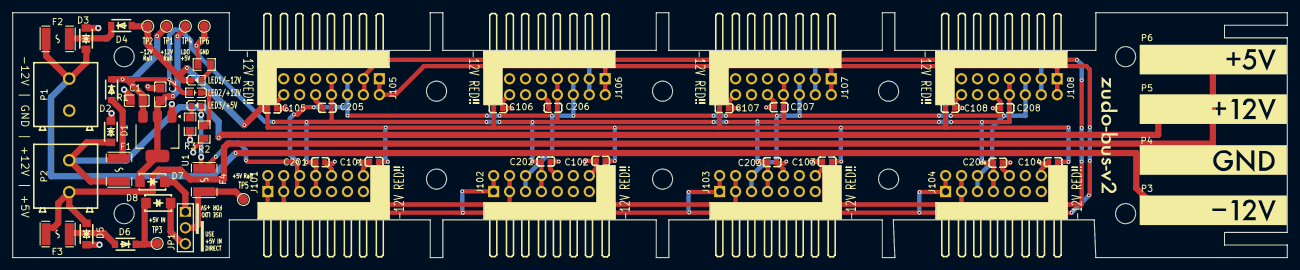
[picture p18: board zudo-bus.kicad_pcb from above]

Board: 2 copper layers, 203.0 x 39.0 mm, 58 parts (0 on the bottom side), 20 nets.

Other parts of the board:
LED1/-12V: Red; LED0603-RD
LED2/+12V: Green; LED0603-FD
LED3/+5V: Blue; LED0603-RD

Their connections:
+5V rail: LED3/+5V.2 (+); also elsewhere on the board
+12V rail: LED2/+12V.1 (A); also elsewhere on the board
-12V rail: LED1/-12V.1 (K); also elsewhere on the board
unnamed 17: LED1/-12V.2 (A); also elsewhere on the board
unnamed 18: LED2/+12V.2 (K); also elsewhere on the board
unnamed 19: LED3/+5V.1 (-); also elsewhere on the board

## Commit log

2026-01-12 Add project configuration and documentation files
    - Add GitHub workflows for Netlify deployment
    - Add .gitignore for Node.js and KiCad projects
    - Add CLAUDE.md with project instructions
    - Add readme.md with project overview
2026-01-12 Add KiCad project files
    Initial schematic and PCB layout for zudo-bus Eurorack bus board.
    [zudo-bus.kicad_pcb, zudo-bus.kicad_sch]
2026-01-12 Add KiCad footprints and symbols libraries
    Downloaded from LCSC/EasyEDA using easyeda2kicad:
    - CONN-TH_1217754-1 (FASTON terminal)
    - CONN-TH_2P-P5.00_WJ500V-5.08-2P (Screw terminal)
    - HDR-TH_16P-P2.54-H-M-R2-C8-S2.54 (16-pin IDC header)
    - HDR-TH_3P-P2.54-V-M-1 (3-pin header)
    - SOT-89-3_L4.5-W2.5-P1.50-LS4.1-BR-1 (78L05 LDO)
    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
2026-01-12 Add Docusaurus documentation site
    Complete documentation for zudo-bus Eurorack bus board:
    - Project overview and technical specifications
    - Bill of Materials with LCSC part numbers
    - Component datasheets and footprint previews
    - How-to guides for KiCad library management
    - Docusaurus configuration with Netlify deployment
    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
2026-01-12 Fix broken link to footprint-preview page
    Remove .md extension from internal link since Docusaurus uses
    the route path without file extensions.
2026-01-12 Add comprehensive protection circuitry to bus board design
    - Add +5V reverse polarity protection (D3)
    - Add TVS transient protection diodes (TVS1/TVS2 SMF15CA for ±12V, TVS3 SMF5.0CA for +5V)
    - Add PTC resettable fuses (F1/F2 2A for ±12V, F3 1.5A for +5V)
    - Add input bulk capacitors (C5/C6 10µF for ±12V rails)
    - Add per-header decoupling capacitors (C7-C14 0.1µF x8)
    - Add KiCad footprints: F1812, C0805, SOD-123 bidirectional
    - Add KiCad symbol library for protection components
    - Update BOM with JLCPCB part numbers and KiCad references
    - Update circuit design documentation with protection details
2026-01-12 Replace 78L05 with AMS1117-5.0 LDO for higher current capacity
    - Replace 78L05 (100mA, SOT-89-3) with AMS1117-5.0 (1A, SOT-223)
    - Add MDX fragment system for shared circuit diagrams
    - Update circuit-diagrams.mdx to use shared LDO fragment
    - Add comprehensive AMS1117-5.0 component documentation
    - Update BOM and current-status with new component specs
    - Add SOT-223 KiCad footprint and symbol
    - Regenerate footprint SVGs
    - Link Netlify project
    Key changes:
    - 10x higher current capacity (1A vs 100mA)
    - Lower dropout voltage (1.2V vs 2V)
    - Requires 22µF low-ESR output capacitor for stability
    - Practical thermal limit ~300mA from 12V input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
2026-01-12 Improve circuit design based on review feedback
    - Update protection order: Input → PTC → TVS → Reverse Diode → Bulk Caps
    - Add D4 reverse protection diode for LDO output path
    - Add test points TP1-TP6 for debugging
    - Increase bulk capacitors C5, C6 from 10µF to 22µF
    - Add per-header -12V decoupling capacitors C15-C22
    - Standardize LED resistors to 1kΩ 0805 (same as zudo-power-usb-pd)
    - Fix L78L05 → AMS1117 documentation inconsistency
    - Add 2-layer PCB design note
2026-01-12 Update footprints and symbols for AMS1117 LDO
    - Replace SOT-89 footprint with SOT-223 for AMS1117
    - Add Samsung capacitor symbols library
    - Fix EnlargeButton to use useBaseUrl hook
2026-01-12 Use working deploy-netlify action from zudo-power-usb-pd
    Remove netlify link step and whitespace trimming - use simpler
    approach that works in reference project.
2026-01-12 Remove REF** placeholder text from footprint SVG files
    Ran clean-svg-refs.py script on all 14 footprint SVGs to remove
    KiCad REF** and VAL** placeholder text elements.
2026-01-12 Add protection circuits, decoupling, and test points to circuit diagrams
    - Update system block diagram with full protection chain and decoupling
    - Add Protection Circuit Order section showing PTC → TVS → Diode → Caps
    - Add TVS Transient Protection diagram with SMF15CA/SMF5.0CA specs
    - Add PTC Overcurrent Protection diagram with BSMD1812 specs
    - Add Per-Header Decoupling diagram (C7-C14 for +12V, C15-C22 for -12V)
    - Add Test Points section (TP1-TP6) with usage notes
    - Update reverse protection to include D3, D4 for +5V paths
2026-01-12 Improve per-header decoupling diagram readability
    - Use vertical branch style diagram matching LDO capacitor diagrams
    - Add clear capacitor assignment table (J1-J8 → C7-C14, C15-C22)
    - Show +12V and -12V rail decoupling separately
    - Add placement note for close-to-header positioning
2026-01-12 Fix LDO reference from L78L05 to AMS1117 in system diagram
    The zudo-bus uses AMS1117-5.0 for +5V regulation, not L78L05.
2026-01-12 Add C23 (+5V bulk capacitor) to component documentation
    Add 22µF bulk capacitor (C23) for +5V rail filtering:
    - Placed after JP1 Pin 2 (works with both LDO and PSU direct modes)
    - Update component count from 24 to 25 passives (~57 to ~58 total)
    - Add note clarifying F3 fuse position is after JP1 Pin 2
2026-01-12 Improve LED indicator and PTC fuse circuit diagrams
    LED indicator circuit:
    - Show LED1 (-12V) separate topology (current flows from GND to -12V)
    - Add polarity indicators (A → K) for all LEDs
    - Add current calculation formulas for each LED
    PTC fuse section:
    - Clarify F3 is placed after JP1 Pin 2
    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
2026-01-12 Add power cable recommendations documentation
    New documentation page covering:
    - Recommended wire gauge (18 AWG) for PSU to bus board connections
    - Current requirements per rail with safety margins
    - Cable construction and color coding guidelines
    - FASTON 250 and screw terminal connection guidance
    - Cable length recommendations with voltage drop calculations
2026-01-12 Improve circuit protection design based on review
    Major design changes from circuit review:
    +5V Backfeed Protection:
    - Add SS14 Schottky diodes (D5, D6) in OR-ing configuration
    - Prevents damage if both LDO and PSU +5V sources connected
    - Uses C2480 (40V 1A, SMA package, 1.09M stock)
    LDO Input Protection:
    - Add F4 (BSMD1812-110-33V, 1.1A hold) PTC fuse before LDO
    - Provides symmetric protection for LDO input path
    - Limits current if LDO shorts internally
    TVS Diode Improvement:
    - Replace SMF15CA with SMF12CA (C353317) for ±12V rails
    - Clamping voltage reduced from 24.4V to 19.9V
    - Safer for module op-amps (typically rated 15-18V abs max)
    Power Sequencing:
    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
2026-01-12 Add missing KiCad symbols and footprints for circuit design updates
    Downloads and organizes KiCad resources from JLCPCB to match the latest
    circuit design:
    New symbol library (zudo-bus-new-protection.kicad_sym):
    - SMF12CA_C353317: TVS diode 12V (replaces SMF15CA for safer clamping)
    - BSMD1812-110-33V: PTC fuse 1.1A for LDO input protection
    - SS14: Schottky diode 40V 1A for +5V OR-ing protection
    - CL21A226MAQNNNE: 22µF bulk capacitor
    New footprints:
    - SOD-123FL_L2.8-W1.8-LS3.7-BI.kicad_mod: For SMF12CA TVS diodes
    - SMA_L4.2-W2.6-LS5.0-RD_1.kicad_mod: For SS14 Schottky diodes
    - R0805.kicad_mod: For 1kΩ LED resistors
    Updates BOM documentation with:
    - Corrected KiCad library organization
    -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
2026-01-18 Add KiCad gitignore patterns and schematic workflow docs
    - Add KiCad temporary files to .gitignore (*-backups/, *.kicad_prl, etc.)
    - Add KiCad schematic editing guidelines to CLAUDE.md
    - Document GUI-first workflow for complex schematic changes
2026-01-18 Add hierarchical schematic with power distribution circuits
    Schematic structure:
    - zudo-bus.kicad_sch: Root with hierarchical sheet references
    - in-out.kicad_sch: Power input, protection, LDO, and status LEDs
    - rail.kicad_sch: IDC header distribution with decoupling capacitors
    Components added:
    - P1/P2: Screw terminals for ±12V/GND input
    - F1-F4: PTC fuses for overcurrent protection
    - D1-D6: TVS and reverse polarity diodes
    - D7/D8: Schottky OR-ing diodes for +5V selection
    - U1: AMS1117-5.0 LDO regulator
    - JP1: 3-pin jumper for +5V source selection
    - LED1-LED3: Status indicators with R1-R3 current limiting
    - J101-J108: 16-pin IDC headers with C101-C208 decoupling caps
    - P3-P6: FASTON termin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
    [in-out.kicad_sch, rail.kicad_sch, zudo-bus.kicad_sch]
2026-01-18 Add circuit diagram documentation with 8 detailed diagrams
    circuit-diagrams.mdx:
    - Diagram1: Power input (P1/P2 screw terminals)
    - Diagram2: +12V protection (F1 → D1 TVS → D2 reverse)
    - Diagram3: -12V protection (F2 → D3 TVS → D4 reverse)
    - Diagram4: +5V PSU protection (F3 → D5 TVS → D6 reverse)
    - Diagram5: +5V selection (U1 LDO, D7/D8 OR-ing, JP1, F4)
    - Diagram6: FASTON chaining outputs (P3-P6)
    - Diagram7: IDC distribution (J101-J108 with decoupling caps)
    - Diagram8: Status LEDs (LED1-LED3 with R1-R3)
    Each diagram includes ASCII art, component tables, and net connections.
    bom.md:
    - Update fuse descriptions (F3: PSU input, F4: rail output)
    - Add component references matching sc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
2026-01-18 Add KiCad schematic editing guide
    New documentation for programmatic KiCad schematic editing:
    - File structure reference (.kicad_sch format)
    - Symbol and wire coordinate systems
    - Global label positioning and direction
    - Best practices for labels and wires
    - Common pitfalls and troubleshooting
    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
2026-02-04 Add test points (TP1-TP6) to schematic and documentation
    Schematic test points added for debugging and verification:
    - TP1: +12V rail (after D2)
    - TP2: -12V rail (after D4)
    - TP3: +5V PSU input (after D6, before D8)
    - TP4: LDO +5V output (U1 output, before D7)
    - TP5: +5V rail (JP1 pin 2, before F4)
    - TP6: GND reference
    Also fixed LED1/LED2 polarity (was reverse biased).
    Documentation updates:
    - circuit-diagrams.mdx: Add Diagram9 for test points
    - bom.md: Update test points table with correct locations
    [in-out.kicad_sch]
2026-02-04 Add 3D models and fix footprint paths for KiCad 3D viewer
    - Add 51 3D models (.wrl/.step) to footprints/3dshapes/
    - Update all footprint files to use ${KIPRJMOD}/footprints/3dshapes/
    - Add fp-lib-table to map library names to project footprints
    - Fix broken footprint paths in schematic (zudo-bus:F1812, etc.)
    - Add TestPoint footprints to TP1-TP6 in schematic
    - Update .gitignore to exclude report.txt
    [C0603_L1.6-W0.8-H0.8.step, C0805_L2.0-W1.3-H1.3.step, C1206_L3.2-W1.6-H1.3.step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]
2026-02-04 Update KiCad schematic and PCB layout
    - Adjust IDC header positions and rotations in rail schematic
    - Update PCB layout with component placements
    - Update project configuration
    [rail.kicad_sch, zudo-bus.kicad_pcb]
2026-02-05 Add custom footprints and update PCB layout
    - Add eurorack-power-16pin footprint with custom silkscreen
    - Add power-faston-pin footprint for FASTON connectors
    - Add design resource file (zudo-bus-svg.ai)
    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
    [zudo-bus.kicad_pcb]
2026-02-05 docs: Update BOM to match actual v2 design
    - Update capacitor list: C1=10µF, C2=22µF, C101-C208=0.1µF (removed C3-C6, C23)
    - Fix F2 fuse spec: BSMD1812-150-33V (was incorrectly listed as 200-30V)
    - Update component counts in summary table
    - Update footprint table with custom footprints (eurorack-power-16pin, power-faston-pin)
    - Fix diode designator references (D7, D8 for Schottky)
2026-02-05 Add JLCPCB order files for v2 production
    - Add gerbers, BOM with LCSC numbers, and CPL for JLCPCB assembly
    - Update KiCad project files
    [jlcpcb-bom-with-lcsc.csv, jlcpcb-bom.csv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]
